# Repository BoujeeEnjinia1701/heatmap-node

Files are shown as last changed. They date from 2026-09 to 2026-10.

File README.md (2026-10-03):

# HeatMap Node

     

**Area:** Smart Cities · **TRL:** 3 of 9 (proof of concept on paper) · **Value-engineering target:** USD 130 for the sensor head; estimated cost of the constructable design USD 136 (FieldNode core and its pole adapter counted separately) · **Difficulty:** 2 of 5

A street-level heat and humidity node that measures heat stress (including a globe temperature) to map urban heat islands block by block.

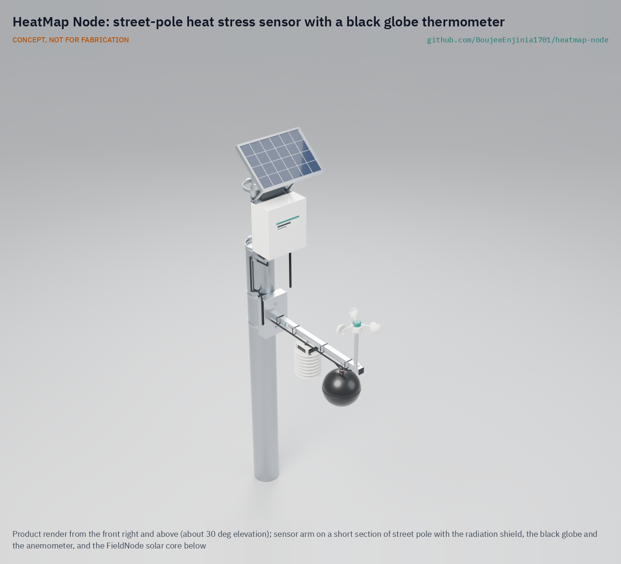
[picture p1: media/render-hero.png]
HeatMap Node: street-pole heat stress sensor with a black globe thermometer, product render


[Exploded render](media/render-exploded.png) · [Detail render](media/render-detail.png) · [Interactive 3D model](media/viewer.html) · [Concept blueprint (PDF)](media/concept-blueprint.pdf) · [General arrangement (PDF)](cad/drawings/HMN-DWG-001.pdf) · [Calculations](docs/04-calcs/01-sizing.md) · [Prototype build plan](docs/05-build-plan.md) · [Design decisions](docs/06-design-decisions.md) · [Review note](docs/REVIEW.md)

## Concept rationale

Block-level heat data lets a city put shade, trees, cool surfaces and cooling centers where they protect the most people, and then check whether they worked. Air temperature alone misses what makes a sunny street dangerous: radiant heat from the sun and from hot walls and pavement. HeatMap Node therefore measures what is needed to estimate the standard heat stress index, wet bulb globe temperature (WBGT, [ISO 7243:2017](https://www.iso.org/standard/67188.html)): air temperature, humidity, a black globe temperature and wind. WBGT is then estimated with a published open method ([Liljegren et al., 2008](https://doi.org/10.1080/15459620802310770)) instead of a wetted wick that would need refilling at every pole.

It is open and garage-buildable because mapping heat block by block takes many nodes, and the hottest neighborhoods are often the ones with the least money to buy them. The sensor head is a copper float ball, printed shield plates, an aluminium tube and off-the-shelf sensors, and it plugs into the lab's shared FieldNode core for solar power and LoRaWAN radio. Community groups, schools and cities can build, calibrate (with CalRig) and audit the same design, and the data stays open.

## Burning platform

WHO estimates about 489,000 heat-related deaths each year between 2000 and 2019, 45 % of them in Asia and 36 % in Europe ([WHO](https://www.who.int/news-room/fact-sheets/detail/climate-change-heat-and-health)). In one summer, 2022, an estimated 61,672 people died of heat across 35 European countries ([Ballester et al., *Nature Medicine*, 2023](https://www.nature.com/articles/s41591-023-02419-z)).

Cities concentrate the risk and spread it unevenly. The US EPA reports urban daytime temperatures about 1 to 7 °F (about 0.5 to 4 °C) above outlying areas ([US EPA](https://www.epa.gov/heatislands/learn-about-heat-islands)). Formerly redlined US neighborhoods have land surface temperatures about 2.6 °C higher than other neighborhoods, and up to 7 °C higher in some cities ([Hoffman et al., 2020](https://www.mdpi.com/2225-1154/8/1/12)). Official stations are too few to see these block-to-block differences, and satellites measure surfaces, not the heat a person on the pavement feels.

## Where it could be used

### By industry

| Industry | Use |
| --- | --- |
| Municipal climate and urban forestry | Target tree planting, shade (with CoolShade) and cool surfaces block by block, and measure the effect before and after |
| Public health | Neighborhood heat stress during heat waves to direct outreach and cooling center hours |
| Construction and outdoor work | Local WBGT estimates for work and rest planning on and near sites |
| Transit and school operators | Heat stress at bus stops, platforms and schoolyards |
| Urban design and real estate | Evidence for street and building design choices that reduce radiant heat |
| Research and education | A calibrated, repeatable street-level method for heat studies and classroom science |

### By country or region

| Country or region | Why it matters there |
| --- | --- |
| United States | In all but 6 of the 175 largest urbanized areas, the average person of color lives in a census tract with higher surface urban heat island intensity than non-Hispanic white residents ([Hsu et al., 2021](https://www.nature.com/articles/s41467-021-22799-5)) |
| Europe | About 61,672 heat-related deaths in summer 2022 across 35 countries ([Ballester et al., 2023](https://www.nature.com/articles/s41591-023-02419-z)); dense cities with older, unshaded streets need local evidence for cooling plans |
| South and Southeast Asia | Asia accounts for about 45 % of global heat-related deaths ([WHO](https://www.who.int/news-room/fact-sheets/detail/climate-change-heat-and-health)); rapidly growing cities include informal settlements that WHO notes are often hotter than other urban areas |
| Sub-Saharan Africa | Africa warmed by about 0.3 °C per decade over 1991 to 2022, and WMO describes big gaps in weather observations there ([WMO](https://wmo.int/news/media-centre/africa-suffers-disproportionately-from-climate-change)); low-cost nodes can add street-level data where stations are few |
| North Africa and the Middle East | WMO reports particularly rapid warming and extreme heat in North Africa ([WMO](https://wmo.int/news/media-centre/africa-suffers-disproportionately-from-climate-change)); outdoor workers and dense old cities face high radiant loads |

## What sparked the idea

The idea traces back to US Marine Corps training sites in the late 1940s and early 1950s. Heat flags were introduced there to address high rates of heat illness, but the temperature readings behind them did not account for sunlight or wind ([Human Performance Resource Center, US Department of Defense](https://www.hprc-online.org/physical-fitness/environmental-extremes/military-heat-flag-conditions-explained)). Yaglou and Minard's answer in 1957 was wet bulb globe temperature, which adds a black globe to catch the sun, and a review of the index's history records that it cut both heat casualties and lost training time ([Budd, *Journal of Science and Medicine in Sport*, 2008](https://doi.org/10.1016/j.jsams.2007.07.003)). HeatMap Node takes the same black globe, wind reading and shaded air temperature off the training ground and onto city street poles, where the neighborhoods hit hardest by heat are often the least measured.

## Problem

Heat waves kill more people than most other weather hazards, and cities lack fine-grained data on where heat is worst. Full problem statement: [docs/01-problem.md](docs/01-problem.md).

## Concept

A sensor arm clamps to an existing street pole with its axis at 2.8 m, points toward the equator and plugs into a FieldNode core (solar panel, LiFePO4 cell, LoRaWAN radio, and a sun shield for hot sites) mounted above it. It carries a fan-aspirated radiation shield with a temperature and humidity sensor, a standard 150 mm black globe with a thermistor at its center, and a small cup anemometer. Every 3 min the fan runs for 6 s before the air is read. Nodes send 15 min means; a server computes mean radiant temperature and WBGT, flags calm intervals below the anemometer's start-up, and maps the results block by block. Only environmental values leave the node: no camera, microphone or personal data.

TRL 3 calculations ([HMN-CAL-001](docs/04-calcs/01-sizing.md)): in a worked example, 35 °C air at 40 %RH with a 50 °C globe at 1 m/s gives a mean radiant temperature of 74.8 °C and WBGT of 31.7 °C. With the fan the shield reads 0.43 °C high in full sun at any wind speed (1.04 °C at 1 m/s without it), and the sensor input errors add up to ±0.30 °C of WBGT. The sensors and fan draw 35 mW against FieldNode's 100 mW allowance, the sensor head weighs 2.12 kg, and the arm has a factor of 13.0 on yield in a 35 m/s gust. Not met on paper: pedestrian measurement height (sensors at about 2.7 m). Value-engineering target: USD 130. Estimated cost of the constructable sensor head: USD 136 (USD 6 over the target); the full node with the FieldNode core, sun shield and pole adapter is about USD 292. WBGT accuracy against a reference meter, installation time and calibration of the assembled globe are at risk. With the arm toward the equator, the sensor head shades part of the FieldNode panel near noon; a fix is awaiting review.

Full design precis: [docs/02-concept.md](docs/02-concept.md). Requirements: [docs/03-requirements.md](docs/03-requirements.md).

## Key components

1. FieldNode core with its hot-climate sun shield (enclosure, 6 W panel, LiFePO4 cell, LoRaWAN radio)
2. Multi-plate radiation shield
3. Air temperature and humidity sensor (SHT45)
4. Black globe, 150 mm copper sphere, matte black
5. Globe temperature probe (NTC at the center)
6. Cup anemometer
7. Sensor arm, 25 mm aluminium tube
8. Arm clamp: formed sheet 120° V-saddle with stainless strap bands for 60 to 200 mm poles
9. Sensor harness with M12 plugs
10. Hardware and consumables
11. Secondary retention lanyards for the globe and shield
12. Pole adapter that seats the FieldNode core on street poles
13. Aspiration fan and cowl on the shield

The working bill of materials is in [bom/bom.csv](bom/bom.csv).

## Building the prototype

The design is now constructable: every part can be cut, bent, drilled, printed or bought, and every part fits and fastens to the next ([HMN-DDR-003](docs/decisions/0003-design-for-construction.md)). The [prototype build plan](docs/05-build-plan.md) shows how to make the bent sheet saddle, the arm cheeks, the drilled arm and the printed shield plates, cowl and pole adapter blocks, and how to put the sensor head together on the bench in twelve steps before it goes on the pole above a FieldNode core built to its own plan. Every component and step has a picture drawn from the model. Decisions still open are in the [design decisions register](docs/06-design-decisions.md). It is a plan; nothing has been built yet.

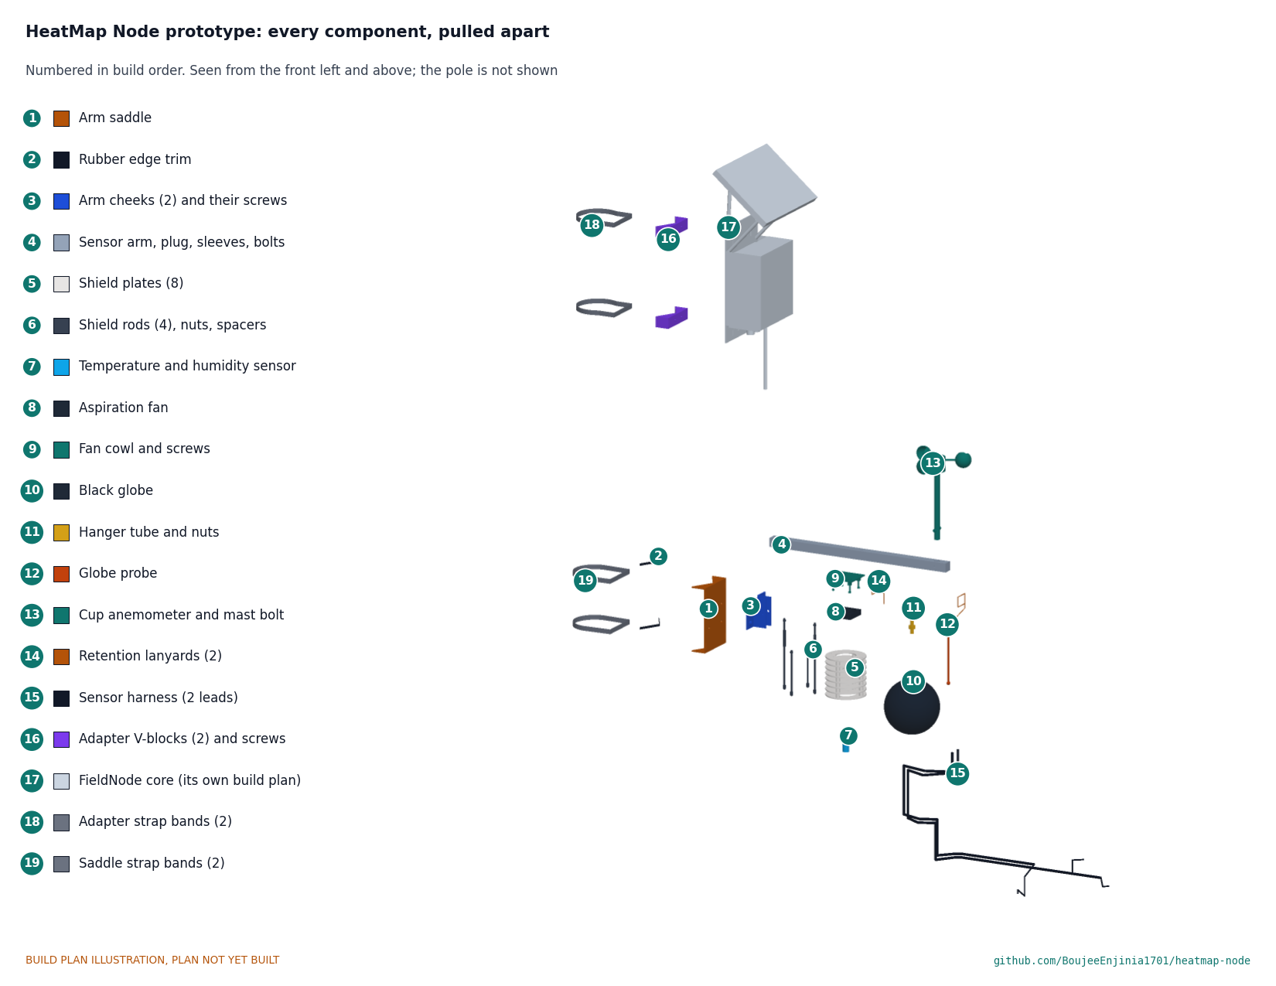
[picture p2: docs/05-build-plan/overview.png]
Every component of the HeatMap Node prototype, pulled apart and numbered in build order


## Safety

> Street furniture and pole mounts must be installed only with the asset owner's permission, by trained crews, with fall protection and traffic management as local rules require. Keep clear of overhead power lines and live parts of lighting poles.
>
> The FieldNode core contains a LiFePO4 cell: fuse it, charge only within the maker's temperature limits and never install a damaged or wet cell. The black globe and arm get hot in the sun (about 67 °C at 50 °C air, HMN-CAL-001), the anemometer cups spin, and the shield fan starts on its own every 3 min; unplug the sensor lead before working on it. The globe and shield are backed by stainless lanyards so that a failed fixing does not drop them onto the street.
>
> HeatMap Node data is for planning and research, not an official heat warning.

## Repository layout

| Folder | Contents |
| --- | --- |
| `docs/` | Problem, concept, requirements, calculations and design decisions |
| `cad/src/` | build123d Python source, the source of truth for all geometry |
| `cad/step/`, `cad/stl/` | Exported models for FreeCAD, other CAD tools and printing |
| `cad/drawings/` | 2D sketches and dimensioned drawings |
| `bom/` | Bill of materials |
| `electronics/` | KiCad schematics and PCB layouts |
| `firmware/` | Microcontroller code |
| `media/` | Renders, perspectives and photos |
| `build-log/` | Dated prototyping notes |

## Documentation

Controlled documents follow the portfolio [documentation standard](.kit/STANDARDS.md). Each carries a document ID (HMN-PRC-001 for the precis), a version and a revision history. Branded PDFs are built with `python .kit/render.py` and attached to GitHub Releases when a document is tagged, for example `HMN-PRC-001/v1.0`.

## Credits

Designed by Amish Chadha. See [CONTRIBUTORS.md](CONTRIBUTORS.md) for roles. To cite this design, use [CITATION.cff](CITATION.cff) (GitHub shows it as "Cite this repository").

AI assistance (Claude) was used to accelerate concept renders, prototype documentation and first-pass sizing calculations. Design direction and all decisions are Amish Chadha's, recorded in this repository's decision records (`docs/decisions/`).

## Licenses

- **Hardware** (CAD, drawings, BOM, electronics): [CERN-OHL-S v2](LICENSE)
- **Software** (firmware, scripts, notebooks): [MIT](LICENSE-SOFTWARE)

A project of the [Design Molecule](https://designmolecule.com) lab.

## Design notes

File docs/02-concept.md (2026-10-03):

---
doc_id: HMN-PRC-001
title: HeatMap Node design precis
project: HeatMap Node
doc_type: Design precis
version: "0.8"
status: Draft
date: '2026-10-02'
author: Amish Chadha
license: CERN-OHL-S-2.0
revisions:
- version: "0.1"
  date: '2026-09-25'
  author: Amish Chadha
  change: Initial scaffold
- version: "0.2"
  date: '2026-09-25'
  author: Amish Chadha
  change: Populate to TRL 2 (architecture, components, first-order numbers, safety, media, open questions)
- version: "0.3"
  date: '2026-09-25'
  author: Amish Chadha
  change: "TRL 3 update: design choices adopted per HMN-DDR-001; numbers checked against HMN-CAL-001; lanyards and FieldNode pole adapter added; parametric model and HMN-DWG-001"
- version: "0.4"
  date: '2026-09-25'
  author: Amish Chadha
  change: Recommendations accepted by Amish (DDR-002)
- version: "0.5"
  date: '2026-09-26'
  author: Amish Chadha
  change: "Budget top-up approved by Amish: sensor head within the $130 budget"
- version: "0.6"
  date: '2026-10-01'
  author: Amish Chadha
  change: "Design for construction (HMN-DDR-003): components, mass, wind and cost updated; budget reported as a value-engineering target; build plan HMN-BLD-001 added"
- version: "0.7"
  date: '2026-10-02'
  author: Amish Chadha
  change: "Core position and data publishing decided by Amish on 2026-10-02 (HMN-DEC-001)"
- version: "0.8"
  date: '2026-10-02'
  author: Amish Chadha
  change: "FieldNode core above the arm in the model and pictures (HMN-DEC-001, item 3); mass 2.08 kg"
---

# HeatMap Node design precis

## Summary

HeatMap Node is a sensor head that clamps to an existing street pole and plugs into the lab's FieldNode core. A horizontal arm, pointing toward the equator, holds a fan-aspirated radiation shield with an air temperature and humidity sensor, a standard 150 mm black globe with a thermistor at its center, and a small cup anemometer. From these four readings a server computes mean radiant temperature and an estimated wet bulb globe temperature (WBGT), the heat stress index defined in [ISO 7243:2017](https://www.iso.org/standard/67188.html), using the method of [Liljegren et al. (2008)](https://doi.org/10.1080/15459620802310770). Tens of nodes across a neighborhood give block-by-block heat stress maps, day and night, all season.

The TRL 3 calculations (HMN-CAL-001 v0.4) confirm the heat stress method and the power, data and wind cases. With the decisions Amish accepted on 2026-09-25 (HMN-DDR-001 and HMN-DDR-002) applied, one requirement is not met on paper: the sensors sit at about 2.7 m rather than pedestrian height (R9). The design for construction (HMN-DDR-003) made every part buildable; with the fan and the added fixings the sensor head is estimated at $136, $6 over its $130 value-engineering target (R13). The fan cuts the shield's radiation error from about 1.0 °C at 1 m/s to 0.43 °C at any wind speed, and the sensors and fan draw 35 mW. All design choices below are decided by Amish. The parametric model is `cad/src/model.py`, the general arrangement is drawing HMN-DWG-001 Rev P4, and the prototype build plan is [HMN-BLD-001](05-build-plan.md).

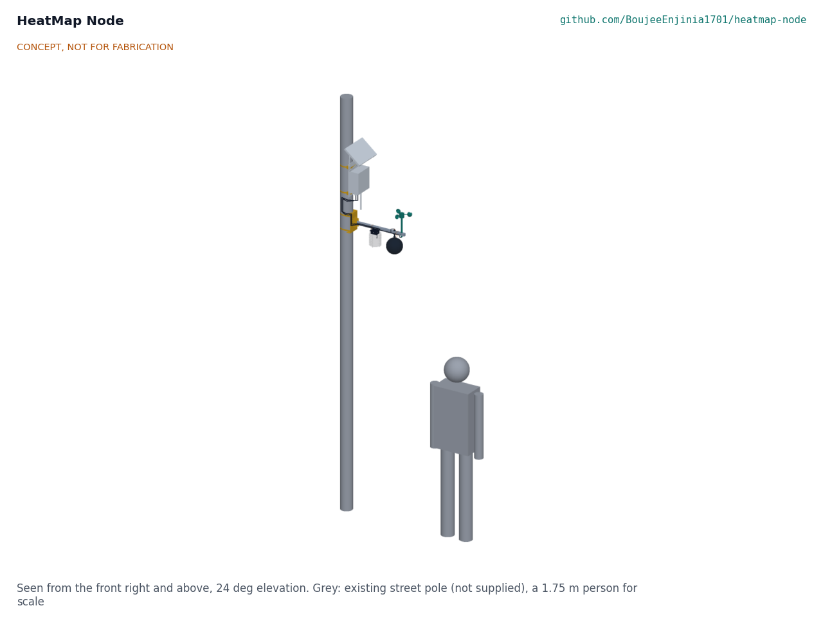
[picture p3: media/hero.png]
Hero render


*Figure 1. HeatMap Node on a 114 mm street pole, arm axis at 2.8 m pointing toward the equator, FieldNode core with its sun shield above the arm and facing the same way, with a 1.75 m person for scale. The pole is not supplied. CONCEPT, NOT FOR FABRICATION.*

## How it works

1. **Air temperature and humidity.** A digital sensor sits inside a stack of eight white plates that block direct and reflected sun while letting wind through. Every 3 min a small fan on the top plate runs for 6 s and draws air up past the sensor, which is read at the end of the run, so the reading does not depend on the wind (HMN-DDR-002).
2. **Radiant heat.** A thin copper sphere painted matte black reaches a balance between absorbed sun and long-wave radiation from hot walls and pavement and convective loss to the air. A thermistor at its center reads this globe temperature.
3. **Wind.** A cup anemometer gives the wind speed needed to separate radiant from convective heat at the globe. Below its start-up speed of about 0.8 m/s it reads zero; the node reports the share of each interval spent below start-up, and the server flags MRT and WBGT for any interval where that share is 20 % or more.
4. **Logging and radio.** The FieldNode core samples every 60 s, averages over 15 min, stores the means in flash and sends about 20 bytes by LoRaWAN to a gateway such as TwinKit. Missing packets are resent from flash.
5. **Heat stress and mapping.** A server script computes mean radiant temperature and WBGT and places each node on a block-level map, published as open data. Only environmental values leave the node.

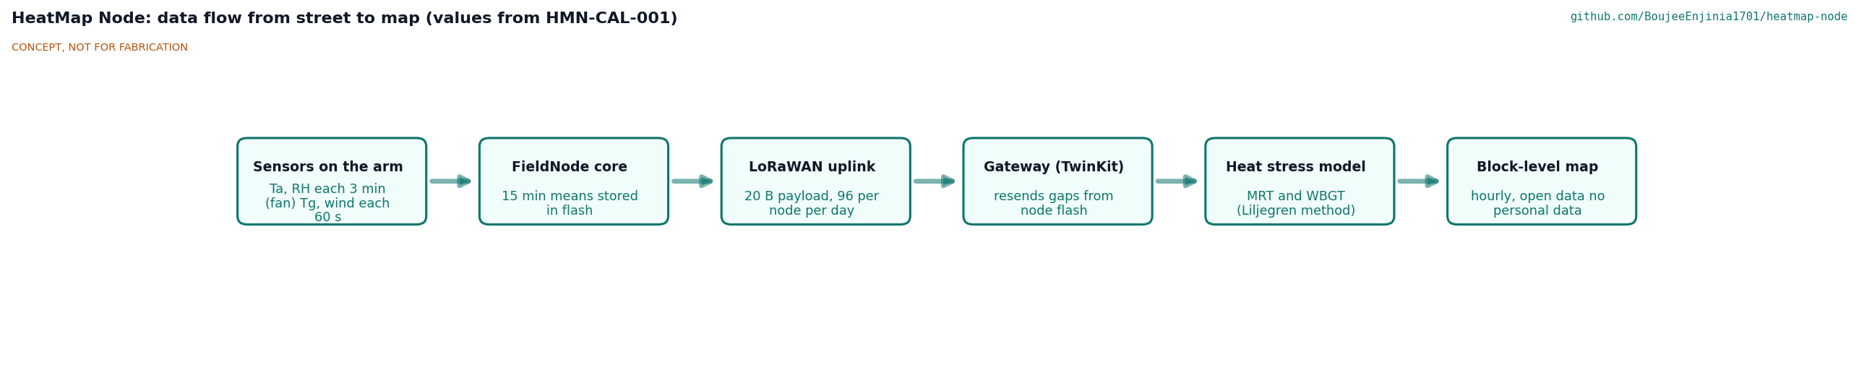
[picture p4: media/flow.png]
Data flow


*Figure 2. Data flow from the street to the map. All values are estimates.*

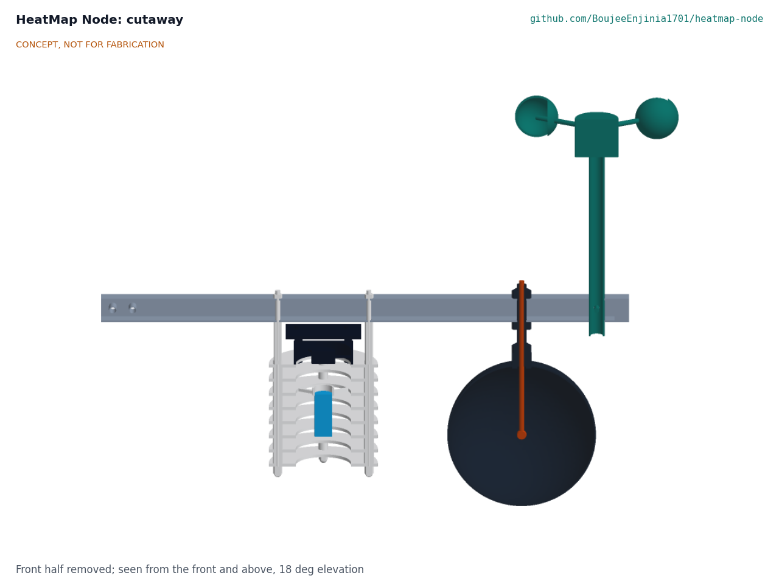
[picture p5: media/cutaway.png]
Cutaway


*Figure 3. Section through the sensor arm: temperature and humidity sensor inside the radiation shield, and the thermistor at the center of the globe.*

## Main components

Numbers match the exploded view (Figure 4) and `bom/bom.csv`. Line 10 (hardware) has no callout.

| # | Component | Choice (TRL 3) | Notes |
| --- | --- | --- | --- |
| 1 | FieldNode core | 150 x 90 x 200 mm IP65 enclosure with FieldNode's hot-climate sun shield, 6 W 9 V class panel as sun hood at 40°, 3.2 V 6 Ah LiFePO4 cell, MPPT board, STM32WL-class LoRaWAN module, two M12 ports (FND-DWG-001 Rev P3), built to FND-BLD-001 | Shared lab component, 2.61 kg, $148.00 with the shield (FND-CAL-001 v0.4); below the arm, facing the equator |
| 2 | Radiation shield | Eight 110 mm white plates at 15 mm pitch, printed UV-stable ASA with bosses between them, on four M5 rods; 56 mm hole in the top plate under the fan; hung from the arm on two of the rods | Aspirated by line 13 |
| 3 | Temperature and humidity sensor | SHT45 digital sensor (typical ±0.1 °C, ±1.0 %RH) with PTFE membrane cap | I2C over the M12 port |
| 4 | Black globe | 150 mm copper sphere, about 0.4 mm wall, matte black, hung on a hollow M10 brass tube through the arm | Standard globe size, so published globe equations apply |
| 5 | Globe probe | 10 k NTC bead at the globe center | Calibrated in CalRig |
| 6 | Cup anemometer | Three-cup, pulse output, its mast through the arm tip and pinned | Counted by the FieldNode low-power timer |
| 7 | Sensor arm | 25 mm square aluminium tube, 530 mm | Keeps globe and shield about 250 to 450 mm clear of the pole |
| 8 | Arm clamp | Channel 120 x 180 x 40 mm bent from 3 mm aluminium sheet, with 120° V notches in its flanges lined with rubber trim; two angle cheeks that hold the arm; two 13 mm stainless strap bands for 60 to 200 mm poles | No drilling of the pole |
| 9 | Sensor harness | Two M12 5-pin leads along the pole and arm | Plug-in at both ends |
| 11 | Secondary retention | Two 1.5 mm stainless lanyards, globe boss and shield top to the arm | Added at TRL 3 |
| 12 | FieldNode pole adapter | Two printed 120° V-blocks, fixed by FieldNode's own V-block screws, and strap bands, in place of FieldNode's own V-blocks | Added at TRL 3; FieldNode's kit seats only small poles; counted against FieldNode |
| 13 | Aspiration fan and cowl | 60 x 60 x 15 mm 5 V fan (about 0.9 W) on the top plate under a printed ASA cowl 76 x 76 x 30 mm, exhausting sideways under a solid lid | Added under HMN-DDR-002; 6 s every 3 min from FieldNode's switched 5 V rail |

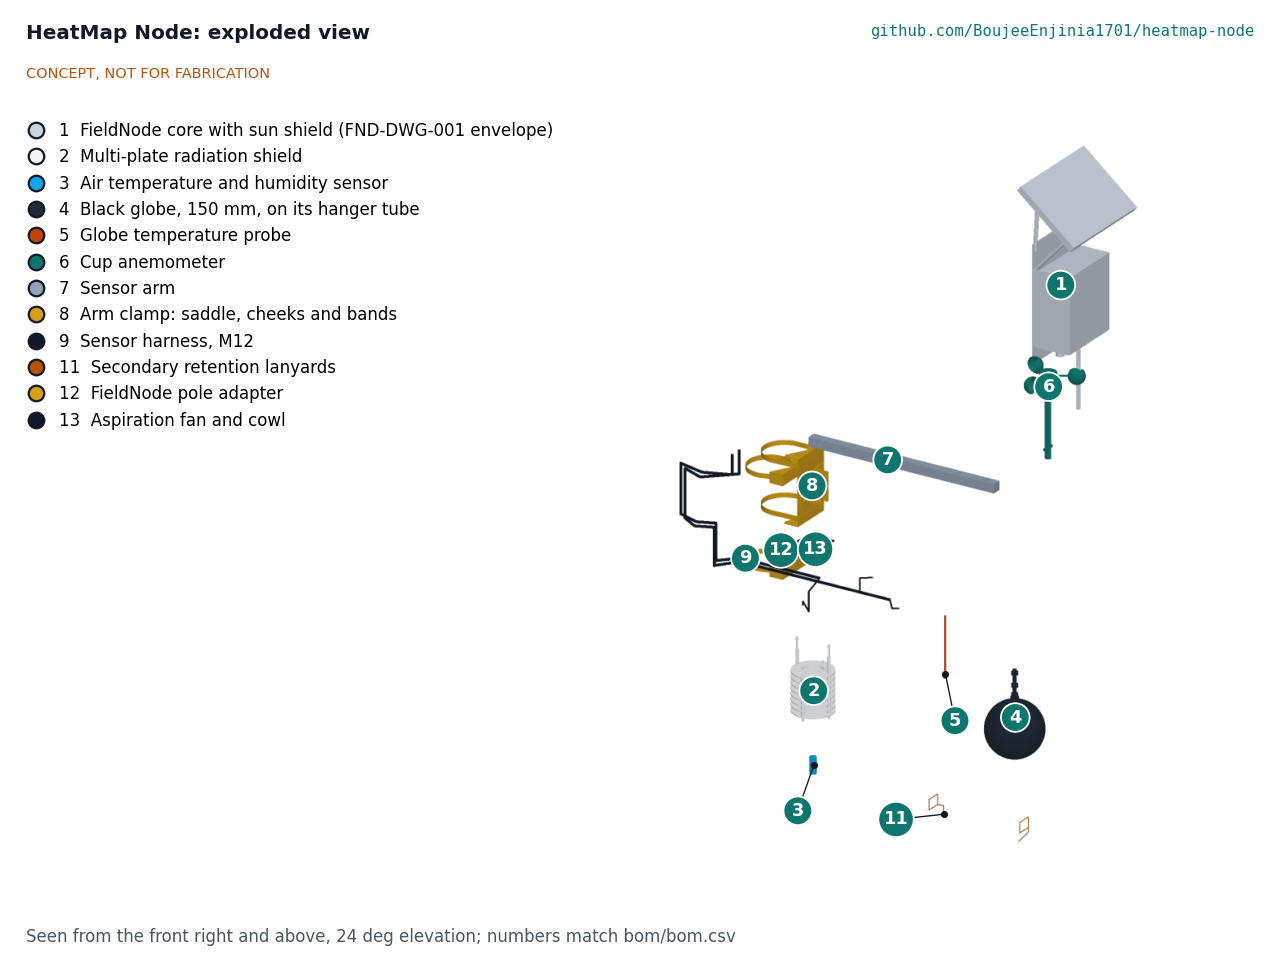
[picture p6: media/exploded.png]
Exploded view


*Figure 4. Exploded view with callouts matching the BOM.*

The blueprint sheet is in [media/concept-blueprint.pdf](../media/concept-blueprint.pdf) and an interactive model in [media/viewer.html](../media/viewer.html).

## First-order numbers

The TRL 2 estimates below have been checked in HMN-CAL-001, and the figures quoted here are from that note. They remain calculations, not measurements.

### From measurements to heat stress

For a standard globe under forced convection, mean radiant temperature (MRT) follows from globe temperature *T*g, air temperature *T*a, wind speed *v* (m/s), globe diameter *D* (m) and emissivity *ε*:

MRT = [(*T*g + 273)⁴ + 1.1 × 10⁸ *v*^0.6 / (*ε D*^0.4) × (*T*g - *T*a)]^0.25 - 273

This is the forced-convection form of the ISO 7726:1998 method, as implemented in the open [pythermalcomfort](https://pythermalcomfort.readthedocs.io/en/latest/reference/pythermalcomfort.html) library; below about 0.16 m/s in the example natural convection governs and the larger coefficient is used (HMN-CAL-001, section A). Outdoor WBGT is 0.7 *T*nwb + 0.2 *T*g + 0.1 *T*a ([ISO 7243:2017](https://www.iso.org/standard/67188.html)), where the natural wet-bulb temperature *T*nwb is estimated from the same four readings with the Liljegren method ([open implementation](https://github.com/mdljts/wbgt)).

**Worked example (assumptions: 35 °C air, 40 %RH, 50 °C globe, 1 m/s wind, *D* = 0.15 m, *ε* = 0.95).** MRT is 74.8 °C. The psychrometric wet bulb is 24.2 °C; a wick energy balance puts the natural wet bulb in sun at 26.0 °C, so WBGT is 0.7 × 26.0 + 0.2 × 50 + 0.1 × 35 = 31.7 °C (HMN-CAL-001, section B). Air temperature alone (35 °C) says nothing about the sun load that the globe captures.

**Sensitivity.** In the same example, a wind reading of 0.5 m/s instead of 1 m/s lowers MRT to 66.9 °C, and 1.5 m/s raises it to 80.7 °C. A 1 °C air temperature error moves MRT by 1.5 °C. Below the anemometer's start-up speed (about 0.8 m/s) the node reads zero wind, which at a true 0.5 m/s puts MRT 8.2 °C low and WBGT 0.9 °C high. With the fan-aspirated shield the input errors add up to ±0.30 °C of WBGT (±0.59 °C with the passive shield at 1 m/s); air temperature is still the largest term, at 0.43 °C of shield error (HMN-CAL-001, sections B and C).

### Power

The temperature and humidity sensor, read every 3 min at the end of a fan run, takes about 11 µJ per reading and the switched thermistor divider, read every minute, about 8 µJ. The anemometer pulses are counted by a low-power timer; with a 100 kΩ pull-up the worst case (reed contact resting closed) is 0.109 mW. The sensors draw 0.116 mW. The fan (0.9 W for 6 s every 180 s, through an 85 % efficient 5 V rail) adds 35.3 mW, for a total of 35.4 mW, 35 % of the 100 mW design allowance in FND-CAL-001. With the core below the arm and both facing the equator, the shield, globe and arm shade 16 to 44 % of the FieldNode panel near noon (HMN-CAL-001, section E), which this budget does not include; see the review note.

### Radio

At the 15 min default, each node sends 96 uplinks of 20 bytes a day (eleven fields, including the share of each interval below the anemometer's start-up), 23.7 s/day of airtime at SF9 (FND-CAL-001). Seven days of records at FieldNode's 32 B each take 21.5 kB of its 16 MB flash.

### Wind load and mass

At a 35 m/s gust (750 Pa) the sensor head carries 46.5 N (globe 6.6 N, shield 10.7 N, fan cowl 2.1 N, anemometer 7.2 N, arm 19.9 N) and the FieldNode core with its sun shield 88 N (FND-CAL-001 v0.2). The arm root sees 14.6 N·m and 11.1 MPa, a factor of 13.0 on yield; the tip deflects 0.31 mm at 20 m/s. The clamp's band friction resists the twist with a factor of 2.5 at the assumed 1,000 N preload. The node adds about 338 N·m at the pole base, which the pole owner should check.

The sensor head weighs 2.08 kg (clamp 0.44 kg, globe with its hanger 0.35 kg, shield 0.32 kg, anemometer 0.31 kg, harness 0.24 kg, arm 0.27 kg, fan and cowl 0.08 kg and small parts), within the 4 kg of R15, which now applies to the sensor head. With the FieldNode core and shield (2.61 kg) and the pole adapter (0.22 kg) the complete node weighs 4.92 kg.

### Cost

`budget_usd` is a hypothetical value-engineering target, not a spending limit (Amish, 2026-10-01). Value-engineering target: USD 130 for the sensor head. Estimated cost of the constructable design: USD 136 (USD 6 over the target), from BOM lines 2 to 11 and 13. The FieldNode core with its sun shield ($148.00) and the pole adapter ($8.00) are counted against FieldNode, and the full node costs about $292.00. The fan and cowl added $7 in HMN-DDR-002 and the fixings that make the node buildable a further $9 (HMN-DDR-003); the cost drivers and savings worth trying are in the design decisions register (HMN-DEC-001).

## Key design choices

Decided by Amish, 2026-09-25 (HMN-DDR-001 and HMN-DDR-002).

1. **Build on FieldNode** rather than a separate power and radio design, with a TwinKit gateway or a public LoRaWAN network (D7). Reuses a shared core, costed in its own repo (D1), fitted with FieldNode's hot-climate sun shield so that it stays within its rating at +50 °C.
2. **Standard 150 mm globe** rather than a 38 to 40 mm table tennis ball globe. The standard size matches published globe equations and the Liljegren model; the small globe is cheaper and faster to respond but more sensitive to wind and less comparable.
3. **Derived WBGT** rather than a wetted natural wet-bulb sensor, which needs a water reservoir and wick care at every node.
4. **Fit a cup anemometer** rather than use wind from the nearest official station, because street wind differs strongly from airport wind and MRT is sensitive to it. Its range starts at about 0.8 m/s, and calm intervals are flagged rather than corrected.
5. **Fan-aspirated shield**, run 6 s before each reading every 3 min, rather than a naturally ventilated shield, which reads about 1 °C high in full sun at 1 m/s. The fan adds 35 mW, a wear part and $7.
6. **Arm at about 2.8 m** to deter tampering (D2), with a correction to pedestrian height (HMN-CAL-001 estimates 0.2 to 0.8 °C in strong sun) and a later pilot comparing 2.0 and 2.8 m (TRL 4, on hold), rather than at 1.5 to 2 m where the data is most representative (R9 not met).
7. **Arm toward the equator**, so the pole does not shade the globe near midday. With the FieldNode core below the arm, HMN-CAL-001 found that the sensor head shaded part of the FieldNode panel. Amish decided on 2026-10-02 to mount the core above the arm, provided its lid stays reachable from the ladder or lift used to fit the arm, and otherwise on the pole's east or west face (HMN-DEC-001). The model and build plan now have the core above the arm, its bottom at 3.11 m, and the head shades none of the panel; the panel and core can shade the sensors only with the sun on the pole side, in the tropics near noon (HMN-CAL-001 E3b).
8. **Open data, environmental channels only** (R12, D8). The data go through a TwinKit gateway and are published from CityTwin's open data export under an open licence, with Amish's lab as publisher until the partner city takes it over (decided 2026-10-02, HMN-DEC-001).

## Safety

> **Safety:** Mounting on street poles is work at height next to traffic. Install only with the pole owner's written permission, by trained crews, with a stable ladder or lift, fall protection and traffic management as local rules require, and keep clear of overhead power lines and any live parts of lighting poles. Check that the pole can carry the added wind load.
>
> **Safety:** The FieldNode core contains a LiFePO4 cell of about 19 Wh. Fuse it at the holder, charge only within the maker's temperature limits, and do not install a swollen, damaged or wet cell.
>
> **Safety:** The globe and the shield hang from the arm on fixings backed by stainless lanyards, so a failed fixing does not drop a part onto the street. Check the fixings and lanyards at every visit.
>
> **Safety:** The black globe can reach about 67 °C at 50 °C air in full sun (HMN-CAL-001), and the arm runs hot too. Let them cool or wear gloves before handling. Cut edges on the aluminium arm, formed saddle and copper sphere must be deburred. The anemometer cups spin and the shield fan starts on its own every 3 min; stop the cups and unplug the sensor lead before working near them.
>
> **Safety:** HeatMap Node data is for planning and research. It is not an official heat warning, and it must not be used to decide whether a particular person is safe to work or exercise without the responsible agency's guidance.

## Open questions

- [x] Budget: `budget_usd` ($130) is a value-engineering target; the constructable sensor head is estimated at $136.
- [x] Panel shading: the sensor head shades 16 to 44 % of the FieldNode panel near noon with the arm toward the equator; where should the core go? Decided 2026-10-02: above the arm if its lid stays reachable, otherwise on the pole's east or west face (HMN-DEC-001).
- [ ] Mounting height: what do pole owners allow? The calculated difference (0.2 to 0.8 °C) needs a field comparison.
- [ ] Fan: does a chosen 60 mm fan deliver the 3.4 L/s through the stack that ±0.5 °C needs, and how long does it last outdoors?
- [ ] Globe response: HMN-CAL-001 estimates about 12 min to 90 %, faster than the TRL 2 estimate; a step test is needed.
- [ ] How often must nodes be recalibrated in CalRig, and how are dust and fading of the black paint handled?
- [x] Data model and hosting: TwinKit, CityTwin or a public platform, and who publishes it? Decided 2026-10-02: through a TwinKit gateway, published from CityTwin's open data export under an open licence, with Amish's lab as publisher until the partner city takes it over, and mirrored on the city's own open data portal if it has one (HMN-DEC-001).
- [ ] Night-time value: are 15 min means enough to capture nights that do not cool, when the body cannot recover from daytime heat?

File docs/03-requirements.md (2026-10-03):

---
doc_id: HMN-REQ-001
title: HeatMap Node requirements
project: HeatMap Node
doc_type: Requirements
version: "0.7"
status: Draft
date: '2026-10-02'
author: Amish Chadha
license: CERN-OHL-S-2.0
revisions:
- version: "0.1"
  date: '2026-09-25'
  author: Amish Chadha
  change: Initial scaffold
- version: "0.2"
  date: '2026-09-25'
  author: Amish Chadha
  change: First measurable requirements for TRL 2, with status against the concept estimates
- version: "0.3"
  date: '2026-09-25'
  author: Amish Chadha
  change: "TRL 3: R13 redefined to the sensor head per HMN-DDR-001 D1; status table replaced by the results of HMN-CAL-001"
- version: "0.4"
  date: '2026-09-25'
  author: Amish Chadha
  change: Recommendations accepted by Amish (DDR-002)
- version: "0.5"
  date: '2026-09-26'
  author: Amish Chadha
  change: Budget top-up approved by Amish
- version: "0.6"
  date: '2026-10-01'
  author: Amish Chadha
  change: Status from HMN-CAL-001 v0.4 after the design for construction (HMN-DDR-003); R13 reported against the value-engineering target
- version: "0.7"
  date: '2026-10-02'
  author: Amish Chadha
  change: "Core above the arm carried into the model (2026-10-02): R7 note, R15 mass 2.08 kg head and 4.92 kg node; no status changes"
---

# HeatMap Node requirements

These are first-pass requirements for the concept. Targets are not yet validated with users and will be revised after co-design sessions (see HMN-PRB-001). Version 0.4 applies the decisions Amish accepted on 2026-09-25 (HMN-DDR-001 and HMN-DDR-002): R4 now covers 0.8 to 20 m/s with calm intervals flagged, R8 now asks for +50 °C at the node, R13 now excludes the FieldNode core and its pole adapter, and R15 now applies to the sensor head only. R1 keeps its ±0.5 °C target, which the fan-aspirated shield is meant to meet. Version 0.5 raises the R13 target from $120 to $130 after Amish approved the budget top-up on 2026-09-26 (HMN-DDR-002 v0.2). Version 0.6 takes its status from HMN-CAL-001 v0.4, after the design for construction (HMN-DDR-003), and reports R13 against `budget_usd`, which Amish confirmed on 2026-10-01 is a hypothetical value-engineering target, not a spending limit. Nothing has been tested.

One requirement is **not met** on paper (R9), three are **at risk** (R5, R10 and R14), eight are met on paper and two are met by design. The sensor head's estimated cost is $6 over its value-engineering target (R13). See Table 2.

*Table 1. Requirements.*

| ID | Requirement | Target | Verification (TRL 3 or later) |
| --- | --- | --- | --- |
| R1 | Air temperature accuracy in the street | ±0.5 °C against a reference aspirated thermometer, in full sun at wind speeds of 1 m/s or more; ±1.0 °C below 1 m/s (met at all wind speeds with the fan-aspirated shield, HMN-DDR-002) | Shield error estimate; later side-by-side field comparison |
| R2 | Relative humidity accuracy | ±3 %RH from 20 to 80 %RH at 15 to 40 °C | Datasheet; CalRig salt fixed points |
| R3 | Globe temperature | Standard 150 mm black globe (emissivity about 0.95); probe ±0.3 °C after calibration; 90 % response within 30 min | Calibration in CalRig; response estimate |
| R4 | Wind speed | 0.8 to 20 m/s; ±0.5 m/s or ±10 %, whichever is larger; the share of each interval below the start-up speed is reported so that the server can flag biased intervals (restated under HMN-DDR-002; was 0.5 to 20 m/s) | Datasheet of the chosen anemometer; later wind comparison |
| R5 | Derived heat stress | Mean radiant temperature and outdoor WBGT computed per ISO 7243 definitions with the Liljegren method; WBGT within ±1.0 °C of a reference WBGT meter | Calculation note; later collocation with a reference meter |
| R6 | Reporting | 15 min means of all channels by default (adjustable 5 to 60 min); data at the gateway within 30 min; 7 days stored on the node for resend | FieldNode firmware design; airtime calculation |
| R7 | Power autonomy | No mains; 5 days without sun at the default reporting interval | FieldNode energy budget plus the sensor load in HMN-PRC-001 |
| R8 | Outdoor survival | Electronics IP65; operate at -20 to +50 °C at the node (restated under HMN-DDR-002, was +60 °C), with FieldNode's hot-climate sun shield on the core; UV-stable plastics; sensors survive driving rain and dust | Design review; datasheets |
| R9 | Measurement height | Sensors at pedestrian height (1.1 to 2.0 m) | Mounting review with pole owners |
| R10 | Fit to existing poles | Stainless band clamps for 60 to 200 mm round poles; no drilling; fitted from a ladder or lift by two people in 30 min or less | Design review; later timed trial |
| R11 | Wind survival | No failure at a 35 m/s gust; arm deflection under 10 mm at 20 m/s | Wind load calculation |
| R12 | Privacy | Environmental data only: no camera, microphone, Wi-Fi or Bluetooth scanning, or any personal data | Design review of hardware and firmware |
| R13 | Cost | Sensor head (all parts except the FieldNode core and its pole adapter) against a value-engineering target of $130 (raised from $120 under HMN-DDR-002 v0.2, budget top-up approved by Amish on 2026-09-26), the `budget_usd` in `project.yaml`; the target is a hypothetical control target, and cost is reported as over or under it. The FieldNode core, its sun shield and the pole adapter are counted against FieldNode (HMN-DDR-001 D1, HMN-DDR-002); the full-node cost is reported for information | Priced BOM |
| R14 | Traceable data | Each node carries a calibration record from CalRig; readings published in an open, documented format with node location and height | Documentation review |
| R15 | Mass and loading on the pole | 4 kg or less for the sensor head (restated under HMN-DDR-002, was the complete node); the complete-node mass is reported for the pole owner; no part larger than 300 mm across other than the arm | Mass estimate |

*Table 2. Status from HMN-CAL-001 v0.4 (TRL 3 calculations), not met first.*

| ID | Value (HMN-CAL-001) | Status |
| --- | --- | --- |
| R9 | Sensors at 2.67 to 2.69 m; pedestrian-height air 0.2 to 0.8 °C warmer in strong sun | **Not met** |
| R5 | Input error ±0.30 °C RSS, ±0.55 °C worst case with the fan; calm intervals flagged; Liljegren model error unknown | **At risk** |
| R10 | 120° V-saddle fits 60 to 200 mm; 37 min estimated | **At risk** (time) |
| R14 | Probe calibrated before fitting fits a CalRig bay; the assembled 150 mm globe does not; payload format defined | **At risk** |
| R1 | 0.43 °C with the fan at any wind speed; 1.04 °C at 1 m/s with the fan off | Met on paper (fan flow assumed) |
| R3 | Probe ±0.18 °C (±0.26 °C with a maximum-tolerance reference); 90 % response about 12 min | Met on paper |
| R4 | Start-up about 0.8 m/s (typical, unverified); calm share reported and flagged at 20 % of an interval | Met on paper (start-up unverified) |
| R6 | 20 B payload; 23.7 s/day at SF9; 7 days in 21.5 kB; 16 min latency for 99 % of intervals | Met on paper |
| R7 | Sensors and fan 35.4 mW, 35 % of FieldNode's 100 mW design allowance | Met on paper (the head no longer shades the panel) |
| R8 | FieldNode interior 57.2 °C at 50 °C air with its sun shield, against 70 °C; sensor head parts within ratings | Met on paper (shield factor assumed) |
| R11 | Arm factor 13.0 on yield; 0.31 mm at 20 m/s; clamp twist factor 2.5 | Met on paper (preload assumed) |
| R13 | Value-engineering target: USD 130. Estimated cost of the constructable design: USD 136 (USD 6 over the target). FieldNode core with shield and adapter $156.00; full node $292.00 | Over the target by $6.00 |
| R15 | Sensor head 2.08 kg; complete node 4.92 kg for information; largest part 290 mm | Met on paper |
| R2 | SHT45 ±1.0 %RH typical | Met by design |
| R12 | No imaging, audio or radio scanning parts; environmental payload only | Met by design |

## Assumptions

- The FieldNode core performs as stated in FND-CAL-001 (100 mW design sensor allowance, 5.75 days without sun at that load; hot-climate node with the sun shield 2.61 kg, $148.00 after its design for construction, FND-DDR-003).
- WBGT is derived, not measured with a wetted wick, because a natural wet-bulb sensor needs a water reservoir that would need refilling at every node.
- Pole owners permit clamped attachments at the proposed height.

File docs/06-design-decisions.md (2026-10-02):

---
doc_id: HMN-DEC-001
title: HeatMap Node design decisions register
project: HeatMap Node
doc_type: Design decisions register
version: "0.2"
status: Draft
date: '2026-10-02'
author: Amish Chadha
license: CERN-OHL-S-2.0
revisions:
  - version: "0.1"
    date: '2026-10-01'
    author: Amish Chadha
    change: Register opened with the build plan; open decisions, items to confirm, value engineering and decisions made
  - version: "0.2"
    date: '2026-10-02'
    author: Amish Chadha
    change: "Amish approved the recommendations for all nine open decisions (HMN-DDR-003 accepted); moved to decisions made"
---

# HeatMap Node design decisions register

Every design decision still to be made, and every decision made, in one place. Each decision is argued in full in its decision record under `docs/decisions/`; this register is the index Amish works from. The build plan (`docs/05-build-plan.md`) describes the design as it stands and does not list open decisions.

## Open decisions

None. All open decisions were decided on 2026-10-02.

## To confirm when parts are bought

| # | What to confirm | Why it matters | Source |
| --- | --- | --- | --- |
| 1 | The globe's top boss is threaded M10 x 1, or an M10 x 1 adapter fits it, and the boss is soldered strongly enough to hang the globe | The hanger tube screws into the boss; the lanyard backs it up | HMN-DDR-003, P7 |
| 2 | The anemometer's mast is a 16 mm tube that can be drilled for a 5 mm pin, and its cable leaves at the foot of the mast | The mast passes through 16.5 mm holes in the arm and is pinned | HMN-DDR-003, P8 |
| 3 | The fan's corner holes are on a 50 mm square and take M4 screws | The cowl legs, the fan and the top plate share four screws | HMN-DDR-003, P5 |
| 4 | The temperature and humidity capsule is 18 mm across and at least 45 mm long | It is a push fit in the 18.5 mm hub | HMN-DDR-003, P6 |
| 5 | Rubber edge trim for 3 mm sheet with about 1.5 mm of rubber on the bearing edge | Sets where the pole bears in the V | HMN-DDR-003, P1 |
| 6 | Strap band width (13 mm) and buckle size suit the 16 mm slots, and the band tool gives the 1,000 N preload the clamp check assumes | The twist factor of 2.5 rests on that preload | HMN-CAL-001 [H5] |
| 7 | The FieldNode back plate's band slots (51 mm each side of centre) and V-block screw holes (18 mm each side) are as in FND-DWG-101 | The adapter V-blocks are drilled and slotted to match | FND-DDR-003; HMN-DDR-003, P12 |
| 8 | The heat-set inserts' hole size for the printer and filament used | The adapter blocks carry the FieldNode core through them | HMN-DDR-003, P12 |

## Value engineering

Value-engineering target: USD 130 for the sensor head (a hypothetical control target, not a limit). Estimated cost of the constructable design: USD 136 (USD 6 over the target). The FieldNode core with its sun shield and the pole adapter (USD 156) are counted against FieldNode; the full node is USD 292, for information. Main cost drivers and savings worth trying:

- The largest lines are the cup anemometer (USD 32), the globe with its hanger tube (USD 24), the shield (USD 15), the temperature and humidity sensor (USD 14) and the harness (USD 12); these five are 71 % of the head.
- Making the design constructable added USD 9: cheeks, wider sheet and trim on the saddle (USD 3), the M10 hanger tube and nuts (USD 2), a fourth rod and two spacers (USD 1), and bolts, sleeves, a plug and long cable ties (USD 3).
- Savings worth trying: one 8-pin lead in place of two 5-pin leads, if FieldNode's port design allows it (about USD 4); a float ball bought with a threaded boss already fitted, avoiding an adapter; printing the cheeks in ASA is not recommended, since they carry the arm.

## Decisions made

| Date | Decision | Decided by | Record |
| --- | --- | --- | --- |
| 2026-09-25 | TRL 2 items D1 to D8: budget covers the sensor head only; arm at about 2.8 m with a height correction; 150 mm globe; cup anemometer; WBGT derived by the Liljegren method; FieldNode core with TwinKit or a public LoRaWAN network; open data, environmental channels only (D5, passive shield, later superseded by N2) | Amish: "i accept all your recommendations, go with them across all repos." | HMN-DDR-001, HMN-DDR-002 |
| 2026-09-25 | N1: pole adapter counted against FieldNode and a formed 3 mm sheet saddle | Amish, same instruction | HMN-DDR-002 |
| 2026-09-25 | N2: fan-aspirated shield, run 6 s before each reading every 3 min | Amish, same instruction | HMN-DDR-002 |
| 2026-09-25 | N3: R15 mass limit applies to the sensor head only | Amish, same instruction | HMN-DDR-002 |
| 2026-09-25 | N4: R8 at +50 °C and FieldNode's hot-climate sun shield on HeatMap nodes | Amish, same instruction | HMN-DDR-002 |
| 2026-09-25 | N5: arm toward the equator with the FieldNode core below it | Amish, same instruction | HMN-DDR-002 |
| 2026-09-25 | N6: R4 restated to 0.8 to 20 m/s with calm intervals flagged | Amish, same instruction | HMN-DDR-002 |
| 2026-09-26 | N7: `budget_usd` raised from $120 to $130 | Amish: "I am ok with the budget top ups" | HMN-DDR-002 v0.2 |
| 2026-10-01 | `budget_usd` is a hypothetical value-engineering target, not a limit; cost is reported against it | Amish: "the budgets are a hypothethical control target to ensure we are thinking along a value engineering lens. its ok to ensure wording reflects that the hypothesis budget was x - the real cost being accrued is y" | This register; HMN-CAL-001 v0.4 |
| 2026-10-02 | Design for construction accepted: the thirteen changes of HMN-DDR-003 as made, including the arm end cap of the 2026-09-26 appearance review (P9) (open item 1) | Amish: "i approve your recommendations for all 555 open decisions." | HMN-DDR-003, Table 1 |
| 2026-10-02 | Sensor hub kept on three spokes (option a) and included in the TRL 4 side-by-side shield test (open item 2) | Amish: "i approve your recommendations for all 555 open decisions." | HMN-DDR-003, A1 |
| 2026-10-02 | FieldNode core mounted above the arm (option a), provided its lid stays reachable from the ladder or lift used to fit the arm; if not, the core goes on the pole's east or west face (option c) (open item 3) | Amish: "i approve your recommendations for all 555 open decisions." | HMN-DDR-002, N8; HMN-CAL-001 [E3] |
| 2026-10-02 | First partner and city: a hot US city with a dedicated heat office; first candidate to approach the City of Phoenix Office of Heat Response and Mitigation, using the US915 band (open item 4) | Amish: "i approve your recommendations for all 555 open decisions." | HMN-DDR-001, O1 |
| 2026-10-02 | Data routed through a TwinKit gateway and published from CityTwin's open data export under an open licence, with Amish's lab as publisher until the partner city takes it over; mirrored on the city's own open data portal if it has one (open item 5) | Amish: "i approve your recommendations for all 555 open decisions." | HMN-DDR-001, O2 |
| 2026-10-02 | Sensor ports follow FieldNode's candidate pinout: port A, the I2C sensor on data pins 2 and 4 with sensor and fan on the switched rail; port B, the thermistor on analog pin 5 and the anemometer pulse on pin 2 (open item 6) | Amish: "i approve your recommendations for all 555 open decisions." | FieldNode FND-DDR-001, O2; HMN-DDR-002 cross-repo actions |
| 2026-10-02 | FieldNode internals kept as stand-ins in the appearance model; the FieldNode repo is asked to confirm the cell format and board position at its next update (open item 7) | Amish: "i approve your recommendations for all 555 open decisions." | REVIEW.md, 2026-09-26 |
| 2026-10-02 | Name plate kept on the FieldNode sun shield; side vent slots dropped unless FieldNode adopts them (open item 8) | Amish: "i approve your recommendations for all 555 open decisions." | REVIEW.md, 2026-09-26 |
| 2026-10-02 | Raised seam ring at the globe equator accepted for appearance (open item 9) | Amish: "i approve your recommendations for all 555 open decisions." | REVIEW.md, 2026-09-26 |

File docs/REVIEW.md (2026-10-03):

# Review note: HeatMap Node

## Session 2026-09-25: /populate to a strong TRL 2

### What was done

- `docs/01-problem.md` (HMN-PRB-001 v0.2): problem with cited figures, users, operating environment, constraints, out of scope, prior work, open questions; co-design checklist kept.
- `docs/03-requirements.md` (HMN-REQ-001 v0.2): 15 measurable requirements (R1 to R15) and a status table against the concept estimates.
- `docs/02-concept.md` (HMN-PRC-001 v0.2): how it works, numbered components, globe-to-MRT and WBGT method with a worked example and sensitivity, power, radio, wind load, mass, cost, design choices, safety, open questions.
- `cad/src/concept_media.py`: massing model of the sensor arm, shield, globe, probe, anemometer, clamp, harness and FieldNode core on a 114 mm street pole. The pole and a 1.75 m person are context parts (hero and isometric only), so the exploded and cutaway views stay readable. The model is shifted so the arm sits at Z = 0 because the kit's cutaway cutter is centered on Z = 0; ground is at Z = -2.8 m.
- `media/`: hero, concept blueprint (PNG, PDF, SVG), cutaway (sensor in shield, probe in globe), exploded view with BOM callouts 1 to 9, data flow diagram (values labeled as estimates), `model.glb` and `viewer.html`. Temporary `_views` folders removed.
- `bom/bom.csv` (10 lines, indicative prices) and `bom/bom-notes.md`.
- `README.md`: hero and links line; Concept rationale, Burning platform, Where it could be used (industry and region tables), What sparked the idea expanded with cited sources; Problem, Concept, Key components and Safety updated.
- `docs/pdf/`: branded PDFs of the three controlled documents.
- `project.yaml`: unchanged (pitch and problem remain consistent with the sources found).

### Key results (estimates, to be checked at TRL 3)

| Quantity | Estimate | Requirement |
| --- | --- | --- |
| Worked example (35 °C, 40 %RH, 50 °C globe, 1 m/s) | MRT about 75 °C; WBGT about 31 °C | R5 |
| MRT sensitivity to wind (0.5 / 1.5 m/s instead of 1 m/s) | about 67 / 80 °C | R4, R5 at risk |
| Sensor power | under 1 mW, against about 115 mW FieldNode allowance | R7 met |
| Radio | 96 uplinks of about 20 B a day; 7 days of data about 13 kB | R6 met |
| Wind load at 35 m/s | about 110 N total; about 17 N·m at the arm root | R11 met by estimate |
| Mass | about 3.3 kg | R15 met |
| Arm height | about 2.8 m | **R9 not met** |
| Sensor head cost (BOM lines 2 to 10) | about $120 | R13 met with no margin |
| Full node cost with FieldNode core | about $246 | **R13 not met, about twice the $120 budget** |

Requirements not met: **R4** (anemometer start-up about 0.8 m/s, above the 0.5 m/s target), **R9** (sensors not at pedestrian height), **R13** (full node cost). At risk: **R1** (passive shield error in calm sun), **R5** (WBGT accuracy in calm air), **R15** (if a larger panel is needed).

### Proposed, awaiting Amish

1. **Budget (R13).** Options: (a) count the FieldNode core as a shared component budgeted in its own repo, and hold HeatMap Node's $120 to the sensor head (about $120 now); (b) raise `budget_usd` to about $250 for a full node; (c) cut the head to about $70 by dropping the anemometer and using a table tennis ball globe, at a large accuracy cost. Recommendation: (a), with R13 reworded to "sensor head $120 or less". `project.yaml` is unchanged. **Decided by Amish, 2026-09-25: go with recommendation.**
2. **Measurement height (R9).** Options: (a) arm at about 2.8 m with a height correction studied at TRL 3; (b) arm at 2.0 m with tamper-resistant fixings; (c) 1.5 to 2.0 m only on private or school poles. Recommendation: (a) for city poles, with a short pilot comparing 2.0 and 2.8 m. **Decided by Amish, 2026-09-25: go with recommendation.**
3. **Globe size.** 150 mm standard globe (recommended) or a 38 to 40 mm painted table tennis ball globe (cheaper, faster, less comparable). **Decided by Amish, 2026-09-25: go with recommendation.**
4. **Wind.** Fit a cup anemometer (recommended), use a sonic anemometer (better calm-air response, several times the cost) or borrow wind from the nearest official station (cheapest, least accurate). **Decided by Amish, 2026-09-25: go with recommendation.**
5. **Shield.** Naturally ventilated (recommended at TRL 2) or a small fan-aspirated shield powered by FieldNode. **Decided by Amish, 2026-09-25: go with recommendation.** Superseded by the fan decision (item 4 of the TRL 3 session); see HMN-DDR-002.
6. **Derived WBGT** by the Liljegren method rather than a wetted natural wet-bulb sensor. **Decided by Amish, 2026-09-25: go with recommendation.**
7. **Platform.** Build on FieldNode and send data through TwinKit or a public LoRaWAN network. **Decided by Amish, 2026-09-25: go with recommendation.**
8. **Data policy.** Open data under an open license, environmental channels only; publisher and host to be agreed with the first partner. **Decided by Amish, 2026-09-25: go with recommendation.**
9. **First partner and city** for co-design and a pilot network. No recommendation: still Proposed, awaiting Amish.

### Safety concerns

- Work at height next to traffic, near overhead lines and on lighting poles that may carry mains voltage: asset owner permission, trained crews, traffic management.
- About 19 Wh LiFePO4 cell in the FieldNode core: fusing, charge temperature limits.
- Hot surfaces (globe and arm above 60 °C in sun, estimate), deburring of cut edges, spinning cups.
- Misuse of data as a warning or as a fitness-to-work decision for individuals; the docs state it is for planning and research only.
- Falling parts from a pole: arm and globe fixings need a secondary retention (for example a lanyard) at TRL 3.

### Problems and notes

- WebSearch was unavailable this session. Sources were verified by fetching pages directly. Could not be read and so left out: NOAA heat mapping campaign figures (heat.gov pages had no figures), Maricopa County heat death counts, Singapore NEA WBGT network, Ahmedabad heat action plan outcomes (NRDC page 404, publisher 403, Europe PMC rate limited). The Liljegren et al. (2008) citation was verified through the README of the open `wbgt` package, as the publisher page returned 403.
- The forced-convection globe equation and the sensor accuracy classes (SHT45, low-cost anemometer start-up) are stated without a source and marked for confirmation at TRL 3.
- FieldNode's pole kit fits 40 to 60 mm poles; HeatMap Node needs longer bands. This is a local BOM note, not a change to FieldNode.
- The legacy `cad/src/model.py` placeholder is untouched (TRL 3 work).

### Recommended next step

Review this note and the media, then decide items 1 and 2. If approved, run `/advance-trl3` to write the calculation note (globe equation and source, shield error, wind sensitivity, wind load), produce the parametric model and drawing sheet, and define the CalRig procedure for the globe and humidity sensors.

## Session 2026-09-25: TRL 3

On 2026-09-25 Amish asked for this batch of repos to go through the usual process with the instruction "you know the drill, nothing gets past TRL 3". He has not reviewed this repo's TRL 2 items one by one, so every item that carried a recommendation is adopted as recommended for TRL 3 under Amish's 2026-09-25 instruction, open for his review. This session ran `/advance-trl3` on that basis and stopped at TRL 3.

### What was done

- `docs/decisions/0001-trl2-review-decisions.md` (HMN-DDR-001 v0.1, status proposed): eight items adopted as recommended for TRL 3, open for Amish's review (D1 to D8), and two left open (O1, O2).
- `docs/04-calcs/01-sizing.md` (HMN-CAL-001 v0.1) and `docs/04-calcs/sizing.py`: mean radiant temperature, natural wet bulb and WBGT with an error budget, shield radiation error, globe and probe response and calibration, height correction and pole shading, sensor power, payload and storage, wind on the arm and clamp, outdoor temperatures, fit and installation time, mass and cost, with a status for every requirement. The script imports the model, reads the BOM and `project.yaml`, and prints every number the note quotes.
- `cad/src/model.py`: parametric build123d model (V-saddle and bands, arm with hangers, eight-plate shield, sensor, globe with probe, anemometer, lanyards, harness, FieldNode core envelope from FND-DWG-001 and a wider pole adapter). Exports `cad/step/` and `cad/stl/` for `heatmap-node-assembly`, `sensor-head` and `fieldnode-core-envelope`.
- `cad/src/sheets.py` and `cad/drawings/HMN-DWG-001.svg`, `.pdf`, `.png`: general arrangement at Rev P1, 1:10, marked "CONCEPT, NOT FOR FABRICATION" and "PRELIMINARY, NOT FOR FABRICATION". HMN-DWG-001 was free because the concept blueprint is HMN-DWG-010.
- `bom/bom.csv` (12 lines, all priced with a supplier or supplier type) and `bom/bom-notes.md`. Added line 11 (secondary retention lanyards, $3, the TRL 2 safety note asked for them) and line 12 (FieldNode pole adapter, $7).
- `cad/src/concept_media.py` now builds from the model; all of `media/` re-rendered and every image checked; temporary `_views` folders deleted. The FieldNode core now faces -Y (the FieldNode convention), so the cutaway leaves out the core, adapter, harness, lanyards and clamp; the cut then passes through the shield and globe. The scene is still shifted down by the arm height for the kit's cutter.
- HMN-PRB-001, HMN-PRC-001 and HMN-REQ-001 revised to v0.3; `README.md` (TRL line, links, key figures, components, safety) and `project.yaml` (`trl: 3`, `trl_target: 3`, evidence list) updated. PDFs rebuilt in `docs/pdf/`.

### Requirement status (HMN-CAL-001, Table 2)

6 not met, 3 at risk, 4 met on paper, 2 met by design.

| ID | Status | Key number |
| --- | --- | --- |
| R1 Air temperature | **Not met** | Passive shield about 1.04 °C high in full sun at 1 m/s, 2.09 °C at 0.5 m/s (targets ±0.5 and ±1.0 °C); assumption-sensitive |
| R4 Wind | **Not met** | Start-up about 0.8 m/s against 0.5 m/s; reading zero at a true 0.5 m/s puts MRT 8.2 °C low |
| R8 Outdoor survival | **Not met** | FieldNode interior 78.3 °C at 50 °C air, 88.3 °C at 60 °C, against a 70 °C rating (from FND-CAL-001) |
| R9 Height | **Not met** | Sensors at 2.67 to 2.71 m; pedestrian-height air 0.2 to 0.8 °C warmer in strong sun |
| R13 Cost | **Not met** | Sensor head $130.00 against $120 |
| R15 Mass | **Not met** | 4.68 kg against 4.0 kg (FieldNode 2.41 kg, not the 1.7 kg assumed at TRL 2) |
| R5 WBGT | At risk | Input errors ±0.59 °C RSS, ±0.88 °C worst; +0.9 °C in calm air; Liljegren model error not known |
| R10 Fit and time | At risk | Fits 60 to 200 mm; 37 min against 30 min |
| R14 Traceability | At risk | Assembled 150 mm globe does not fit a CalRig bay; the probe fits if calibrated before assembly |
| R3, R6, R7, R11 | Met on paper | Probe ±0.18 °C, 90 % response about 12 min; 20 B payload, 21.5 kB for 7 days; 0.116 mW; arm factor 13.8, clamp twist factor 2.6 |
| R2, R12 | Met by design | |

Key numbers: worked example MRT 74.8 °C and WBGT 31.7 °C; sensor head 44.1 N at 35 m/s; about 314 N·m added at the pole base; full node $256.00.

### Decisions recorded (HMN-DDR-001)

Adopted as recommended for TRL 3 under Amish's 2026-09-25 instruction, open for his review (now decided by Amish, 2026-09-25: go with recommendation; see HMN-DDR-002): D1 budget covers the sensor head only (R13 redefined; `budget_usd` unchanged at $120); D2 arm at about 2.8 m with a height correction and a later 2.0 versus 2.8 m pilot (R9 target unchanged); D3 150 mm globe; D4 cup anemometer; D5 naturally ventilated shield; D6 WBGT derived by the Liljegren method; D7 FieldNode core with TwinKit or a public LoRaWAN network; D8 open data, environmental channels only. No reworded pitch or problem line was recommended, so `project.yaml` and `README.md` keep the existing wording.

### Still awaiting Amish

1. **O1, first partner and city** for co-design and a pilot. No preference stated.
2. **O2, data publisher and host.** No recommendation was made.
3. **New, sensor head budget (R13).** Options: (a) raise `budget_usd` to $130; (b) keep $120 and find $10 of savings (for example a formed sheet saddle or a cheaper harness); (c) count the pole adapter against FieldNode, since it fixes a FieldNode fit limit. Recommendation: (c), with a note to the FieldNode project that its kit needs a large-pole variant; this brings the head to $123, so (b) is still needed for a small saving. Not applied. **Decided by Amish, 2026-09-25: go with recommendation.** Applied in the 2026-09-25 recommendations-accepted session below.
4. **New, shield (R1, R5).** Options: (a) keep the passive shield and relax R1 to ±1.0 °C at 1 m/s or more; (b) add a small fan run before each reading (about 30 mW, error about 0.1 °C, WBGT budget ±0.20 °C); (c) keep passive and flag readings when the wind is under 2 m/s in sun. Recommendation: (b), since it fixes R1 and most of R5 within the FieldNode allowance. Not applied; D5 stands until Amish decides. **Decided by Amish, 2026-09-25: go with recommendation.** Applied in the 2026-09-25 recommendations-accepted session below.
5. **New, mass (R15).** Options: (a) relax R15 to 5 kg; (b) keep 4 kg for the sensor head only (2.03 kg). Recommendation: (b), matching the budget split of D1. Not applied. **Decided by Amish, 2026-09-25: go with recommendation.** Applied in the 2026-09-25 recommendations-accepted session below.
6. **New, R8 range.** R8 asks for +60 °C at the node while HMN-PRB-001 states +50 °C. Recommendation: set R8 to +50 °C and adopt FieldNode's proposed sun shield on HeatMap nodes; even at +50 °C the core exceeds its rating without the shield. Not applied. **Decided by Amish, 2026-09-25: go with recommendation.** Applied in the 2026-09-25 recommendations-accepted session below.
7. **New, arm orientation.** The pole shades the globe for about 0.9 h a day when the arm points east or west. Recommendation: point the arm toward the equator where the street allows, with the FieldNode core below it; check panel shading at the first site. Not applied (the model keeps the arm along +X). **Decided by Amish, 2026-09-25: go with recommendation.** Applied in the 2026-09-25 recommendations-accepted session below.
8. **New, anemometer (R4).** Options: (a) relax R4 to "0.8 to 20 m/s" and use the calm-share byte to flag biased intervals; (b) a lower-threshold anemometer at higher cost. Recommendation: (a) for a first pilot. Not applied. **Decided by Amish, 2026-09-25: go with recommendation.** Applied in the 2026-09-25 recommendations-accepted session below.

### Cross-repo consistency

- FieldNode (FND REVIEW, FND-CAL-001): mass 2.41 kg, cost $126.00, 100 mW design allowance, 32 B records, 23.7 s/day at SF9 and 81 N at 35 m/s are used as published. Conflict noted, FieldNode not edited: FieldNode's 50 mm V-blocks seat only on poles up to about 71 mm, while HeatMap Node mounts on 60 to 200 mm street poles; this repo adds its own adapter (line 12). FieldNode's interior temperature (its R3, not met) makes HeatMap R8 not met.
- CalRig (CLR REVIEW): the reference uncertainty (0.14 °C typical, 0.24 °C at maximum tolerance) is used for R3. CalRig already notes that the 150 mm globe exceeds its 90 x 70 x 50 mm bay; HeatMap Node proposes calibrating the probe before it is fitted, so only the probe needs a bay. No CalRig edit.
- TwinKit: the 1.02 % worst-case uplink loss is used for R6 latency; no conflict.

### Safety concerns

- Work at height next to traffic and overhead lines; the node adds about 314 N·m at the pole base at 35 m/s, which the pole owner must check.
- Clamp preload carries the smallest margin (twist factor 2.6 at an assumed 1,000 N per band); installers need a torque figure.
- Falling parts: stainless lanyards now back the globe and shield fixings.
- FieldNode LiFePO4 cell (about 19 Wh) overheats at the top of the ambient range without FieldNode's proposed shield; the 45 °C charge lockout must never be defeated.
- Hot surfaces: the globe reaches about 67 °C at 50 °C air.
- Misuse of the data as a warning or as a fitness-to-work decision for an individual.

### Gaps and notes

- Citations: the SHT45 accuracy was checked on the Sensirion product page. The globe equation's ISO 7726:1998 attribution and the 0.15 m and 0.95 defaults were checked in the pythermalcomfort documentation; the coefficients 6.3 and 1.4 were not read from the standard itself (the standard and a Wiley paper returned 403 or did not show them). Still not found by WebFetch: NOAA heat mapping campaign figures (heat.gov pages have no counts) and Maricopa County heat death counts (the page links PDFs only). Singapore NEA and Ahmedabad were not retried. The anemometer start-up speed has no source. Nothing was added to the README from these.
- The shield error, height correction and globe response rest on assumptions that only tests can settle. The wet-bulb model is a simplified stand-in for the Liljegren code.
- Existing material beyond TRL 3: `build-log/README.md` (scaffold) is present, untouched and not extended. No test, build or firmware material exists.

### Recommended next step

TRL 4 is on hold by Amish's instruction; this repo stops at TRL 3. Amish's review is needed on D1 to D8 and on items 1 to 8 above. For the record only, TRL 4 would need: a bench build of the sensor head on a FieldNode core; a lab test report (TST, `environment: lab`) covering the shield error against an aspirated reference in simulated sun with and without a fan, globe step response, probe calibration in CalRig, anemometer start-up, and clamp preload and slip on 60 and 200 mm poles; and build log entries. None of this has been started.

## Session 2026-09-25: recommendations accepted

On 2026-09-25 Amish wrote: "i accept all your recommendations, go with them across all repos." Every item in this note and in HMN-DDR-001 that carried a recommendation is now decided by Amish, 2026-09-25: go with recommendation. The decisions and their effects are recorded in `docs/decisions/0002-recommendations-accepted.md` (HMN-DDR-002 v0.1). Fourteen items were decided: D1 to D8 of HMN-DDR-001 and six TRL 3 items (N1 to N6).

### Decisions applied and what changed

| Decision | Before | After |
| --- | --- | --- |
| D1 to D8 (HMN-DDR-001) | Adopted for TRL 3, open for review | Decided; D5 (passive shield) superseded by N2; D2 pilot on hold (TRL 4) |
| N1 Budget: adapter counted against FieldNode, plus savings | Head $130.00 (adapter $7 inside); saddle 5 mm wall, $8.00, 0.57 kg | Adapter on the FieldNode side; formed 3 mm sheet saddle $5.00, 0.40 kg; head $120.00 before the fan. `budget_usd` stays $120 |
| N2 Fan-aspirated shield | Passive: 1.04 °C at 1 m/s, 2.09 °C at 0.5 m/s; WBGT input budget ±0.59 °C; sensors 0.116 mW | 60 mm 5 V fan and cowl (line 13, $7.00), 6 s every 3 min: 0.43 °C at any wind; ±0.30 °C; 35.4 mW (35 % of allowance). Sensors 25 mm lower (2.67 to 2.69 m) |
| N3 R15 sensor head only | Complete node 4.68 kg against 4 kg, not met | Head 1.91 kg against 4 kg, met on paper (complete node 4.70 kg for information) |
| N4 R8 +50 °C and FieldNode sun shield | R8 at +60 °C; core 78.3 °C at 50 °C air; FieldNode $126.00, 2.41 kg | R8 at +50 °C; core 57.2 °C at 50 °C air; FieldNode $134.00, 2.55 kg; shield in the model |
| N5 Arm toward the equator, core below | Arm along +X, core on the -Y face; pole shades the globe about 0.9 h a day | Arm and core both face +X (the equator); pole shading of the globe near midday removed; new panel shading found (N8) |
| N6 R4 0.8 to 20 m/s, calm flag | R4 0.5 to 20 m/s, not met | R4 restated; server flags an interval when 20 % or more is below start-up; met on paper |

Files changed: `bom/bom.csv` (lines 1, 8, 12 respecified, line 13 added) and `bom/bom-notes.md`; `cad/src/model.py` (formed saddle, fan and cowl, top plate hole, lower shield, FieldNode turned under the arm with its sun shield, harness reroute) and re-exported STEP and STL; `cad/src/sheets.py` and HMN-DWG-001 at Rev P2; `cad/src/concept_media.py` key figures, flow label and exploded offsets, all of `media/` re-rendered (hero, blueprint, exploded, cutaway and flow checked; `_views` folders deleted); `docs/04-calcs/sizing.py` and HMN-CAL-001 v0.2; HMN-REQ-001 v0.4, HMN-PRC-001 v0.4, HMN-PRB-001 v0.4, HMN-DDR-001 v0.2, new HMN-DDR-002 v0.1; `README.md` (budget line, Concept, components, safety, and a rewritten "What sparked the idea"); `project.yaml` evidence list. All PDFs rebuilt, and every generated file now shows designmolecule.com.

### Requirement status (HMN-CAL-001 v0.2, Table 2)

2 not met, 3 at risk, 8 met on paper, 2 met by design (before: 6, 3, 4, 2).

| ID | Status | Key number |
| --- | --- | --- |
| R9 Height | **Not met** | Sensors at 2.67 to 2.69 m; pedestrian-height air 0.2 to 0.8 °C warmer in strong sun |
| R13 Cost | **Not met** | Sensor head $127.00 against $120 (fan and cowl $7) |
| R5 WBGT | At risk | ±0.30 °C RSS input budget; Liljegren model error unknown |
| R10 Fit and time | At risk | 37 min against 30 min |
| R14 Traceability | At risk | Assembled globe does not fit a CalRig bay |
| R1, R3, R4, R6, R7, R8, R11, R15 | Met on paper | R1 0.43 °C (fan flow assumed); R7 35.4 mW (panel shading not included); R8 57.2 °C; R11 factors 13.4 and 2.5; R15 1.91 kg |
| R2, R12 | Met by design | |

### Still awaiting Amish

1. **O1, first partner and city.** No preference stated, no recommendation.
2. **O2, data publisher and host.** No recommendation.
3. **N7, sensor head budget after the fan.** $127.00 against $120. Options: (a) raise `budget_usd` to $130; (b) keep $120 and cut $7 more (for example a cheaper anemometer class, at the cost of R4); (c) count the fan against a separate accuracy option. Recommendation: (a). **Decided by Amish, 2026-09-26: budget top-up to $130 (option a), applied in the session below.**
4. **N8, FieldNode panel shading.** With the core below the arm and both facing the equator, the shield, cowl, globe and arm shade 44, 34, 27 and 16 % of the panel with the sun along the arm at 30, 45, 60 and 75° elevation (HMN-CAL-001 [E3]). Options: (a) mount the core above the arm; (b) keep it below and accept the loss pending FieldNode's bypass diode layout; (c) move the core to the pole's east or west face. Recommendation: (a). Not applied.

### Cross-repo actions (other repos not edited)

- **FieldNode:** add a large-pole kit variant (V-blocks for 60 to 200 mm poles) so that HeatMap's line 12 adapter, now counted against FieldNode, becomes a FieldNode part (N1).
- **FieldNode:** HeatMap nodes use the hot-climate build with the sun shield ($134.00, 2.55 kg), as FieldNode's own cross-repo note expected (N4).
- **FieldNode:** the port assignment assumed here (5 V switched rail on the temperature and humidity port powering the fan and sensor) should be considered when FieldNode's pinout (its O2) is set; and FieldNode's energy budget should allow for partial panel shading if N8 option (b) is chosen.
- **CalRig:** unchanged; the probe is still calibrated before it is fitted to the globe.

### Safety

- The shield fan starts on its own every 3 min; unplug the sensor lead before working on the shield.
- The FieldNode sun shield keeps the cell within its charge limits at hot sites and must not be left off.
- The node now adds about 337 N·m at the pole base at 35 m/s; the pole owner must check it. The clamp twist factor is 2.5, the smallest margin; installers need a torque figure, and the formed sheet saddle's stiffness is to be checked at detail design.
- Work at height, hot surfaces and data misuse notes are unchanged.

### TRL 4

TRL 4 remains on hold by Amish's instruction. `trl` and `trl_target` stay at 3. The 2.0 versus 2.8 m pilot, the site check of panel shading, choice and testing of the fan, a side-by-side shield test, firmware for the fan timing and calm flag, and any purchasing are decided where applicable but not started.

### Notes

- The fan figures (0.9 W, 6.6 L/s free air, 60 % delivered, 2 s sensor time constant) are class values and assumptions, not a chosen part. The earlier estimate of about 30 mW for 0.1 °C assumed 3 m/s across the whole 60 cm² stack section, which a 0.3 W fan cannot deliver; the revised figures give 35 mW for 0.43 °C.
- "What sparked the idea" now cites the 1950s US Marine Corps heat flags and the 1957 origin of WBGT (HPRC; Budd, 2008). The Budd abstract was read through the publisher's page; the Parris Island location given in secondary sources was left out because no primary source for it could be opened.

## Session 2026-09-26: sources strengthened

### Sources

Every link in "Concept rationale", "Burning platform", "Where it could be used" and "What sparked the idea" was fetched again and checked against the sentence it supports: WHO heat and health fact sheet (489,000 deaths a year, 45 % in Asia, 36 % in Europe, informal settlements), Ballester et al. 2023 (61,672 deaths in 35 countries), US EPA heat islands (1 to 7 °F by day), Hoffman et al. 2020 (2.6 °C, up to 7 °C), Hsu et al. 2021 (all but 6 of 175 urbanized areas), WMO Africa report release (+0.3 °C per decade 1991 to 2022, observation gaps, most rapid warming in North Africa), ISO 7243:2017, the DoD Human Performance Resource Center heat flag page, Liljegren et al. 2008 and Budd 2008 (bibliographic records confirmed through Crossref). All are primary sources, peer-reviewed papers or official agency pages, and every country or region row carries a citation that supports it.

- Replaced: none. No Wikipedia, blog or trade-press link was found in scope, and no row needed replacing.
- "What sparked the idea" is unchanged (HPRC, US Department of Defense; Budd, 2008). Its INSPIRATIONS.md line is unchanged.
- Not re-read this session: the Budd (2008) abstract text (publisher page and Europe PMC unavailable; PubMed returned a CAPTCHA). The claim that WBGT cut heat casualties and lost training time rests on the reading of the publisher page recorded in the session above. The heat-death figures left out in the first session (Maricopa County, Ahmedabad, Singapore NEA, NOAA campaigns) remain out.

### Budget

- N7 decided by Amish, 2026-09-26 ("I am ok with the budget top ups"): `budget_usd` $120 to $130 in `project.yaml`.
- `docs/04-calcs/sizing.py` reads `budget_usd` and was re-run: [L2] now reads "sensor head within by $3.00". R13 not met to met on paper.
- Requirement status: 1 not met (R9), 3 at risk (R5, R10, R14), 9 met on paper, 2 met by design.
- Documents revised: HMN-REQ-001 v0.5, HMN-CAL-001 v0.3, HMN-DDR-002 v0.2, HMN-PRC-001 v0.5, HMN-PRB-001 v0.5 (budget constraint only); `README.md` budget line and Concept paragraph; `bom/bom-notes.md`.
- Concept media: the blueprint key figure in `cad/src/concept_media.py` now reads "budget $130"; all of `media/` was regenerated and the temporary `_views` folders deleted.
- Still awaiting Amish: O1, O2 and N8.

## Session 2026-09-26: product appearance model and photoreal renders

Amish chose this repo for the first batch of product renders on 2026-09-26.

### What was done

- New `cad/src/product_model.py`: `product_parts()` returns 65 named parts (49 shell, 11 internal, 4 accessory, 1 context), each with a colour, a render material, its BOM line and an exploded-view offset. It imports PARAMS, `derived()` and the `path` and `rod` helpers from `cad/src/model.py`, so every main dimension, height and interface is unchanged. It also defines `TITLE` and three `RENDER_VIEWS`: hero (on a short section of the existing street pole), exploded and detail (without the pole).
- What the appearance model adds: filleted arm tube with a black end cap and an identity label with the teal accent; the V-saddle with rounded edges, a rubber liner, bolt heads, and strap bands with buckles and screws; eight shield plates with rounded edges on stainless rods with top nuts and acorn nuts; the aspiration fan as a frame, a seven-blade rotor and a hub label under the white cowl; the temperature and humidity capsule with a PTFE membrane cap and an M12 connector; the matte black globe with its seam flange, a brass boss and a probe gland, and the probe stem and bead inside; the anemometer as mast, body, teal rotor cap and cups; the harness with an M12 plug, cable ties along the arm and the stainless lanyards; the FieldNode core as back plate, enclosure base and lid with a parting line and lid screws, sun shield with a name plate, solar panel frame with cells, busbars and a junction box, support bars, whip antenna with base nut, M12 sockets and a vent plug; and the pole adapter V-blocks and strap bands.
- `README.md`: the hero image now points to `media/render-hero.png`, and the links line starts with the exploded render. The render files are produced separately and were not created in this session.
- Matplotlib previews were checked for the hero, exploded and detail views (kept outside the repo). All shapes are valid and tessellate; `.kit/product_export.py` exports all 65 parts.

### Differences from model.py

Each item below is appearance only, and none changes a PARAMS value.

- **FieldNode internals and split enclosure.** The model treats the FieldNode core as an envelope. The appearance model splits the enclosure into a base and a front lid and shows a board, a LoRaWAN module can and a horizontal 32 mm LiFePO4 cell inside, so the exploded view can show the board and battery. These are stand-ins; FND-DWG-001 and the FieldNode BOM define the real parts. Proposed, awaiting Amish. Recommendation: keep them as stand-ins and ask the FieldNode repo to confirm the cell format and board position at its next update.
- **Vent slots and name plate on the FieldNode sun shield.** Four vent slots in each side sheet and a HeatMap Node name plate on the front are not in FND-DWG-001. Proposed, awaiting Amish. Recommendation: keep the name plate (it identifies the node to the public and the pole owner) and drop the side slots unless FieldNode adopts them, since its sun shield is already ventilated through the top slot and open bottom.
- **Arm end cap.** A 2.5 mm black plug is drawn beyond the arm tip, so the arm reads 2.5 mm longer than `arm_len`; the overall reach is set by the anemometer cups and is unchanged. Proposed, awaiting Amish. Recommendation: accept, and add a plug to BOM line 10 at the next BOM revision.
- **Globe seam flange.** A 1.2 mm raised seam ring is drawn at the globe equator, as on pressed float balls. Proposed, awaiting Amish. Recommendation: accept for appearance; its effect on the globe reading is negligible at this TRL.
- **Harness start.** The harness is drawn from the M12 plug under the FieldNode port instead of from inside the port; routing is otherwise the same.

### TRL

This is an appearance model only: no tolerances, no fabrication detail, no PCB layout. `trl` and `trl_target` stay at 3, and TRL 4 remains on hold.

## Session 2026-09-27: kit 1.5.0 and image quality

- Kit 1.5.0 synced: STANDARDS v1.5 (sections 12 to 15: product renders, storefront images and image quality, public release, authorship and signing), `.kit/cards.py`, `.kit/image_qc.py`, `.kit/release_gate.py`, issue templates, and the `/render-product` and `/release` commands. `CLAUDE.md` now matches `.kit/CLAUDE.md`.
- Every `media/render-*.png` recaptioned from its original render with the new layout: the title, concept label and repository sit in a band above the render and the view note in a band below it, each line wrapped to the image width, so no text overlaps other text or the render or runs off the image. `media/card.png` and `media/social-preview.png` regenerated with the same rules.
- `python .kit/image_qc.py` and `python .kit/release_gate.py` pass. trl stays 3.

## Session 2026-10-01: design for construction and prototype build plan (kit 1.7.0)

Under Amish's 2026-09-30 instruction to make the design physically buildable and to write an illustrated build plan ("fix the design assumptions to match and be physically feasible"), and his 2026-10-01 note that `budget_usd` is a value-engineering target. Kit 1.7.0 installed (`.kit/`, `.claude/commands/`, `CLAUDE.md`).

### Design changes made for construction (HMN-DDR-003, Draft, open for Amish's review)

1. Arm saddle: a channel bent from 3 mm 5052 sheet, 120 x 180 x 40 mm (was a 110 mm tray with a round seat for one pole size), with 120° V notches in its flanges lined with rubber edge trim; seats 60 to 200 mm poles.
2. Arm fixing: two 40 x 40 x 3 mm angle cheeks on the saddle web (four M6 button-head screws); the arm bolted between them by two M6 bolts through crush sleeves.
3. Saddle bands: through four 3 x 16 mm web slots and across the web front (were rings through the saddle).
4. Shield: four M5 rods on a 92 mm circle, clear of the cowl (were three, two inside the cowl); printed 12 mm bosses set the plate gaps; two rods continue through the arm on 41 mm spacers (the unfixed central hanger rod is gone).
5. Fan and cowl: fan flat on the top plate; cowl on four legs over the fan's corner holes; four M4 x 40 screws through cowl, fan and plate.
6. Sensor: held in a hub on three spokes printed on the third plate, with a nylon set screw.
7. Globe: hung on a hollow M10 x 1 brass tube nutted above and below the arm; the probe runs down inside it (the solid hanger rod met the probe).
8. Anemometer: mast through the arm, pinned by one M5 bolt; arm 530 mm (was 520 mm); reach 668 mm (was 679 mm).
9. Arm end plug added.
10. Harness rerouted round every part: up the pole outside the bands, round the saddle side, along the arm's left side, tails between the plates, to the hanger tube top and into the mast foot.
11. Lanyards looped round the arm with snap hooks.
12. FieldNode pole adapter: printed 120° V-blocks 110 x 30 x 38 mm with band slots in line with FieldNode's plate slots and M4 heat-set inserts at its V-block screw holes (were flat blocks for one pole size covering the slots).
13. FieldNode envelope updated to FND-DWG-001 Rev P3; FieldNode figures to $148.00 and 2.61 kg after FND-DDR-003.

`python cad/src/model.py --check`: 399 constructability checks (no overlaps, contacts, clearances, pole range), all pass.

### What was done, with file paths

- `cad/src/model.py`: rebuilt as separate components (`build_components`) with the changes above and the checks; STEP and STL re-exported (`cad/step/`, `cad/stl/`).
- `bom/bom.csv` lines 1, 2, 4, 6, 7, 8, 10, 12 and 13 respecified; `bom/bom-notes.md` updated.
- `docs/04-calcs/sizing.py` (mass now from the component volumes) re-run; HMN-CAL-001 v0.4, HMN-REQ-001 v0.6, HMN-PRC-001 v0.6.
- `cad/drawings/HMN-DWG-001` Rev P4; making sketches `HMN-DWG-101` to `107` (saddle, cheek, arm, top plate, ring plates, cowl, adapter V-block).
- `cad/src/build_plan_media.py`: overview, arm hole layout, 8 joint close-ups and 16 assembly step pictures in `docs/05-build-plan/`.
- New `docs/05-build-plan.md` (HMN-BLD-001), `docs/06-design-decisions.md` (HMN-DEC-001), `docs/decisions/0003-design-for-construction.md` (HMN-DDR-003).
- Concept media regenerated (`media/hero.png`, `concept-blueprint.*`, `exploded.png`, `cutaway.png`, `flow.png`, `model.glb`, `viewer.html`).
- `project.yaml`: `design_state: constructable`; the build plan, register and HMN-DDR-003 added to `trl_evidence`; `budget_usd` unchanged. `README.md`: links line, value-engineering line, Concept figures and a "Building the prototype" section.

### Key results

- Sensor head 2.12 kg (was 1.91 kg) against 4 kg (R15 met on paper); complete node 4.95 kg.
- Value-engineering target: USD 130. Estimated cost of the constructable design: USD 136 (USD 6 over the target). Full node about USD 292.
- Arm factor 13.0 on yield, tip 0.31 mm at 20 m/s, clamp twist factor 2.5 (R11 met on paper, preload assumed).
- Requirement status: 1 not met (R9, measurement height), 3 at risk (R5, R10, R14), 8 met on paper, 2 met by design, R13 $6 over its value-engineering target.

### Decisions proposed and awaiting Amish

All open items are in `docs/06-design-decisions.md`: accept HMN-DDR-003; the sensor hub spokes in the air path (A1); FieldNode panel shading (N8); first partner and city (O1); data publisher (O2); port pinout shared with FieldNode; three appearance-model items from 2026-09-26.

### Stale media (made on Amish's Mac, not regenerated here)

The design changed visibly, so `media/render-hero.png`, `media/render-exploded.png`, `media/render-detail.png`, `media/card.png` and `media/social-preview.png` and the appearance model `cad/src/product_model.py` are stale (they show the tray saddle, three-rod shield and solid globe rod). The `media/render-*.png` files are not in this cloud copy, so the README hero image and render links do not resolve here.

### Safety

No change to the safety case. The build plan adds safety stops for work at height, the FieldNode cell (its own plan), and the self-starting fan, hot globe and spinning cups. Clamp preload still carries the smallest margin (twist factor 2.5); the band tool setting is an item to confirm.

### Recommended next step

Amish's review of HMN-DDR-003 and the register. TRL 4 (building to HMN-BLD-001 and testing) stays on hold by his instruction.

## Session 2026-10-02: open decisions decided

Amish approved every recommendation for the open decisions on 2026-10-02: "i approve your recommendations for all 555 open decisions."

### Decisions recorded

Nine, all moved to "Decisions made" in HMN-DEC-001 (open items 1 to 9): design for construction accepted (HMN-DDR-003); sensor hub kept on three spokes and included in the TRL 4 shield test; FieldNode core above the arm if its lid stays reachable, otherwise on the pole's east or west face; a hot US city with a dedicated heat office first, with the City of Phoenix Office of Heat Response and Mitigation as the first candidate to approach, on US915; data through a TwinKit gateway and published from CityTwin's open data export under an open licence, with Amish's lab as publisher until the city takes it over; FieldNode's candidate pinout adopted for the two sensor ports; FieldNode internals kept as stand-ins in the appearance model; name plate kept and side vent slots dropped; raised seam ring accepted.

### Documents changed

- `docs/06-design-decisions.md` HMN-DEC-001 v0.2: decisions made; open decisions section now reads "None".
- `docs/decisions/0003-design-for-construction.md` HMN-DDR-003 v0.2: accepted (status Draft kept); A1 as recommended.
- `docs/01-problem.md` HMN-PRB-001 v0.6: first partner city and data publisher.
- `docs/02-concept.md` HMN-PRC-001 v0.7: core position and data publishing; open questions answered.
- `docs/04-calcs/01-sizing.md` HMN-CAL-001 v0.5: panel shading text notes the decided core position; no figures changed.
- `docs/05-build-plan.md` HMN-BLD-001 v0.2: step 12 gives the decided port pinout.

### Follow-up actions to carry approved decisions into the design

1. Decision 3 (model): move the FieldNode core and its adapter above the arm in `cad/src/model.py`, or to the pole's east or west face if its lid cannot be reached from the ladder or lift there; re-run the constructability check.
2. Decision 3 (pictures, drawings): redraw steps 14 to 16, the overview and the adapter making sketch for the new core position, and update the build plan text of those steps.
3. Decision 3 (BOM): re-specify the harness lead length (line 9) for the new core position.
4. Decision 3 (calculations): rerun the panel shading [E3], the wind load and the clamp check for the core above the arm, and check the core height against FieldNode's decided 1.75 m mounting height.
5. Decision 2 (docs): put the hub and spokes in the TRL 4 side-by-side shield test plan.
6. Decision 6 (docs): ask the FieldNode repo to adopt the same pinout as its O2 decision, so that both repos agree.
7. Decision 7 (docs): ask the FieldNode repo to confirm the cell format and board position at its next update, then update the stand-ins.
8. Decision 8 (pictures): drop the side vent slots from `cad/src/product_model.py`, keep the name plate, and re-render on Amish's Mac.

### Points found in the review

- R9 (sensors at 1.1 to 2.0 m) is not met, with sensors at about 2.68 m, yet no open decision addresses it; either restate R9 around the height correction already decided or add an item.
- Item 3 says the plan builds option (b) until decided; if option (a) is chosen, steps 14 to 16 and the harness length change, and the core rises above FieldNode's decided 1.75 m mounting height.
- Sensor head cost is $136 against the $130 target, $6 over; the full node is $292.

## Session 2026-10-02: approved follow-ups carried out

Amish approved all follow-up actions from the open-decision sign-off (2026-10-02). trl stays 3; nothing was built, bought or tested.

### Follow-ups

| No. | Follow-up | Status |
| --- | --- | --- |
| 1 | Move the FieldNode core and adapter above the arm in the model; re-run the checks | Done. Core bottom at 3.11 m, its whip 100 mm or more above the arm, panel toward the equator; 403 checks pass (new clearances of the core from the arm, saddle, cheeks, bands and anemometer). Option (c), the east or west face, is kept in build plan step 15 as the fallback if the lid cannot be reached |
| 2 | Redraw steps 14 to 16, the overview and the adapter making sketch; update the step text | Done. Steps 14 to 16 reordered: head on the pole first, then the core above it, then the leads; all pictures and HMN-DWG-001 (Rev P5) regenerated |
| 3 | Re-specify the harness lead length (BOM line 9) | Done. Lead A about 1.2 m, lead B about 1.4 m (was 1.5 m each); the model runs are 0.83 m and 1.05 m to the arm sensors; price unchanged at $12.00 |
| 4 | Rerun panel shading [E3], wind load and clamp check; check core height against FieldNode's 1.75 m | Done in HMN-CAL-001 v0.6: the head shades 0 % of the panel (was 16 to 44 %); new [E3b] shows the panel and core can shade the globe, shield or cups only with the sun on the pole side (tropics, near noon); wind moment at the pole base 423 N·m (was 338); clamp factor unchanged. The core is at 3.11 m against FieldNode's decided 1.75 m mounting height, 1.36 m higher; the FieldNode repo must confirm that its design (antenna, wind and sun figures) holds there (see cross-repo actions) |
| 5 | Put the hub and spokes in the TRL 4 side-by-side shield test plan | Not done: TRL 4 test plan work, capped at TRL 3 |
| 6 | Ask the FieldNode repo to adopt the same pinout | Not done here: lives in the FieldNode repo (see cross-repo actions) |
| 7 | Ask the FieldNode repo to confirm cell format and board position | Not done here: lives in the FieldNode repo (see cross-repo actions) |
| 8 | Drop the side vent slots from the appearance model, keep the name plate | Done in `cad/src/product_model.py`; photoreal renders are made on Amish's Mac |

### Requirement and figure changes

- No requirement status changes. R7 note: the head no longer shades the panel. R15: sensor head 2.08 kg (was 2.12 kg, shorter leads), complete node 4.92 kg. R13: sensor head still $136.00, USD 6 over the USD 130 value-engineering target; `budget_usd` unchanged.
- Added wind moment at the pole base rises from 338 to 423 N·m (core 0.96 m higher); the build plan safety stop S3 now says about 420 N·m for the pole owner.

### Documents changed

- `cad/src/model.py`, `cad/step/`, `cad/stl/`; `bom/bom.csv` (line 9), `bom/bom-notes.md`.
- `docs/04-calcs/sizing.py`, `01-sizing.md` (HMN-CAL-001 v0.6), `docs/03-requirements.md` (HMN-REQ-001 v0.7), `docs/02-concept.md` (HMN-PRC-001 v0.8), `docs/05-build-plan.md` (HMN-BLD-001 v0.3), `README.md`.
- Pictures: HMN-DWG-001 Rev P5, the adapter making sketch, every build plan joint and step picture, the overview, and the concept media.
- `cad/src/product_model.py`: core above the arm, leads down the pole, side vent slots dropped. Render scenes exported to `/home/claude/renders/heatmap-node`.

### Cross-repo actions

- FieldNode: adopt the same sensor port pinout as its O2 decision (port A, I2C on data pins 2 and 4 with sensor and fan on the switched rail; port B, thermistor on analog pin 5 and anemometer pulse on pin 2).
- FieldNode: confirm cell format and board position at its next update, so the appearance stand-ins can be replaced.
- FieldNode: confirm that the core works at 3.11 m on a pole above an arm (its decided mounting height is 1.75 m), and publish a large-pole adapter variant (still open from earlier sessions).

## 2026-10-02: photoreal renders redone on the constructable design

Rendered with Blender Cycles on Amish's Mac from the updated appearance model; captioned with `.kit/photo_caption.py`; `media/card.png` and `media/social-preview.png` regenerated with `.kit/cards.py`. Views: hero, exploded, detail. image_qc passes. Appearance deviations are those logged above as proposed, awaiting Amish.

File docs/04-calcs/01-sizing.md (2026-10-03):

---
doc_id: HMN-CAL-001
title: HeatMap Node sizing calculations
project: HeatMap Node
doc_type: Calculation
version: "0.6"
status: Draft
date: '2026-10-02'
author: Amish Chadha
license: CERN-OHL-S-2.0
revisions:
- version: "0.1"
  date: '2026-09-25'
  author: Amish Chadha
  change: First issue for TRL 3 (mean radiant temperature, natural wet bulb and WBGT error budget, shield error, globe response and probe, height and shading, power, data, wind and clamp, outdoor temperatures, fit and installation, mass, cost)
- version: "0.2"
  date: '2026-09-25'
  author: Amish Chadha
  change: Recommendations accepted by Amish (DDR-002)
- version: "0.3"
  date: '2026-09-26'
  author: Amish Chadha
  change: "Budget top-up approved by Amish: R13 target $130, script re-run"
- version: "0.4"
  date: '2026-10-01'
  author: Amish Chadha
  change: Design for construction (HMN-DDR-003); mass from the constructable model; FieldNode figures after FND-DDR-003; cost reported against the value-engineering target
- version: "0.5"
  date: '2026-10-02'
  author: Amish Chadha
  change: "Panel shading text notes the core position decided on 2026-10-02; no figures changed"
- version: "0.6"
  date: '2026-10-02'
  author: Amish Chadha
  change: "Core moved above the arm in the model (2026-10-02): panel shading rerun (E3, new E3b), added pole moment 423 N m, shorter harness, head 2.08 kg; no requirement status changes"
---

# HeatMap Node sizing calculations

On paper, HeatMap Node meets or is on track for thirteen of its fifteen requirements; one is not met, and the sensor head's estimated cost is $6 over its value-engineering target. Version 0.2 applies the decisions Amish accepted on 2026-09-25 (HMN-DDR-002): a small fan aspirates the radiation shield before each air reading, R4, R8, R13 and R15 are restated, the saddle is formed from sheet, the arm points toward the equator with the FieldNode core (since 2026-10-02, above it), and the FieldNode core carries FieldNode's hot-climate sun shield. The heat stress method is unchanged: in the worked example (35 °C air, 40 %RH, 50 °C globe, 1 m/s wind) mean radiant temperature is 74.8 °C and WBGT is 31.7 °C, and with the fan the input errors add up to ±0.30 °C of WBGT (root sum square), against ±0.59 °C with the passive shield. The one miss is R9, because the sensors sit at about 2.7 m, where the air is 0.2 to 0.8 °C cooler than at pedestrian height on a sunny afternoon. Version 0.3 applies the budget top-up Amish approved on 2026-09-26 (HMN-DDR-002 v0.2): `budget_usd` became $130, and the $127 sensor head was then $3 under it. Version 0.4 follows the design for construction (HMN-DDR-003): the parts added to make the node buildable bring the sensor head to 2.12 kg and $136.00, $6.00 over the $130 value-engineering target (`budget_usd` is a hypothetical control target, not a limit: Amish, 2026-10-01), and the 530 mm arm changes the wind figures slightly. The new orientation raised one problem: with the core below the arm, the shield, globe and arm shaded 16 to 44 % of the FieldNode panel near noon (section E). Version 0.6 carries the decision of 2026-10-02 into the model: the core is above the arm (bottom at 3.11 m), the panel is no longer shaded by the head (0 % in every case run), the harness leads are shorter (1.2 m and 1.4 m), and the added moment at the pole base rises from 338 to 423 N·m. Every number in this note is printed by `docs/04-calcs/sizing.py`; the tag in brackets, for example [A1], is the line of that script's output that carries it.

> **Safety:** These are first-principles estimates for a paper proof of concept. They do not show that a place is safe or unsafe for people, and HeatMap Node data must not be used to decide whether a particular person may work or exercise. Pole mounting, the pole's added wind load and the FieldNode cell are safety matters; see HMN-PRC-001, Safety.

## Scope and method

The note checks every requirement in HMN-REQ-001 v0.6 against the design in HMN-PRC-001 v0.6 and the parametric model `cad/src/model.py`. The script imports the model's `PARAMS`, derived dimensions and part solids, so the heights, lengths, areas and volumes used here are those in the STEP files and in drawing HMN-DWG-001. It also reads `bom/bom.csv` and `budget_usd` in `project.yaml`. FieldNode figures (mass, cost, wind load, interior temperature, airtime, sensor allowance) are quoted from FND-CAL-001 (v0.4 for mass and cost after FieldNode's design for construction, v0.2 for wind and heat, which that change left unchanged) for the hot-climate node with its sun shield, and the calibration reference uncertainty from CLR-CAL-001 v0.1; no sibling repo was edited. Run the script from the repo root with `python docs/04-calcs/sizing.py`.

The design case is a node on a 114.3 mm (4.5 in) street pole with the arm axis 2.8 m above the pavement, air temperature up to 50 °C, full sun and 15 min reporting.

## Assumptions

*Table 1. Main assumptions.*

| Area | Assumption | Basis |
| --- | --- | --- |
| Globe | 150 mm copper sphere, 0.4 mm wall, emissivity 0.95; convection coefficient the larger of 6.3 *v*^0.6 / *D*^0.4 (forced) and 1.4 (Δ*T* / *D*)^0.25 (natural) W/m²K | ISO 7726:1998 method as implemented in the open [pythermalcomfort `t_mrt` function](https://pythermalcomfort.readthedocs.io/en/latest/reference/pythermalcomfort.html) (defaults 0.15 m and 0.95). The coefficients 6.3 and 1.4 are the commonly quoted values and were not read from the standard itself; 6.3/σ equals the 1.1 × 10⁸ of the TRL 2 precis [A1] |
| Wet bulb | Notional wick 7 mm diameter; cylinder in cross flow Nu = 0.683 Re^0.466 Pr^(1/3); Chilton-Colburn heat and mass analogy, Lewis number 0.85; the wick sees the radiant environment measured by the globe | Textbook correlations. A simplified stand-in for the Liljegren et al. (2008) model, which the data server will use through its open implementation |
| Sensors | SHT45 typical ±0.1 °C and ±1.0 %RH ([Sensirion](https://sensirion.com/products/catalog/SHT45)); globe probe ±0.3 °C (R3); anemometer ±0.5 m/s (R4) and start-up 0.8 m/s | Sensirion product page (checked 2026-09-25); anemometer start-up is a typical low-cost value, unverified |
| Shield | White ASA plates, solar absorptance 0.25; half of the absorbed heat reaches the air passing the sensor; with the fan off, air inside the stack moves at a quarter of the wind speed; 1,000 W/m² global irradiance, sun 60° high, pavement albedo 0.15 | Assumed; only a side-by-side test can set these |
| Fan | 60 x 60 x 15 mm 5 V class fan, 0.90 W, 6.6 L/s (about 14 CFM) free air, 60 % of it delivered through the stack; FieldNode 5 V rail 85 % efficient; T and RH sensor time constant 2 s with its membrane cap | Typical values for the fan class and assumed shares; not checked against a chosen part |
| Height | Surface-layer similarity (Businger-Dyer functions) with a 250 W/m² sensible heat flux from sunlit pavement and a 0.1 m roughness length | Assumed; similarity theory is only approximate inside a street canyon |
| Wind | 35 m/s gust (750 Pa); drag coefficients 0.5 on the globe, 1.2 on the shield, mast and hub, 1.4 on open cups, 2.0 on the square arm | Screening values, not a code check |
| Clamp | 1,000 N preload per strap band, friction coefficient 0.4 | As FND-CAL-001, to keep the two notes consistent |
| Materials | Aluminium 6063, E 69 GPa, yield 145 MPa; aluminium 2.7, ASA 1.07, stainless 7.9, copper 8.96 g/cm³ | Handbook values |
| FieldNode | Hot-climate node with the sun shield, Rev P3: 2.61 kg, $148.00 ($139.00 base plus the $9.00 shield), 88 N at 35 m/s (panel 52.2 N, shielded enclosure 36.3 N), interior 7.2 K above ambient when dusty with the sun in its worst position (28.3 K without the shield); 100 mW design sensor allowance, 32 B per stored reading, 23.7 s/day airtime at SF9 | FND-CAL-001 v0.4 and v0.2 |

## A. Mean radiant temperature from the globe (R3, R4, R5)

- **Worked example.** At 35 °C air, 50 °C globe and 1 m/s, the forced convection coefficient is 13.5 W/m²K against 4.4 W/m²K for natural convection, and MRT is 74.8 °C [A1]. The TRL 2 figure of about 75 °C stands.
- **Wind is the weakest input.** With 0.5, 1.5 and 3.0 m/s instead of 1 m/s, MRT is 66.9, 80.7 and 93.9 °C [A2]. A 0.5 m/s wind error moves MRT by about 6 to 8 °C; a 1 °C air temperature error moves it by 1.5 °C and a 0.3 °C globe error by 0.7 °C [A3].
- **Calm air.** Natural convection governs only below 0.16 m/s [A4]. Below the anemometer's start-up speed the node reads zero wind: at a true 0.5 m/s, MRT is then computed as 58.8 °C instead of 66.9 °C, 8.2 °C low [A5]. R4 now covers 0.8 to 20 m/s (HMN-DDR-002), and intervals with a large share of calm air are flagged by the server (section G) rather than corrected.

## B. Natural wet bulb and WBGT (R5)

- **Check of the wick model.** With no radiant excess the model gives a wet bulb of 24.2 °C at 35 °C and 40 %RH [B1], the psychrometric value the TRL 2 precis assumed (about 24.5 °C).
- **Worked example.** In sun the natural wet bulb is 26.0 °C, and WBGT = 0.7 × 26.0 + 0.2 × 50 + 0.1 × 35 = 31.7 °C [B2]. The TRL 2 estimate (about 31 °C, with an assumed 1 °C sun excess on the wet bulb) is slightly low; the model gives a 1.8 °C excess.
- **Sensitivity.** Per unit input, WBGT moves 0.53 °C per °C of air temperature, 0.15 °C per %RH, 0.28 °C per °C of globe temperature and -0.18 °C per m/s of wind [B3]. Air temperature matters most, because it enters WBGT directly, through the wet bulb and through MRT.
- **Error budget.** With the fan-aspirated shield (section C) the input terms are 0.23 °C (air temperature), 0.15 °C (humidity), 0.09 °C (globe) and 0.09 °C (wind): ±0.30 °C root sum square and ±0.55 °C worst case [B4]. With the passive shield at 1 m/s (v0.1) they were ±0.59 °C and ±0.88 °C [B5].
- **Calm air.** A true 0.5 m/s read as zero raises the computed WBGT by 0.9 °C [B6].
- **R5 is at risk.** The input budget fits the ±1.0 °C target with a wide margin, and flagged calm intervals (section G) are marked rather than trusted, but the error of the Liljegren model itself against a reference WBGT meter is not included and can only be found by collocation.

## C. Radiation error of the shield, passive and fan-aspirated (R1)

- **Heat input.** In full sun the top, sides and underside of the stack present 82, 59 and 70 cm² and absorb 3.74 W; with the fan off, air crosses the stack through about 60 cm² [C1].
- **Passive error (fan off).** The air at the sensor would read 2.09 °C high at 0.5 m/s, 1.04 °C at 1 m/s, 0.52 °C at 2 m/s and 0.35 °C at 3 m/s [C2]; with half the assumed ventilation, 2.09 °C at 1 m/s [C3]. This was the v0.1 design and is why R1 was not met.
- **Fan (HMN-DDR-002).** A 60 mm, 0.90 W fan in a cowl on the top plate draws about 4.0 L/s up the 56 mm center column of the stack, about 1.6 m/s. The steady error is 0.40 °C whatever the wind; after 6 s of running from the passive 1 m/s state the sensor reads 0.43 °C high [C4]. The fan needs at least 3.4 L/s through the stack, about half its assumed free-air flow, to hold ±0.5 °C [C6], so the margin rests on the chosen fan and on how much flow the plate stack lets through.
- **Firmware rule.** The FieldNode switches the 5 V port on for 6 s every 3 min and reads the temperature and humidity sensor at the end of the run: 480 aspirated readings a day, 5 per 15 min mean. That costs 35.3 mW on average from the cell [C5].
- **R1 is met on paper** (±0.5 °C at any wind speed), subject to the assumed fan flow and heat-transfer factors, which only a side-by-side test against an aspirated reference can confirm.

## D. Globe response and probe accuracy (R3)

- **Globe.** The 0.4 mm copper shell weighs 253 g; with a 20 g boss its heat capacity is 105 J/K [D1]. The shell alone has a time constant of 1.8 min at 0.3 m/s, 1.2 min at 1 m/s and 0.7 min at 3 m/s [D2].
- **Bead inside.** The epoxy bead couples to the shell by radiation and still air inside the sphere, with a time constant of 4.2 min. Globe and bead together respond with a time constant of about 5.4 min at 1 m/s, a 90 % response in about 12 min [D5], inside the 30 min of R3. This is faster than the 20 to 30 min estimated at TRL 2. Conduction along the probe stem is not included and only a step test can confirm the figure.
- **Probe.** At 50 °C the NTC reads 3.59 kΩ; in a 10 kΩ divider the slope is 24.3 mV/K, a 12-bit step is 33 mK, and self-heating is 0.21 mW for the 10 ms the divider is on [D3], which is negligible.
- **Calibration.** Calibrated in CalRig before it is fitted to the globe, the probe's expanded uncertainty is ±0.18 °C with CalRig's typical reference, or ±0.26 °C if the reference sensor is only as good as a maximum tolerance would allow [D4]. **R3 is met on paper.**

## E. Measurement height and pole shading (R9)

- **Height correction.** On a sunny afternoon the air near the pavement is warmer than at the sensor. At 1 m/s the estimate gives +0.72 °C at 1.1 m, +0.44 °C at 1.5 m and +0.21 °C at 2.0 m relative to the 2.69 m of the shield; at 3 m/s, +0.80, +0.50 and +0.24 °C [E1]. A node at 2.7 m therefore reads pedestrian-height air temperature low by up to about 0.8 °C in strong sun, which would enter WBGT at about 0.4 °C (section B). At night and in shade the difference is smaller or reversed. The radiant field changes less with height, because the pavement fills about half of the globe's view at any height above an open street; walls change this in narrow streets.
- **R9 is not met.** The target is unchanged under HMN-DDR-001 D2, decided by Amish on 2026-09-25; the correction above, with a pilot comparing 2.0 and 2.8 m (TRL 4, on hold), is the decided path. The fan cowl lowers the shield by 25 mm, so the sensors now sit at 2.67 to 2.69 m.
- **Pole shading of the globe.** From the globe, the 114 mm pole spans 13.0°. With the arm pointing east or west the sun would pass behind it for about 0.9 h a day. The arm now points toward the equator (HMN-DDR-002), so the pole is on the poleward side of the globe, which the sun reaches only in the tropics, near noon and high in the sky [E2].
- **Shading of the FieldNode panel.** With the core below the arm (v0.5 and earlier), the shield, cowl, globe and arm shaded 44 % of the panel at 30° elevation, 34 % at 45°, 27 % at 60° and 16 % at 75° with the sun straight along the arm, and less off axis. Amish decided on 2026-10-02 to mount the core above the arm, provided its lid stays reachable from the ladder or lift that fits the arm; the model now has the core's bottom at 3.11 m, its whip 100 mm or more above the arm. The sensor head is then wholly below the panel, and the shield, cowl, globe and arm shade 0 % of it at every sun position run (30 to 75° high, 0 to 60° off the arm's azimuth) [E3]. The reverse now needs checking: the panel and enclosure can shade the sensors, but only when the sun is on the pole side of the node. That happens only in the tropics near noon; there, a sun 45 to 75° high on the pole side shades the globe or the shield stack, and one 30° high shades the cups [E3b]. On the equator side, where the sun is outside the tropics, nothing is shaded. Shade on a series-connected panel could still cut its output by more than the shaded share, but the head no longer shades it.

## F. Sensor power (R7)

The temperature and humidity sensor takes about 11 µJ per reading, now 480 times a day, and the NTC divider 8 µJ, 1,440 times a day; with the anemometer's reed resting closed in the worst case (0.109 mW), the sensors alone draw 0.116 mW [F1], [F2]. The fan adds 35.3 mW (section C), for a total of 35.4 mW, 35 % of FieldNode's 100 mW design allowance (FND-CAL-001) [F2]. **R7 is met on paper**, with the margin now set by the fan. The panel shading in section E reduces harvest and is not included in FieldNode's energy budget.

## G. Payload, airtime and storage (R6)

- **Payload.** Eleven fields fit in 20 B: means of air temperature, humidity, globe temperature and wind, maxima of air and globe temperature, the gust, the share of the interval below the anemometer's start-up, battery voltage, status and a sequence number [G1]. The calm-share byte lets the server flag intervals where the MRT and WBGT are biased (sections A and B).
- **Airtime and storage.** At 96 uplinks a day the node uses 23.7 s/day of airtime at SF9 (FND-CAL-001). Seven days of records at FieldNode's 32 B each take 21.5 kB [G2]; the TRL 2 figure of 13 kB assumed 20 B records.
- **Calm flag.** The server marks MRT and WBGT as biased high in calm air for any interval whose calm share (time below the 0.8 m/s start-up) is 20 % or more, that is 3 min of 15 [G4]. This is the rule under the restated R4 (HMN-DDR-002); the threshold is a starting value for the pilot.
- **Latency.** Each 15 min mean is sent as its interval closes and reaches the gateway within about 16 min. The 1.02 % of uplinks lost at TwinKit's worst case arrive with the next uplink at about 31 min [G3]. **R6 is met on paper** for 99 % of intervals.

## H. Wind load, arm and clamp (R11)

- **Loads.** A 35 m/s gust across the arm puts 6.6 N on the globe, 10.7 N on the shield, 2.1 N on the fan cowl, 7.2 N on the anemometer and 19.9 N on the 530 mm arm: 46.5 N on the sensor head [H1]. The TRL 2 estimate of 110 N included the FieldNode panel and enclosure (88 N with the sun shield in FND-CAL-001 v0.2).
- **Arm.** The 25 x 25 x 2 mm tube (second moment of area 16,345 mm⁴) sees 14.6 N·m at its root and 11.1 MPa, a factor of 13.0 on yield [H2]. Its tip deflects 0.31 mm at 20 m/s and 0.95 mm at 35 m/s [H3], far inside the 10 mm of R11. Torsion from the offset loads is 0.84 N·m [H4].
- **Clamp.** Wind twists the arm about the pole with 18.1 N·m against 45.7 N·m of band friction, a factor of 2.5. The 1.37 kg on the arm, with its center of mass 425 mm out, pulls the upper band with 41 N against 2,000 N, and pushes down with 13 N against 800 N of friction [H5]. The formed 3 mm sheet saddle (now a channel whose V-notched flanges bear on the pole, HMN-DDR-003) carries these loads through the band preload; its bending stiffness has not been checked and should be at detail design. **R11 is met on paper**, subject to the preload, which a torque figure at installation must secure; the twist factor of 2.5 is the smallest margin in this section.
- **Pole.** The node adds 46 N (head) plus 88 N (FieldNode with its shield) and about 423 N·m at the pole base [H6] (338 N·m before the core moved above the arm, 2.15 m to 3.11 m up). The pole owner should check this against the pole's rating.

## I. Outdoor temperatures (R8)

- **Sensor head.** At 50 °C air and an 80 °C radiant field in near calm, the globe reaches 67.4 °C [I1]. The SHT45 and a 125 °C class epoxy NTC (assumed rating) are well within their limits; the ASA plates and aluminium arm are too.
- **FieldNode core.** HeatMap nodes now carry FieldNode's hot-climate sun shield (HMN-DDR-002). With it the core's interior runs up to 7.2 K above ambient when dusty with the sun in its worst position, 57.2 °C at 50 °C air, against a 70 °C electronics rating; without it the figure would be 78.3 °C [I2]. R8 is restated to +50 °C at the node, matching HMN-PRB-001. **R8 is met on paper**, resting on FieldNode's assumed shield factor.

## J. Fit to poles and installation (R10)

- **Fit.** A 120° V touches a round pole at ±r cos 60° from its center line: ±15 mm on a 60 mm pole, ±29 mm on a 114 mm pole and ±50 mm on a 200 mm pole, all inside the saddle's V notches (±55 mm at the flange edge) and the adapter V-blocks (±55 mm); strap bands 338 to 778 mm long cover the range [J1]. The FieldNode adapter uses the same 120° V, because FieldNode's own V-blocks only seat small poles (FND-DDR-003). The fit part of R10 is met by design, with no drilling.
- **Time.** The tasks add up to 37 min for two people working in turn from one lift, with the arm and its sensors assembled on the ground [J2], against 30 min. **R10 is at risk**; only a timed trial can settle it.

## K. Mass (R15)

- **Sensor head.** From the component volumes of the constructable model: arm with plug and sleeves 268 g, clamp (saddle, trim, cheeks, bands and bolts) 442 g, shield with rods and spacers 324 g, fan and cowl 78 g, sensor 20 g, globe with its brass hanger tube 348 g, probe 10 g, anemometer 307 g, harness 238 g (two leads cut for the core above the arm, 1.2 m and 1.4 m), lanyards 20 g and consumables 30 g: 2.08 kg [K1]. The design for construction added 0.21 kg (HMN-DDR-003).
- **Against R15.** R15 now covers the sensor head only (HMN-DDR-002), so 2.08 kg against 4.0 kg: **R15 is met on paper**. For information, with the FieldNode core and its sun shield (2.61 kg) and the pole adapter (0.22 kg) the complete node weighs 4.92 kg [K2]. The largest part other than the arm is the 290 mm FieldNode panel, within the 300 mm limit [K3].

## L. Cost (R13)

The BOM has 13 lines. Under HMN-DDR-002 the pole adapter (line 12) counts against the FieldNode core, as it fixes a FieldNode fit limit. The design for construction (HMN-DDR-003) repriced lines 2, 4, 8, 10 and 12, and line 1 follows FieldNode's own design for construction to $148.00. The sensor head (lines 2 to 11 and 13) is estimated at $136.00; the FieldNode core with its sun shield and the adapter (lines 1 and 12) at $156.00, and the full node at $292.00 [L1]. `budget_usd` is a hypothetical value-engineering target, not a spending limit (Amish, 2026-10-01). Value-engineering target: USD 130. Estimated cost of the constructable design: USD 136 (USD 6 over the target) [L2]. **R13 is over its value-engineering target by $6.00**; the cost drivers and savings worth trying are in the design decisions register (HMN-DEC-001).
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

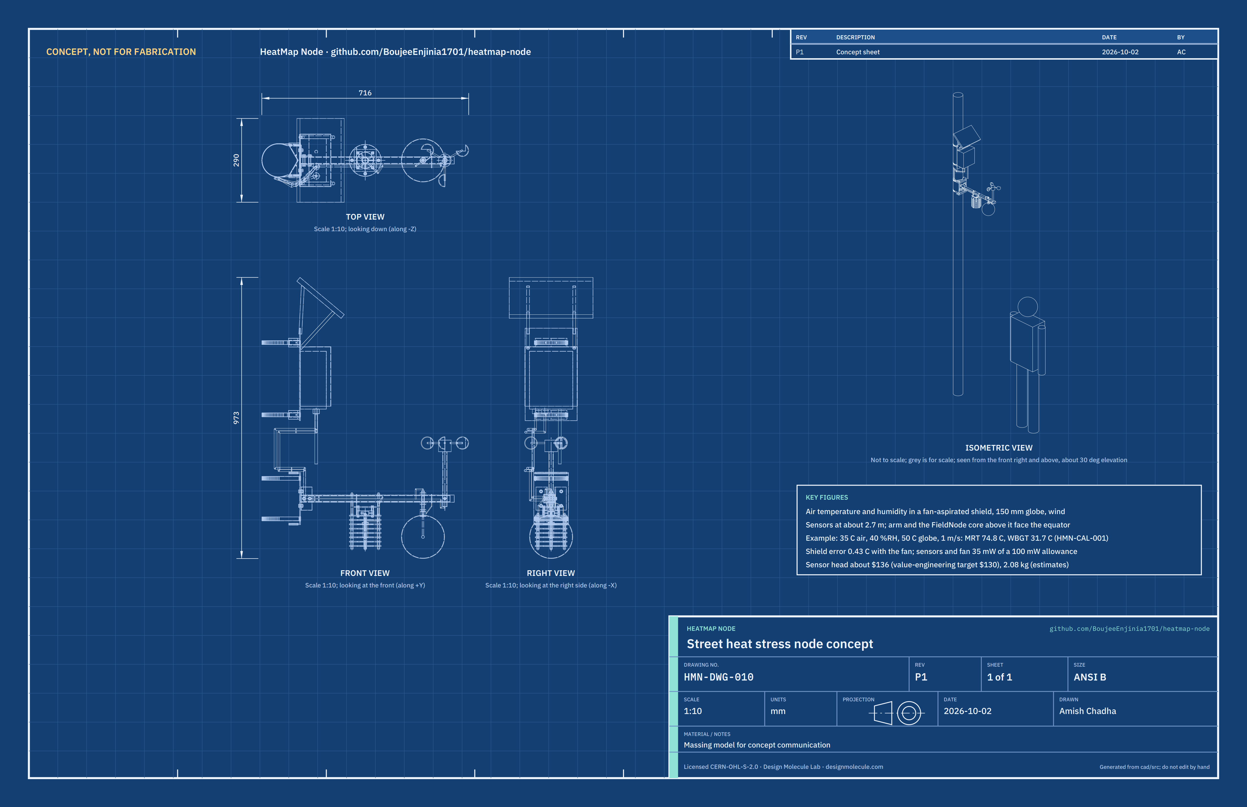
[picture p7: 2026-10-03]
media/concept-blueprint.png

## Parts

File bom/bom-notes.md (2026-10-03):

# BOM notes

Costs are indicative USD prices at quantity 1 for a TRL 3 paper design, with a supplier or supplier type for every line. They are not quotes. `docs/04-calcs/sizing.py` (HMN-CAL-001 v0.6, section L) reads `bom.csv` and checks the totals against `budget_usd` in `project.yaml`.

- Line numbers 1 to 9 and 11 to 13 match the callouts in `media/exploded.png`. Line 10 (hardware and consumables) has no callout.
- Sensor head (lines 2 to 11 and 13): $136.00. `budget_usd` ($130) is a hypothetical value-engineering target, not a limit (Amish, 2026-10-01): value-engineering target USD 130, estimated cost of the constructable design USD 136, USD 6 over the target. The design for construction (HMN-DDR-003) repriced lines 2, 4, 8, 10 and 12 for the parts that make the node buildable (cheeks, wider saddle and trim, a fourth rod and spacers, the globe hanger tube, bolts, sleeves, an end plug and cable ties): $9 on the head. Cost drivers and savings worth trying are in the design decisions register (HMN-DEC-001).
- FieldNode side (lines 1 and 12): $156.00. Line 1 is the hot-climate FieldNode node with its sun shield, $148.00 after FieldNode's own design for construction (FND-DDR-003), costed in the FieldNode repo. Full node: $292.00, for information.
- Line 12 replaces the FieldNode kit's V-blocks and band clamps, which only seat small poles. The unused parts are still in FieldNode's $148.00. A large-pole FieldNode kit variant is listed as a cross-repo action.
- Line 3 accuracy is the typical figure from the Sensirion product page. Line 6's start-up speed and line 13's power and flow are typical values for the class, not checked against a chosen part.
- The street pole, gateway (TwinKit or a public LoRaWAN network), calibration in CalRig, installation labor and traffic management are not included.
- Line 9 (harness) is re-specified for the FieldNode core above the arm (HMN-DEC-001, item 3, 2026-10-02): lead A about 1.2 m and lead B about 1.4 m instead of 1.5 m each; the price stays $12.00 because the connectors set it. Totals are unchanged: sensor head $136.00, full node $292.00.

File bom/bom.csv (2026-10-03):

item | qty | spec | supplier | unit_cost_usd | make_buy | notes
1 FieldNode core | 1 | FieldNode shared outdoor core per FND-DWG-001 Rev P3, hot-climate build, built to FND-BLD-001 except its two V-blocks and band clamps (replaced by line 12): IP65 enclosure 150 x 90 x 200 mm with vent and lugs, ventilated white sun shield (FieldNode BOM line 14), 6 W 9 V class panel as sun hood, 3.2 V 6 Ah LiFePO4 cell, MPPT power board, STM32WL-class LoRaWAN module, whip antenna, two M12 5-pin sensor ports, back plate with band slots | FieldNode project (its bom/bom.csv) | 148.00 | make | FieldNode hot-climate node $148.00 after its design for construction (FND-DDR-003, FND-CAL-001 v0.4); costed in the FieldNode repo (HMN-DDR-001 D1) and excluded from the sensor head; FieldNode's own V-blocks and band clamps stay in that figure but are not fitted on a HeatMap node
2 Multi-plate radiation shield | 1 | Eight 110 mm white plates at 15 mm pitch, 3 mm thick, UV-stable white ASA print: top plate with a 56 mm hole under the fan; seven ring plates with a 56 mm hole and four 10 mm bosses 12 mm tall; the third plate carries a 22 mm sensor hub on three spokes. Four M5 316 stainless threaded rods on a 92 mm circle with acorn nuts below and nuts above; two rods continue through the arm on 8 mm aluminium tube spacers 41 mm long | Local make (3D print) plus hardware shop | 15.00 | make | Indicative material cost; fan-aspirated (line 13); four rods and two spacers in place of three rods (HMN-DDR-003); radiation error in HMN-CAL-001 section C
3 Air temperature and humidity sensor | 1 | Sensirion SHT45 digital sensor (typical ±0.1 °C and ±1.0 %RH) on a small board with PTFE membrane cap, I2C, on an M12 lead | Electronics distributor | 14.00 | buy | Indicative price; accuracy from the Sensirion product page; calibrate in CalRig
4 Black globe | 1 | 150 mm thin-wall copper sphere (float ball, about 0.4 mm wall), outside painted matte black (emissivity about 0.95), top boss tapped M10 x 1 (or with an adapter to M10 x 1); hung from the arm on a hollow M10 x 1 brass threaded tube (lamp rod, 7 mm bore) about 90 mm long with three M10 x 1 nuts; the probe passes down the tube | Plumbing or hardware supplier | 24.00 | buy | Indicative price; standard 150 mm globe (HMN-DDR-001 D3); hanger tube and nuts $2.00 added under HMN-DDR-003
5 Globe temperature probe | 1 | 10 k NTC epoxy bead thermistor (B about 3950) on a 5 mm stiff tube, bead held at the globe center, sealed at the boss | Electronics distributor | 4.00 | buy | Indicative price; calibrated in CalRig before it is fitted to the globe
6 Cup anemometer | 1 | Three-cup anemometer with reed or Hall pulse output, about 0.8 m/s start-up (typical low-cost class, unverified), 44 mm cups on a 16 mm tube mast that passes through the arm, 170 mm above it, held by one M5 cross bolt | Weather station spare-parts supplier | 32.00 | buy | Indicative price; start-up speed misses R4 (HMN-CAL-001)
7 Sensor arm | 1 | 25 x 25 x 2 mm 6063 aluminium square tube, 530 mm, drilled for the cheek bolts, the two long shield rods, the globe hanger tube and the anemometer mast and its cross bolt | Local make from metal stockist | 9.00 | make | Indicative material cost; 10 mm longer than the concept so the anemometer keeps its place after the saddle change (HMN-DDR-003)
8 Arm clamp and bands | 1 | Formed 3 mm 5052-H32 aluminium sheet channel 120 wide x 180 tall x 40 deep: a web with four cheek bolt holes and four band slots, and top and bottom flanges with 120 degree V notches lined with 1.5 mm EPDM rubber edge trim; two arm cheeks of 40 x 40 x 3 mm aluminium angle, 80 mm long; two 13 mm 316 stainless strap bands with buckles, cut to length for 60 to 200 mm poles | Hardware shop plus local make | 8.00 | make | Indicative price; formed sheet saddle (HMN-DDR-002) made buildable under HMN-DDR-003: V notches in the flanges, 120 mm wide so a 200 mm pole still seats, cheeks to hold the arm; no drilling of the pole
9 Sensor harness | 1 | Two outdoor cables, lead A about 1.2 m and lead B about 1.4 m, with M12 5-pin A-coded plugs, UV-stable jacket, cable ties to the arm | Industrial connector distributor | 12.00 | buy | Indicative price; lengths re-specified for the core above the arm (HMN-DEC-001, 2026-10-02): the model's runs are 0.83 m and 1.05 m from the ports to the arm sensors, plus the sensor tails and slack; the shorter cable does not change the connector-led price
10 Hardware and consumables | 1 | Stainless fixings: 2 x M6 x 40 hex bolts and 4 x M6 x 16 button-head screws with nyloc nuts (cheeks), 2 crush sleeves of 8 x 0.8 mm aluminium tube 21 mm long, 1 x M5 x 35 bolt with nyloc nut (mast), 4 x M4 x 40 pan-head screws with nuts (fan and cowl); 25 mm square tube end plug; about 12 UV-stable cable ties 400 mm long; matte black high-temperature paint; sealant | Hardware shop | 8.00 | buy | Indicative price; no exploded-view callout; fixings added under HMN-DDR-003
11 Secondary retention lanyards | 1 | Two 1.5 mm 316 stainless wire lanyards with ferrules and snap hooks, globe boss and shield top to the arm | Hardware or rigging shop | 3.00 | buy | Added at TRL 3 to keep the globe and shield from falling if a fixing fails
12 FieldNode pole adapter | 1 | Two 120 degree V-blocks 110 x 30 x 38 mm printed in ASA at 100 % infill, each with two 3.5 x 16 mm band slots in line with the FieldNode back plate slots and two M4 brass heat-set inserts for FieldNode's M4 countersunk screws; two 13 mm 316 stainless strap bands with buckles | Local make (3D print) plus hardware shop | 8.00 | make | Added at TRL 3; seats the FieldNode core on 60 to 200 mm poles; counted against FieldNode, not the sensor head (HMN-DDR-002); V and band slots made buildable under HMN-DDR-003; a large-pole FieldNode kit variant is a cross-repo action
13 Aspiration fan and cowl | 1 | 60 x 60 x 15 mm 5 V DC ball-bearing fan (about 0.9 W, about 14 CFM free air, class values) screwed flat on the top shield plate over its 56 mm hole; printed UV-stable ASA cowl, a 76 x 76 mm lid on four legs over the fan's corner holes, 30 mm overall, exhausting sideways; four M4 screws through cowl, fan and plate; powered from the FieldNode switched 5 V rail through the T and RH sensor lead | Electronics distributor plus local make (3D print) | 7.00 | buy | Indicative price ($6 fan, $1 cowl material); added under HMN-DDR-002; runs 6 s before each air reading every 3 min

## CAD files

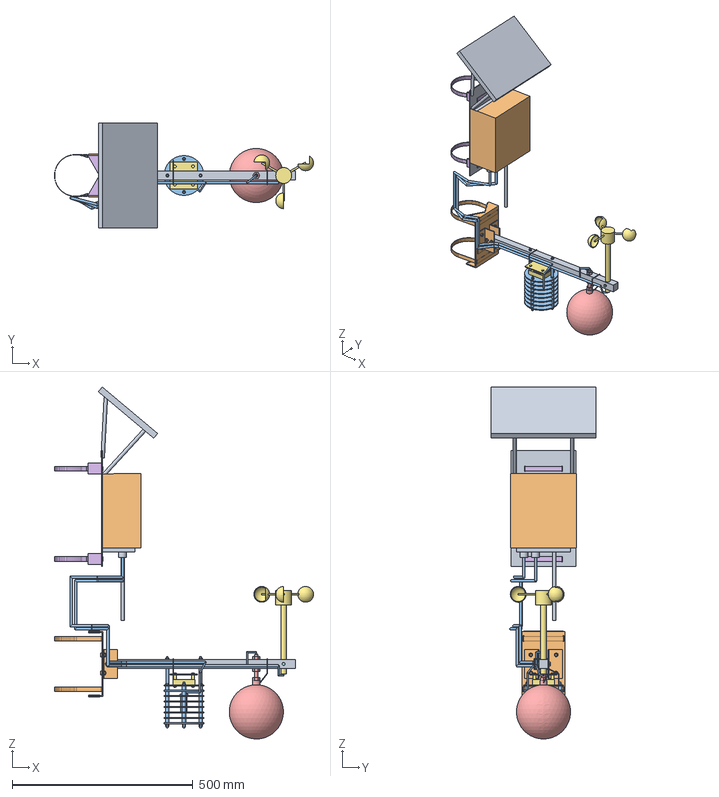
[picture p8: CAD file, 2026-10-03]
cad/step/heatmap-node-assembly.step
716.3 x 290.0 x 973.3 mm

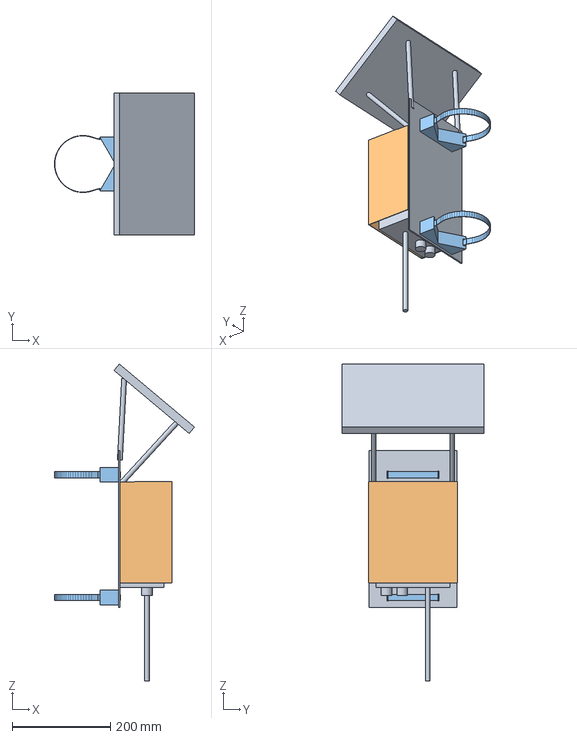
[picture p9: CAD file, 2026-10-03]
cad/step/fieldnode-core-envelope.step
285.4 x 290.0 x 645.8 mm

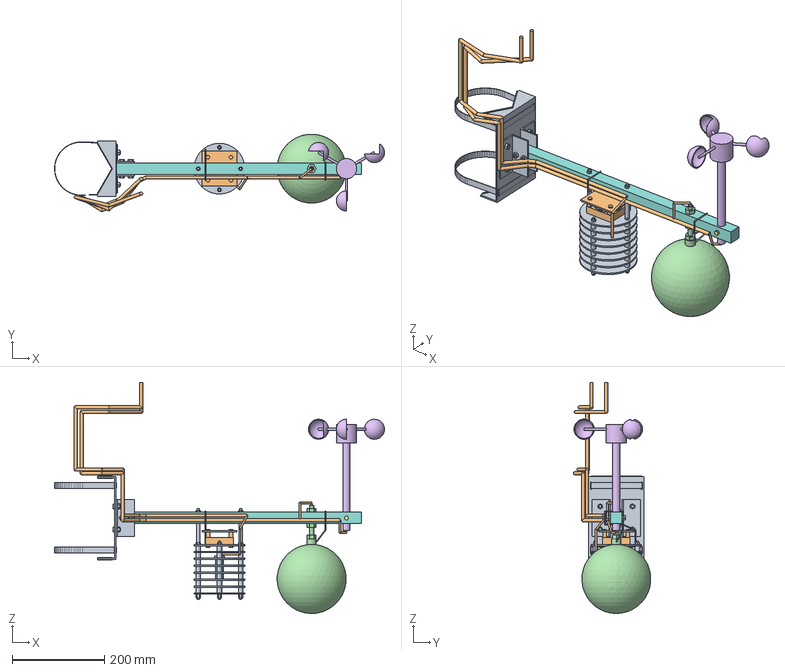
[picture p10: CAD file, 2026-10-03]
cad/step/sensor-head.step
716.3 x 168.1 x 501.5 mm

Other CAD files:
cad/stl/fieldnode-core-envelope.stl
cad/stl/heatmap-node-assembly.stl
cad/stl/sensor-head.stl

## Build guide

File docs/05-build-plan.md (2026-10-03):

---
doc_id: HMN-BLD-001
title: HeatMap Node prototype build plan
project: HeatMap Node
doc_type: Build plan
version: "0.3"
status: Draft
date: '2026-10-02'
author: Amish Chadha
license: CERN-OHL-S-2.0
revisions:
  - version: "0.1"
    date: '2026-10-01'
    author: Amish Chadha
    change: First build plan at TRL 3, with pictures by component and step; design made constructable (HMN-DDR-003)
  - version: "0.2"
    date: '2026-10-02'
    author: Amish Chadha
    change: "Step 12 gives the sensor port pinout decided by Amish on 2026-10-02 (HMN-DEC-001)"
  - version: "0.3"
    date: '2026-10-02'
    author: Amish Chadha
    change: "FieldNode core moved above the arm (HMN-DEC-001, item 3): steps 14 to 16 reordered and redrawn, harness leads re-specified, pictures redrawn"
---

# HeatMap Node prototype build plan

**Plan, not yet built.** How to build the first proof-of-concept prototype, component by component. Building and testing to it is TRL 4 work. Decisions still to be made are kept in the design decisions register ([docs/06-design-decisions.md](06-design-decisions.md)), not here.

## 1. What you are building

Figure 1. Every component, pulled apart and numbered in build order

*Figure 1. Every component pulled apart and numbered in build order. The pole is not shown.*

The prototype is one HeatMap Node on a street pole: a sensor head on a short aluminium arm, about 2.8 m up, and a FieldNode core above it, its bottom at about 3.1 m, that powers the sensors and sends their readings by radio. The arm carries a stack of white plates with a small fan on top and an air temperature and humidity sensor inside, a 150 mm black globe with a temperature probe at its centre, and a cup anemometer at its tip. Figure 1 shows the 19 components in the order you make or fit them. Six kinds are made in a small workshop: the arm saddle (a bent aluminium sheet), two arm cheeks, the arm, the printed shield plates, the printed fan cowl and two printed V-blocks that seat the FieldNode core on a large pole. Everything else is bought and fitted, and the FieldNode core is built to its own plan (FND-BLD-001) with these V-blocks in place of its own. The work is sawing, drilling and filing aluminium, one sheet-metal bending job that a local shop can do, 3D printing in ASA, cutting threaded rod and tube to length, and plugging in bought sensors. The sensor head's parts cost about $136, from the bill of materials.

> **Safety:** The node is fitted at about 2.7 to 3.6 m on a street pole next to traffic: that work needs the pole owner's written permission, a lift or a stable ladder with a second person, fall protection and traffic management, and must stay clear of overhead lines and any live parts of a lighting pole. The FieldNode core holds a lithium iron phosphate cell of about 19 Wh; follow the cell stops in its own build plan. The black globe gets hot in sun (about 67 °C at 50 °C air), the cups spin, and the fan starts by itself every 3 minutes once powered. Cut aluminium edges are sharp: deburr everything. Printing ASA gives off fumes; print in a ventilated space.

## 2. What changed to make it buildable

The concept showed what the node does; some of its parts could not be made or fixed as drawn. Each change below keeps what the node does, and all of them are recorded in decision record HMN-DDR-003, open for Amish's review.

*Table 1. Changes from the concept.*

| Component | The concept had | The buildable design has | Why |
| --- | --- | --- | --- |
| Arm saddle | A closed tray 110 wide with a round seat for one pole size | A channel bent from 3 mm sheet, 120 wide, with a V notch in each flange lined with rubber trim (Figures 2 and 3) | A sheet can be bent this way, and the V seats any pole from 60 to 200 mm |
| Arm to saddle | No fixing | Two angle cheeks bolted to the saddle, the arm bolted between them through crush sleeves (Figure 5) | Every joint is face to face and bolted |
| Strap bands | Rings through the saddle | Through slots in the saddle and across its front (Figure 3) | The buckle sits where it can be reached |
| Shield | Three rods through solid plates, two of them inside the fan cowl; hung on one unfixed rod | Four rods clear of the cowl, printed bosses between plates, two rods up through the arm on spacers (Figure 10) | The stack is clamped and hangs rigidly from the arm |
| Fan and cowl | Floating, no fixing | Fan flat on the top plate, cowl on legs over the fan's corner holes, four screws through all three (Figure 13) | One set of screws holds both |
| Sensor | Floating in the stack | Held in a hub printed on the third plate (Figure 11) | Stays at the centre of the air path |
| Globe hanger | A solid rod meeting the probe at the same point | A hollow threaded brass tube, nutted to the arm; the probe runs down inside it (Figure 16) | The hanger and the probe share one path |
| Anemometer | Standing on the arm with no fixing | Mast through the arm, pinned with one bolt; arm 10 mm longer (Figure 17) | Cannot tip or turn |
| Harness and lanyards | Passing through parts; ending at the arm | Rerouted round every part; lanyards looped round the arm | Every cable and wire has a real path |
| FieldNode core position | Below the arm, its bottom at 2.15 m, with the sensor leads running up the pole to the arm | Above the arm, its bottom at 3.11 m so that its antenna whip clears the arm by 100 or more; the leads run from the ports up the pole and down to the arm | The sensor head no longer shades the core's solar panel, and the core's lid is reached from the same ladder or lift that fits the arm |
| FieldNode adapter | Flat blocks for one pole size, covering FieldNode's band slots | V-blocks with band slots and inserts at FieldNode's screw holes (Figure 15) | Fits the FieldNode back plate with no new holes |

## 3. Making the components

Make and check each component before the assembly step that needs it. Sizes are in millimetres. "Root" is the end of the arm at the pole, "tip" the far end; "left" and "right" are as seen standing at the arm tip, looking back at the pole. Workshop tolerance is 0.5 mm unless a step says otherwise; drawings do not carry tolerances before TRL 4.

### 3.1 Arm saddle

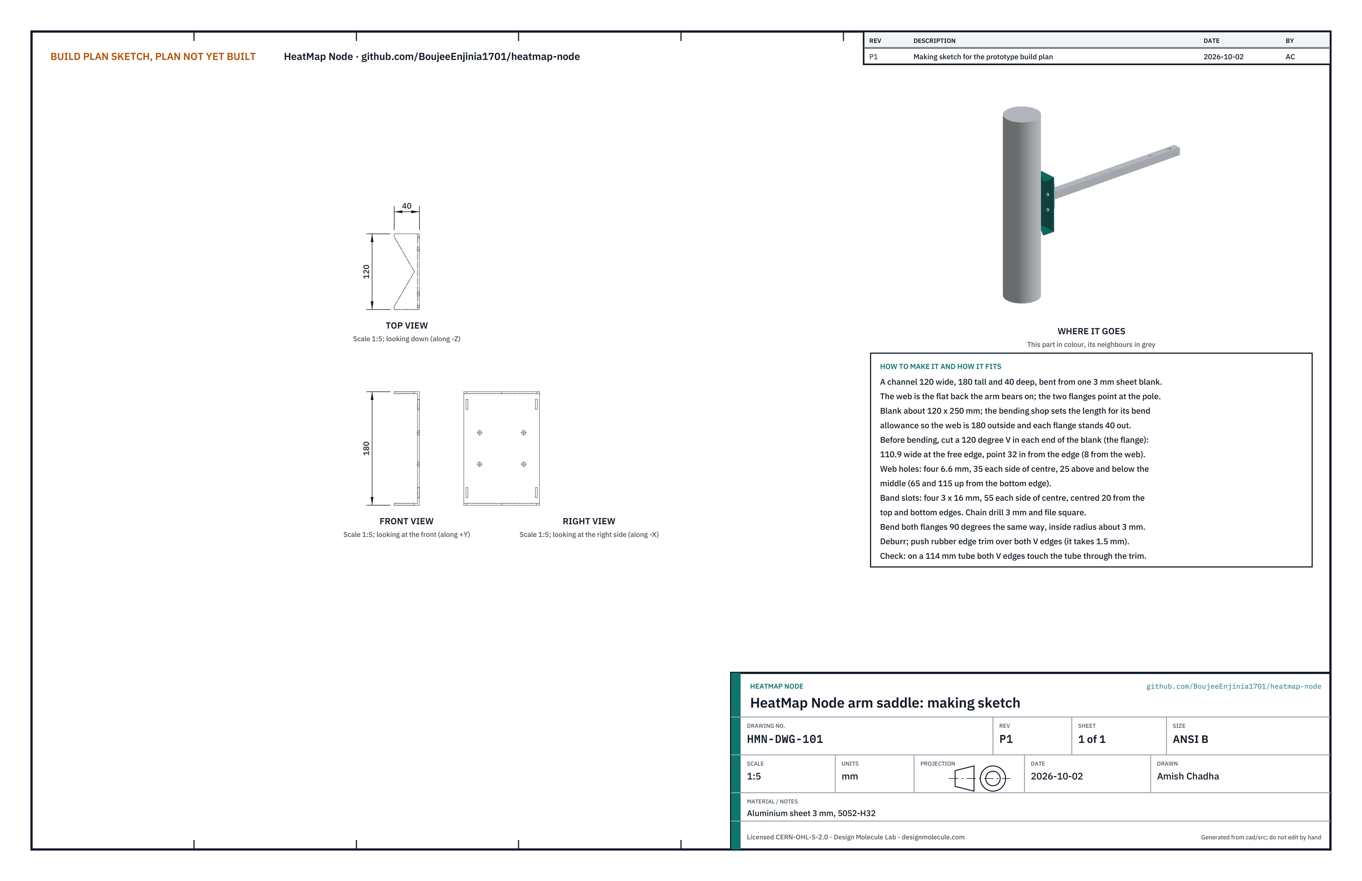
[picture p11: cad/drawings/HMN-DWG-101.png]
Figure 2. Making sketch of the arm saddle


*Figure 2. Arm saddle making sketch (HMN-DWG-101).*

**What it is and what it is made from.** The bracket that the arm bolts to and that the strap bands pull against the pole. Aluminium sheet 3 mm thick, 5052-H32 (it bends without cracking), bent into a channel 120 wide, 180 tall and 40 deep.

**How to make it.**

1. Cut a blank 120 wide and about 250 long. Ask the bending shop for the exact length for its bend allowance: the web must be 180 outside and each flange must stand 40 out from the web's outer face.
2. At each end of the blank (these become the flanges), mark a 120° V centred on the width: 110.9 wide at the end, its point 32 in from the end. Saw and file to the lines. About 4.5 of material stays at each corner.
3. On the web, drill four 6.6 holes for the cheek screws: 35 each side of the centre line, 65 and 115 up from the bottom bend line.
4. Cut four band slots 3 wide and 16 tall: 55 each side of the centre line, centred 20 in from each bend line. Chain drill 3 mm and file square.
5. Bend both flanges 90° the same way, inside radius about 3 mm.
6. Deburr every edge and hole. Push rubber edge trim over both V edges, starting at the point of the V.

**How it fits the parts next to it.**

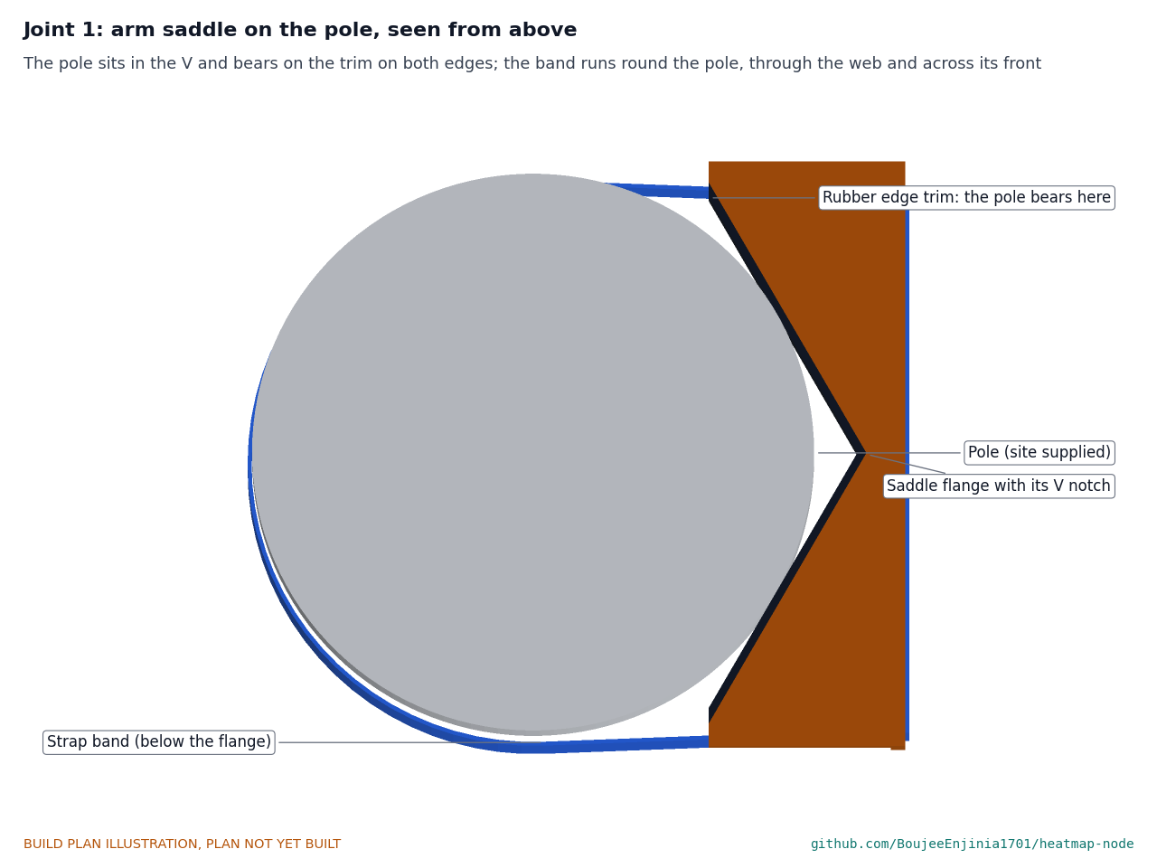
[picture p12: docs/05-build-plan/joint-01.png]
Figure 3. Joint 1: arm saddle on the pole


*Figure 3. The pole bears on the trimmed V edges of both flanges; each band runs round the back of the pole, through two slots in the web and across its front.*

The pole touches both edges of each V through the trim: a 114 mm pole 29 each side of centre, a 60 mm pole 15 each side and a 200 mm pole 50 each side, always inside the notch. The flat web faces away from the pole and carries the cheeks (Figure 5). The two bands sit 70 above and below the arm's centre line, clear of the cheeks.

**Check before moving on.** Hold the saddle against a 114 mm tube: it must not rock, and both flanges must touch the tube through the trim with the web square to the tube.

### 3.2 Arm cheeks (make 2)

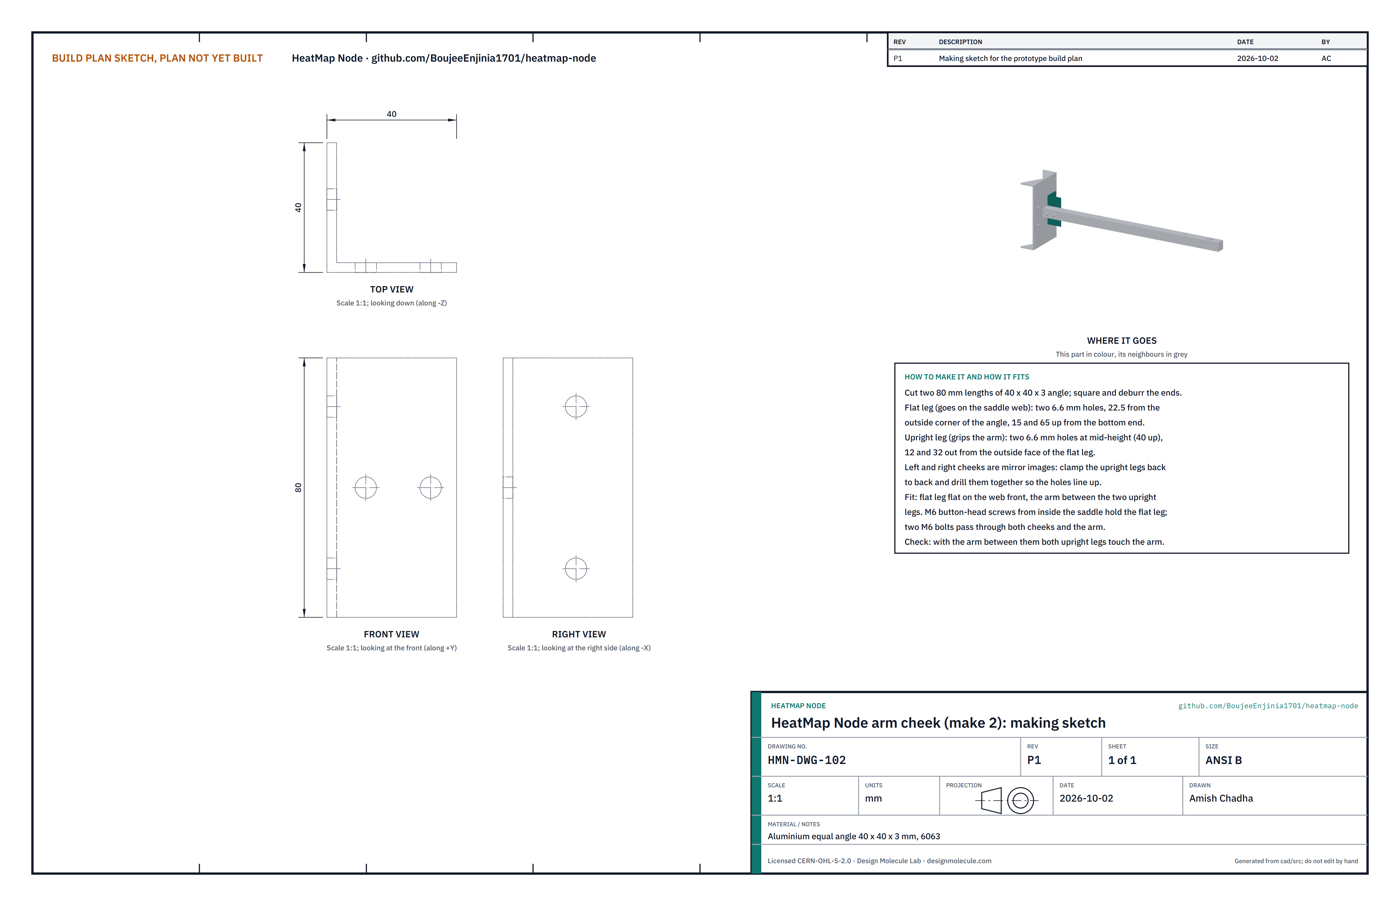
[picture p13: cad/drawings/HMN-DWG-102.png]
Figure 4. Making sketch of the arm cheek


*Figure 4. Arm cheek making sketch (HMN-DWG-102).*

**What it is and what it is made from.** Two short angles that grip the root of the arm and bolt it to the saddle. Aluminium equal angle 40 x 40 x 3, 6063.

**How to make it.**

1. Cut two 80 lengths; square and deburr the ends.
2. Flat leg (the one that goes on the saddle): two 6.6 holes, 22.5 from the outside corner of the angle, 15 and 65 up from the bottom end.
3. Upright leg (the one that grips the arm): two 6.6 holes at mid-height (40 up), 12 and 32 out from the outside face of the flat leg.
4. Clamp the two upright legs back to back and drill them together so the holes match. The two cheeks are mirror images.

**How it fits the parts next to it.**

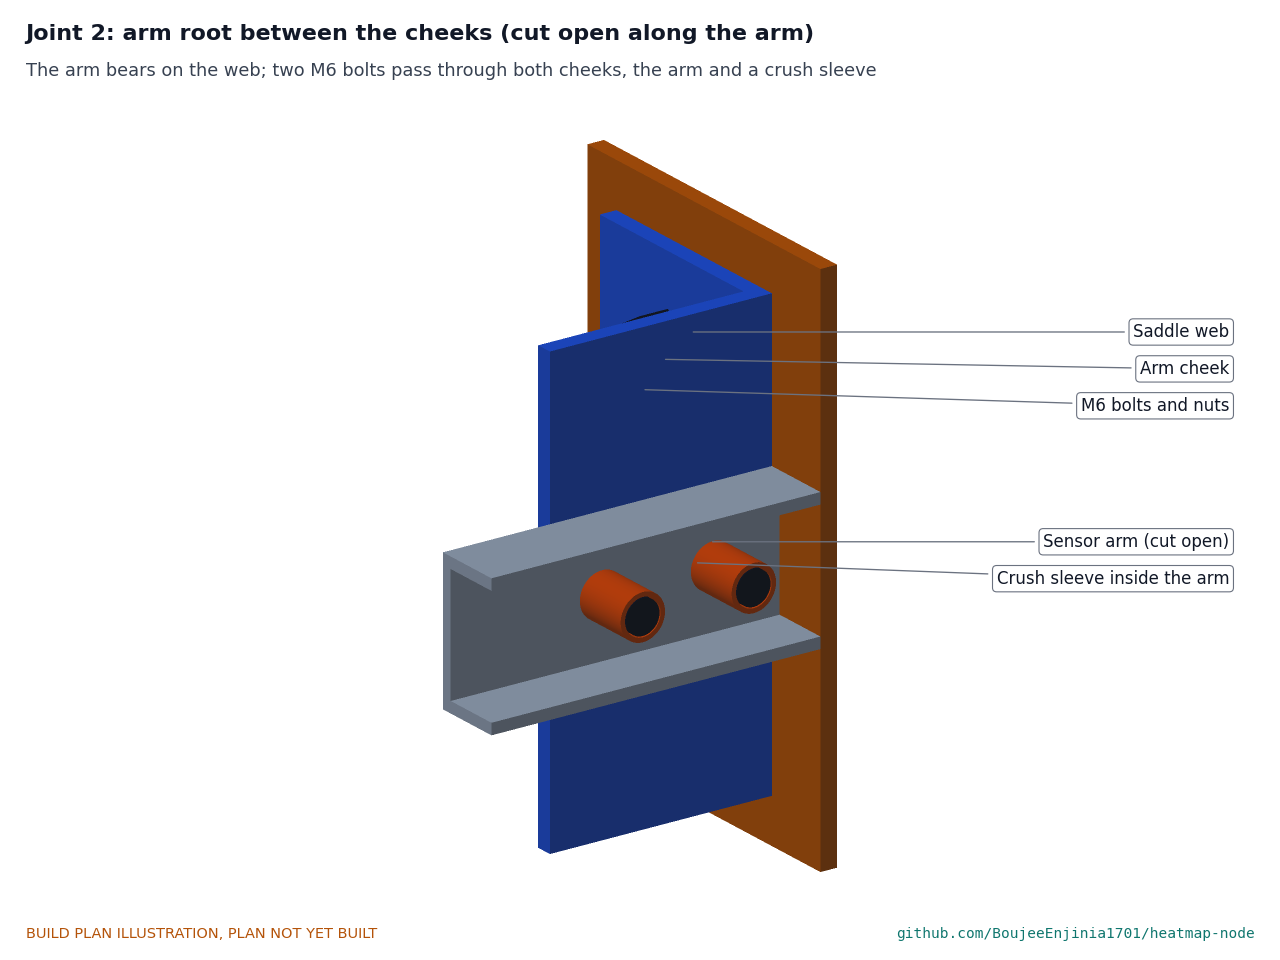
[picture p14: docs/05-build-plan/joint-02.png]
Figure 5. Joint 2: arm root between the cheeks


*Figure 5. The arm's end bears on the saddle web between the cheeks; two M6 bolts pass through both cheeks, the arm and a crush sleeve inside the arm.*

Each flat leg lies flat on the front of the web, held by two M6 x 16 button-head screws put in from inside the saddle with nyloc nuts on the cheek. The upright legs stand out from the web 25 apart, and the arm fits between them, touching both. The crush sleeves inside the arm stop its 2 mm walls folding when the bolts are tightened.

**Check before moving on.** The holes in both cheeks and the saddle line up without forcing a screw.

### 3.3 Sensor arm

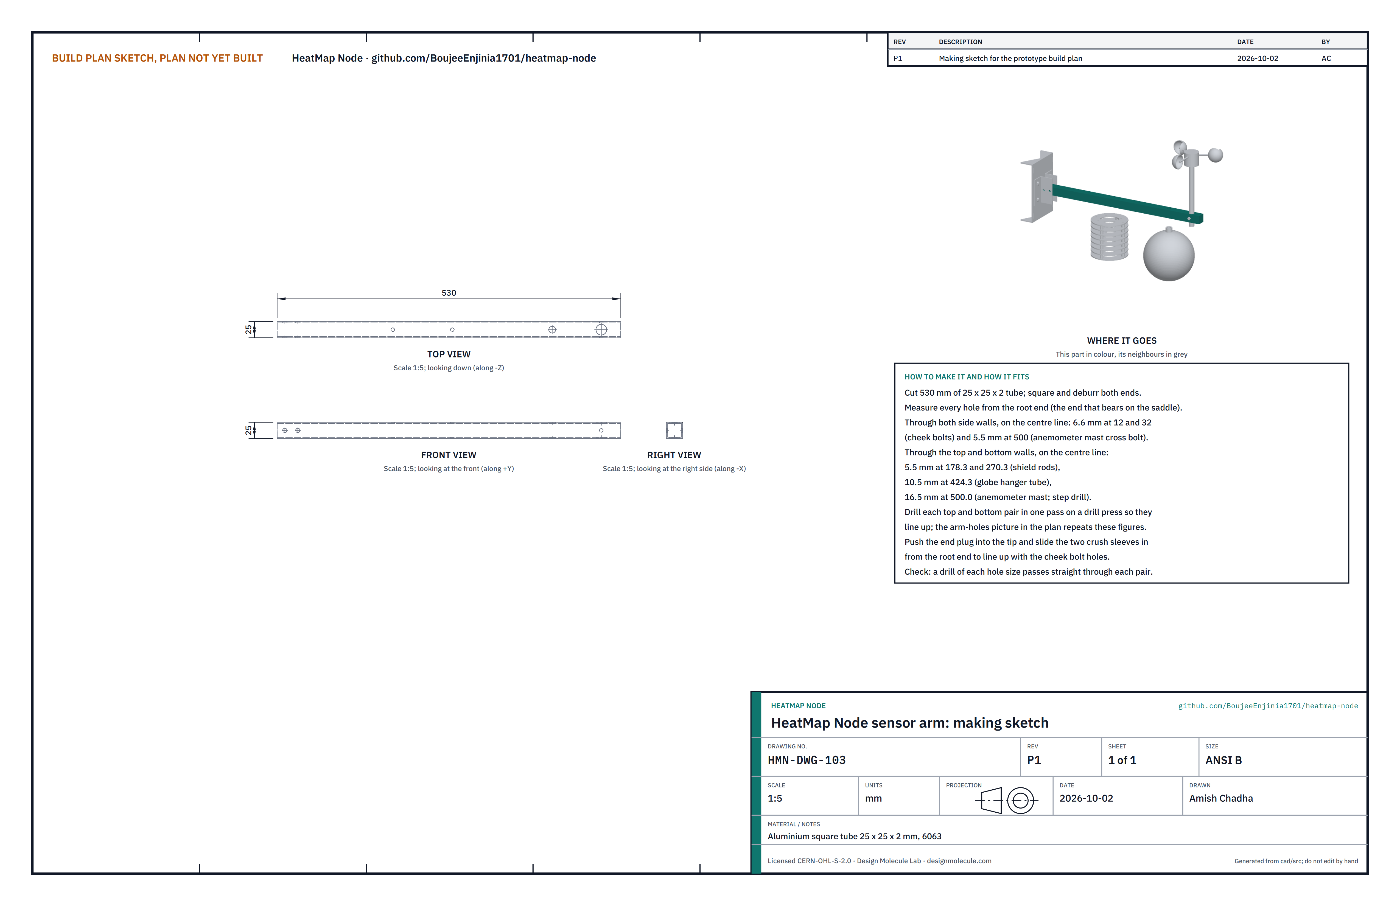
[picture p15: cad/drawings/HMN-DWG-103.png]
Figure 6. Making sketch of the sensor arm


*Figure 6. Sensor arm making sketch (HMN-DWG-103).*

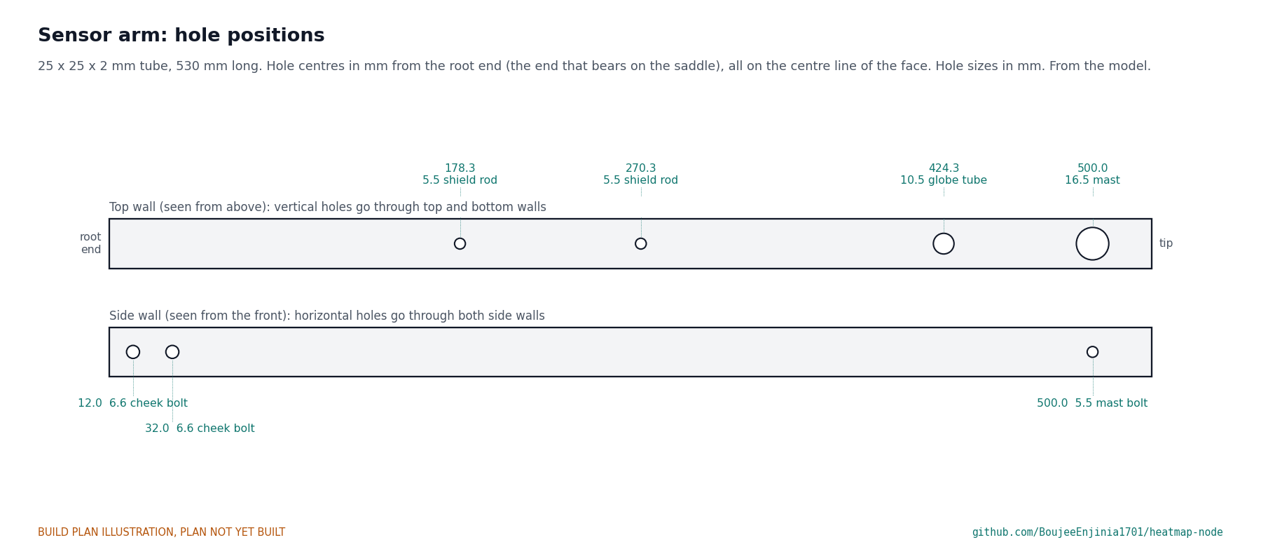
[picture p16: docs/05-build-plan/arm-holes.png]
Figure 7. Hole positions along the arm


*Figure 7. Every hole, measured from the root end, all on the centre line of their face.*

**What it is and what it is made from.** The arm that holds the shield, the globe and the anemometer about 250 to 500 out from the pole. Aluminium square tube 25 x 25 x 2, 6063, 530 long.

**How to make it.**

1. Cut 530 of tube; square and deburr both ends. Mark the root end.
2. Through both side walls, on the centre line: 6.6 holes at 12 and 32 from the root (cheek bolts) and a 5.5 hole at 500 (the pin through the anemometer mast).
3. Through the top and bottom walls, on the centre line: 5.5 holes at 178.3 and 270.3 (shield rods), a 10.5 hole at 424.3 (globe hanger tube) and a 16.5 hole at 500.0 (anemometer mast; open it with a step drill).
4. Drill each pair of holes in one pass on a drill press with the tube clamped square, so the two holes of a pair line up.
5. Cut two crush sleeves 21 long from 8 mm aluminium tube with a 0.8 mm wall. Push them in from the root end until they line up with the cheek bolt holes.
6. Push the plastic end plug into the tip.

**How it fits the parts next to it.** The root end bears flat on the saddle web between the cheeks (Figure 5). The shield rods, the globe tube and the anemometer mast pass down through their holes (Figures 10, 16 and 17). The sensor leads run along the side that faces left as you stand at the tip, held by cable ties.

**Check before moving on.** A drill of each hole size passes straight through each pair of holes.

### 3.4 Shield plates (8): seven ring plates and a top plate

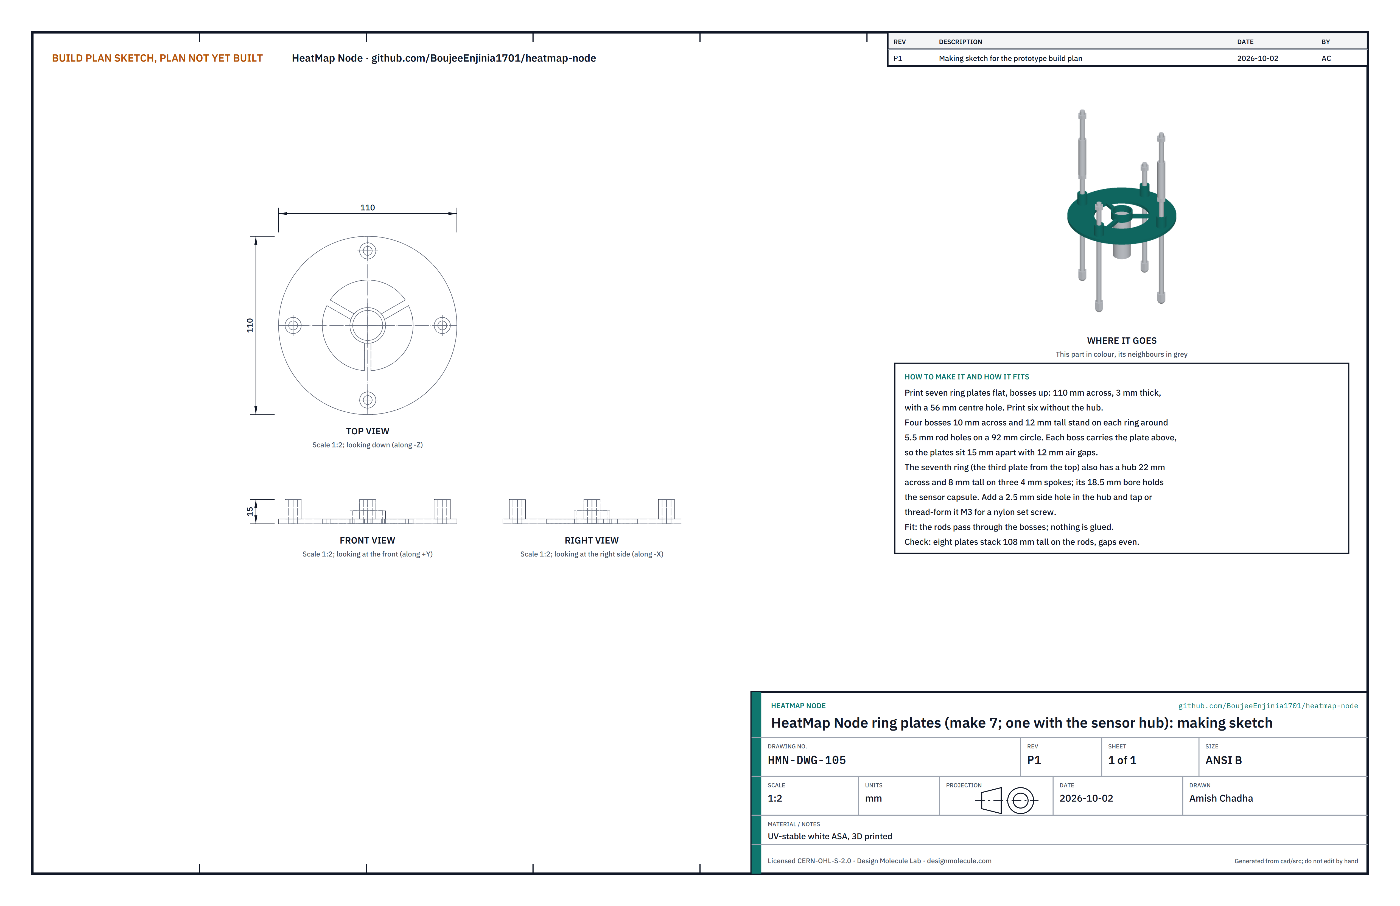
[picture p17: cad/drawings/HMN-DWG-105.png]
Figure 8. Making sketch of the ring plates


*Figure 8. Ring plate making sketch (HMN-DWG-105), drawn with the sensor hub that only the third plate carries.*

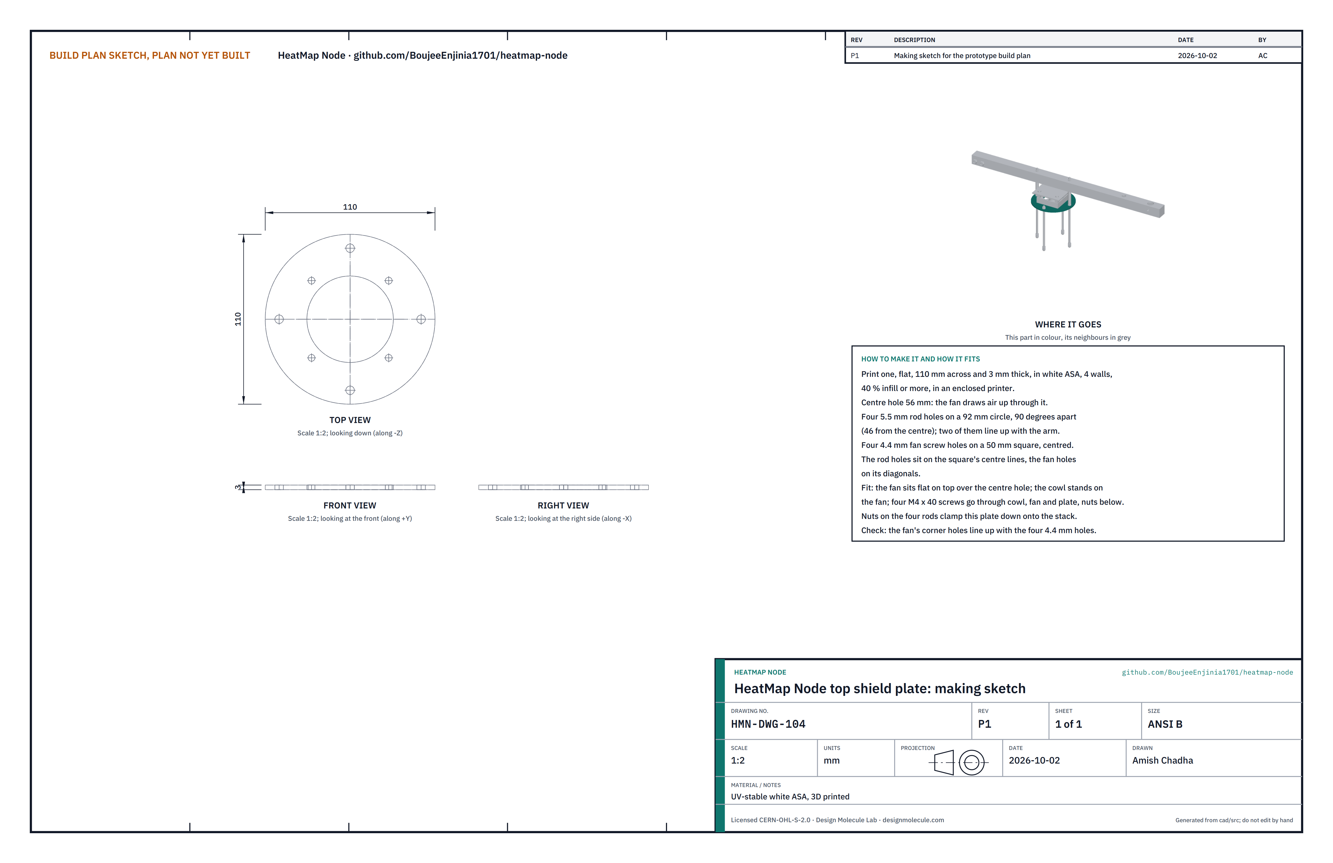
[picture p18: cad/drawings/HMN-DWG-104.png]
Figure 9. Making sketch of the top plate


*Figure 9. Top plate making sketch (HMN-DWG-104).*

**What it is and what it is made from.** Eight white plates, 15 apart, that shade the sensor from the sun and let air through. UV-stable white ASA, printed flat in an enclosed printer, 4 walls and at least 40 % infill.

**How to make it.**

1. Print six ring plates: 110 across, 3 thick, a 56 centre hole, and four bosses 10 across and 12 tall around 5.5 rod holes on a 92 circle, 90° apart. Print them bosses up; they need no supports.
2. Print the seventh ring plate the same, with a hub 22 across and 8 tall in the centre hole on three 4 mm spokes. Its bore is 18.5. Add a 2.5 side hole through the hub wall and form an M3 thread in it with the nylon set screw.
3. Print the top plate: 110 across, 3 thick, a 56 centre hole, four 5.5 rod holes on the same 92 circle, and four 4.4 fan screw holes on a 50 square, centred, on the diagonals between the rod holes. No bosses.
4. Remove any stringing from the holes with a drill of the hole size.

**How it fits the parts next to it.**

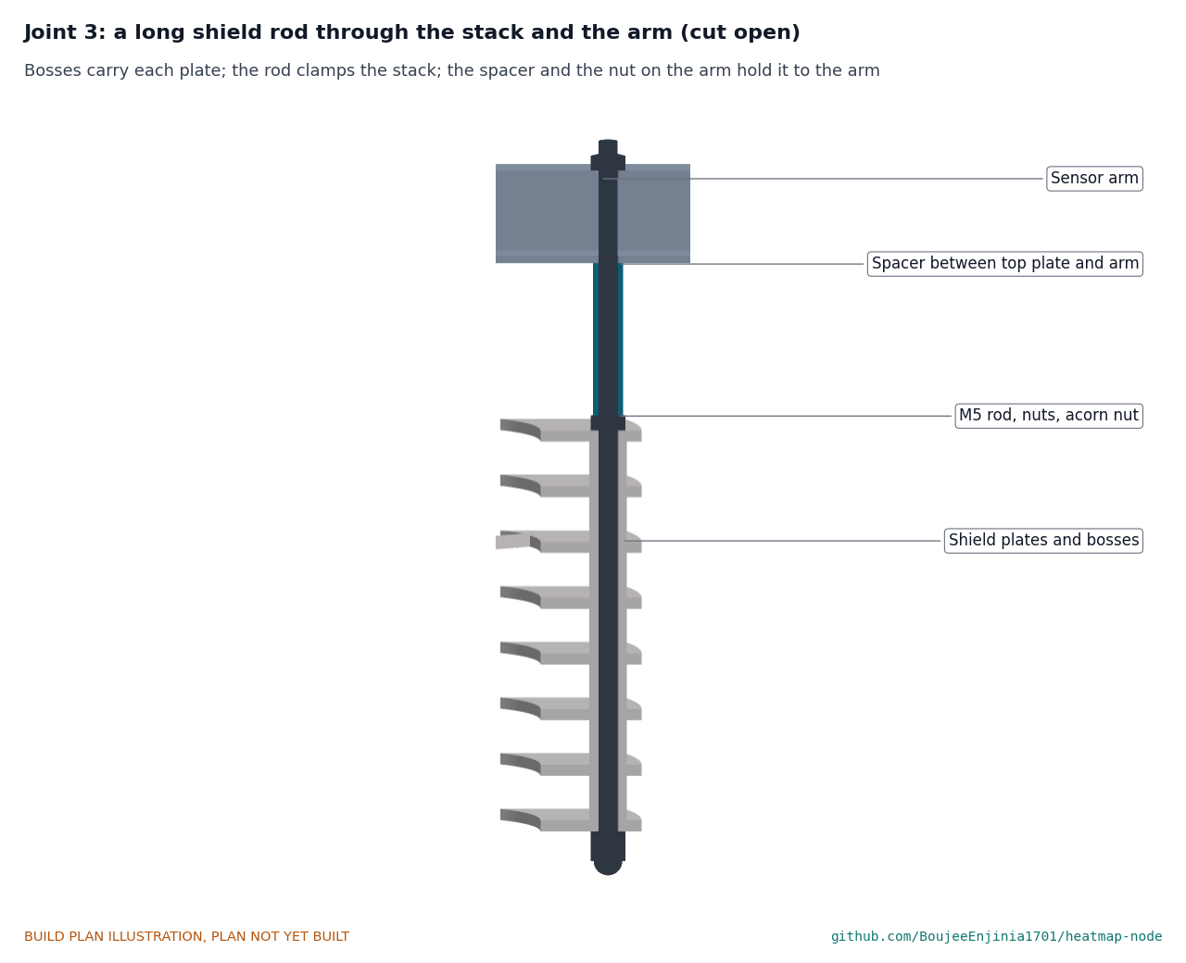
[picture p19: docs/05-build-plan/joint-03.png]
Figure 10. Joint 3: a long shield rod through the stack and the arm


*Figure 10. The bosses of each plate carry the plate above. An acorn nut under the bottom plate and a nut on the top plate clamp the stack; the two rods in line with the arm continue up through a spacer and the arm to a nut on top.*

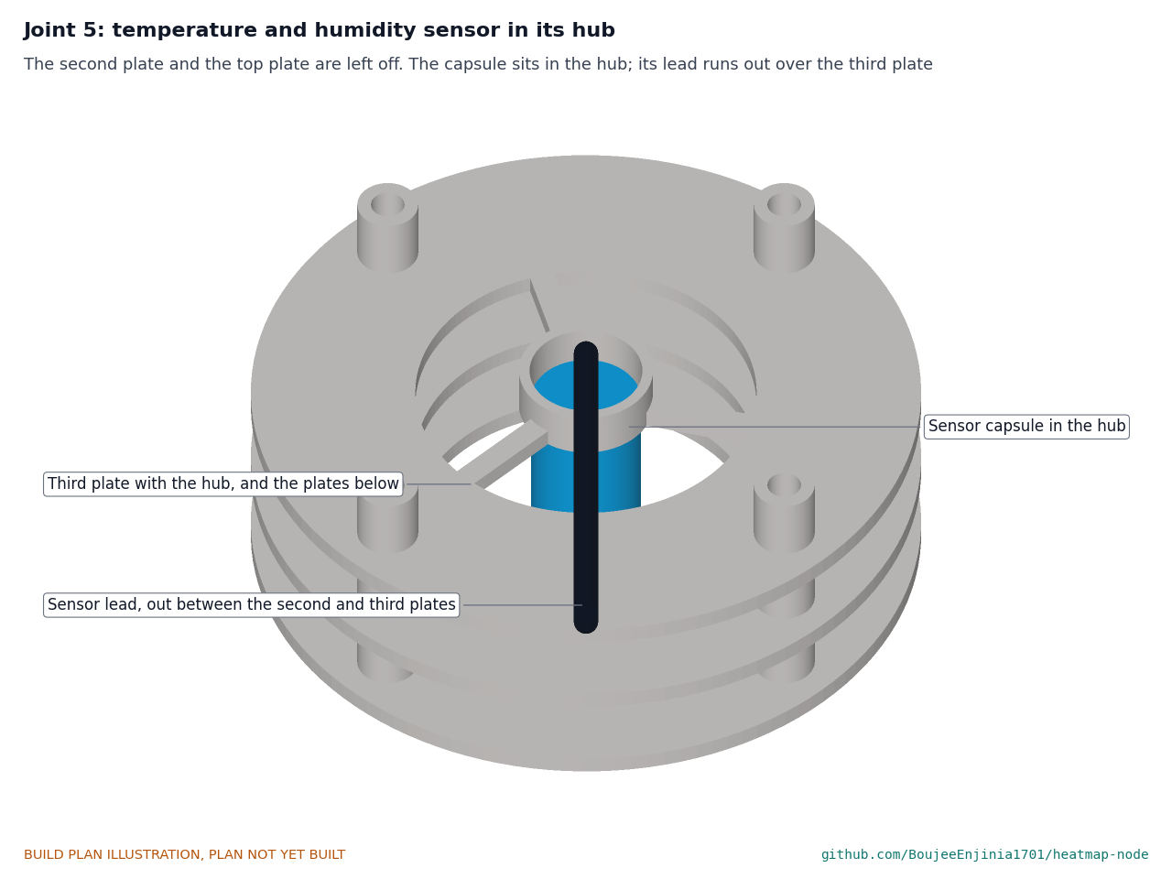
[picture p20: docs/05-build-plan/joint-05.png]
Figure 11. Joint 5: the sensor in its hub


*Figure 11. The sensor sits in the hub of the third plate at the centre of the stack; its lead leaves between the second and third plates.*

From the bottom, the order is six plain ring plates, then the hub plate, then one plain ring plate, then the top plate: the hub plate is the third from the top. Four M5 stainless threaded rods pass through all eight plates. The two rods in line with the arm are 192 long; the other two are 121 long.

**Check before moving on.** The eight plates stack 108 tall on the rods with even 12 mm gaps, and the sensor capsule slides into the hub and is held by the set screw.

### 3.5 Fan cowl

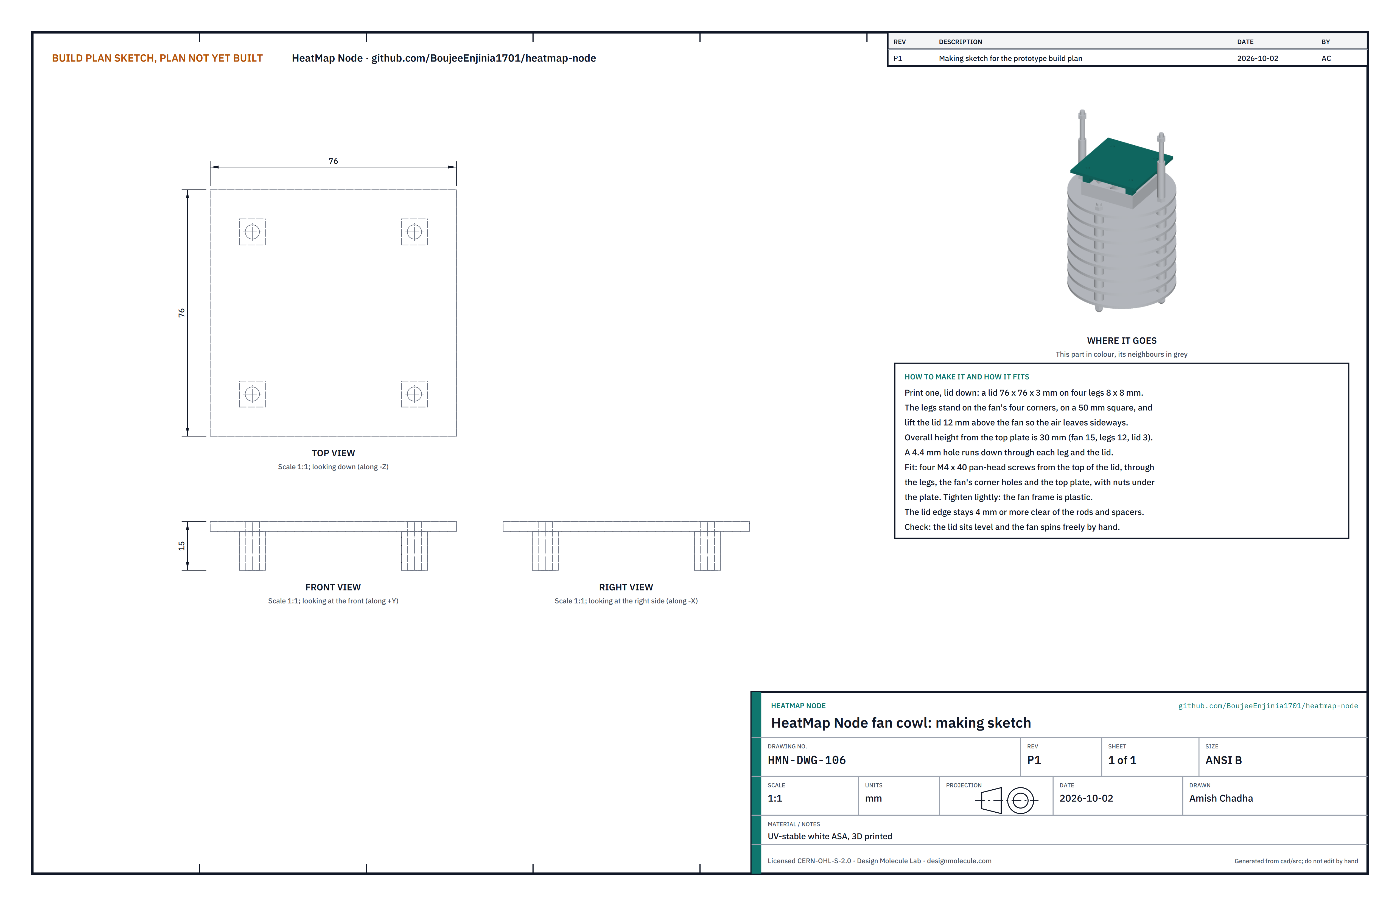
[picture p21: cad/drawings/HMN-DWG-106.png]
Figure 12. Making sketch of the fan cowl


*Figure 12. Fan cowl making sketch (HMN-DWG-106).*

**What it is and what it is made from.** A lid that keeps rain off the fan and turns its air out sideways. UV-stable white ASA, printed lid down.

**How to make it.**

1. Print a lid 76 x 76 x 3 on four legs 8 x 8 and 12 tall, the legs on a 50 square.
2. Drill a 4.4 hole down through each leg and the lid if the print has closed it.

**How it fits the parts next to it.**

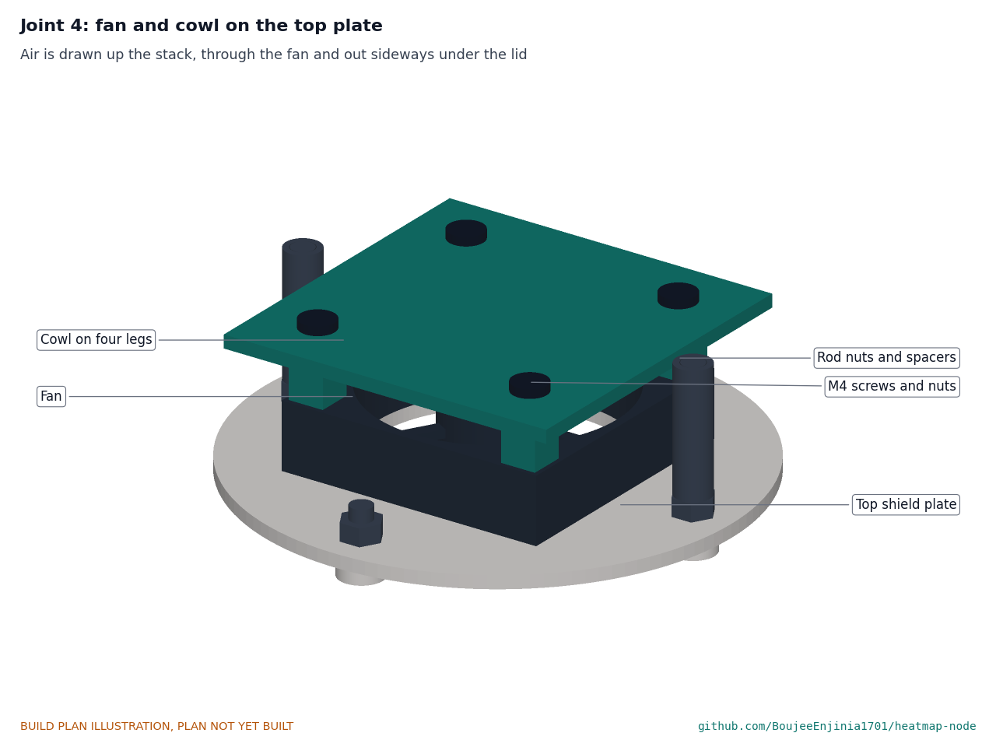
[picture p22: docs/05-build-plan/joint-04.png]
Figure 13. Joint 4: fan and cowl on the top plate


*Figure 13. The fan sits flat on the top plate; the cowl's legs stand on the fan's corners; four M4 screws hold all three.*

The fan sits flat on the top plate over its centre hole, blowing upward. The cowl's legs stand on the fan's four corners, lifting the lid 12 above the fan. Four M4 x 40 pan-head screws go down through the lid, the legs, the fan's corner holes and the top plate, with nuts under the plate. The lid edge is at least 4 from every rod and spacer.

**Check before moving on.** The lid sits level and the fan turns freely by hand.

### 3.6 Pole adapter V-blocks (make 2)

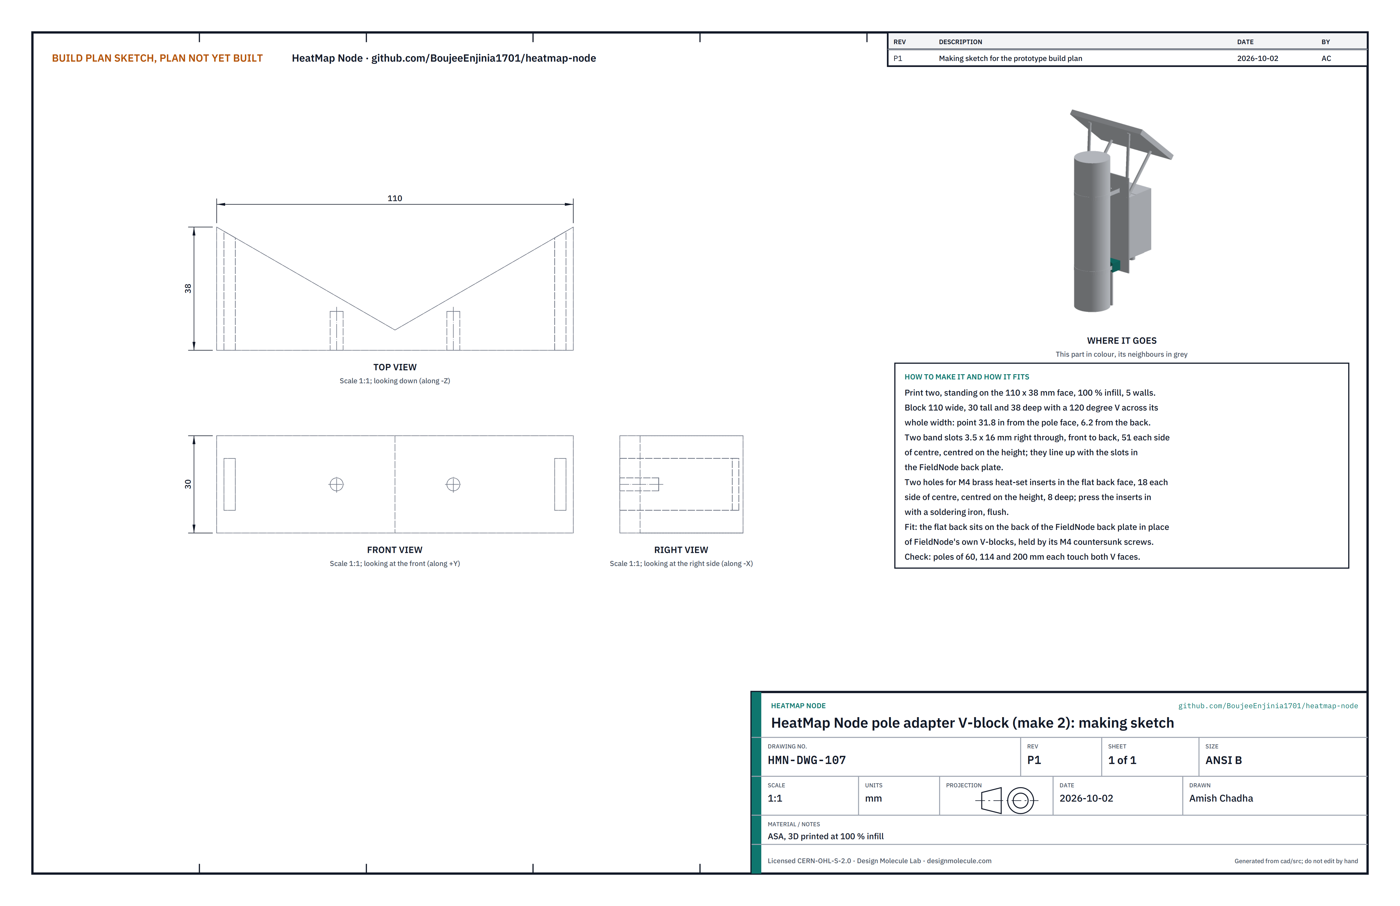
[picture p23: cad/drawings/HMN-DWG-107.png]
Figure 14. Making sketch of the adapter V-block


*Figure 14. Adapter V-block making sketch (HMN-DWG-107).*

**What it is and what it is made from.** Two blocks that seat the FieldNode core on a street pole of 60 to 200 mm, in place of FieldNode's own V-blocks, which fit only small poles. ASA, printed at 100 % infill with 5 walls.

**How to make it.**

1. Print each block standing on its 110 x 38 face: 110 wide, 30 tall, 38 deep, with a 120° V across the whole width, its point 31.8 in from the pole face and 6.2 from the flat back.
2. The print includes two band slots 3.5 wide and 16 tall that run right through from the V to the back, 51 each side of centre and centred on the height.
3. In the flat back, 18 each side of centre and centred on the height, make holes for M4 brass heat-set inserts, 8 deep, sized for the inserts you have. Press the inserts in with a soldering iron until flush.

**How it fits the parts next to it.**

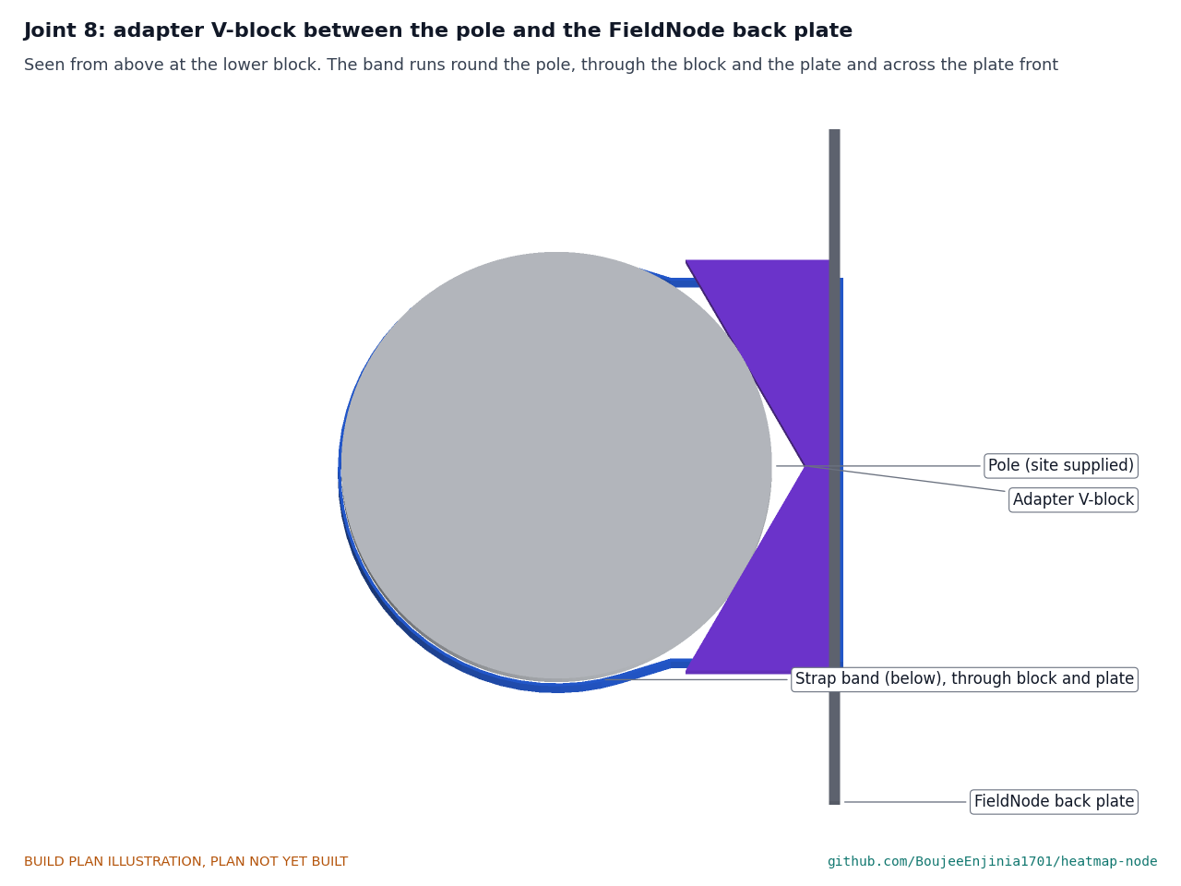
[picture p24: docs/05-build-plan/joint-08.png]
Figure 15. Joint 8: adapter V-block between the pole and the FieldNode back plate


*Figure 15. The block's flat back sits on the back of the FieldNode back plate; each band passes round the pole, through the block and the plate, and across the plate's front.*

The flat back sits flat on the back face of the FieldNode back plate, where FieldNode's own V-blocks would go, 20 and 270 up from the plate's bottom edge. FieldNode's two M4 countersunk screws per block go in from the front of its plate into the inserts. The block's band slots line up with the plate's band slots. A 114 mm pole touches both faces of the V about 15 in from the pole face.

**Check before moving on.** Each block seats on a 114 mm tube without rocking, and a strip of band passes straight through block and plate slots together.

### 3.7 Bought components

Buy to specification, not brand. Line numbers are those of the bill of materials.

- **FieldNode core (line 1).** Build it to the FieldNode build plan FND-BLD-001, hot-climate version with its sun shield, but leave out its two V-blocks and its band clamps: the adapter V-blocks (section 3.6) and the 13 mm strap bands take their place.
- **Temperature and humidity sensor (line 3).** SHT45-class digital sensor in an 18 mm capsule at least 45 long with a membrane cap, on a lead long enough to reach the arm (about 0.4 m), with its plug on the free end.
- **Black globe (line 4).** A 150 mm thin-wall copper float ball with a top boss threaded M10 x 1 (or an adapter to M10 x 1). Clean it, key the surface with fine abrasive and spray it matte black outside, two coats. Its hanger is an 86 mm length of M10 x 1 hollow brass lamp rod (7 mm bore) with three M10 x 1 nuts.

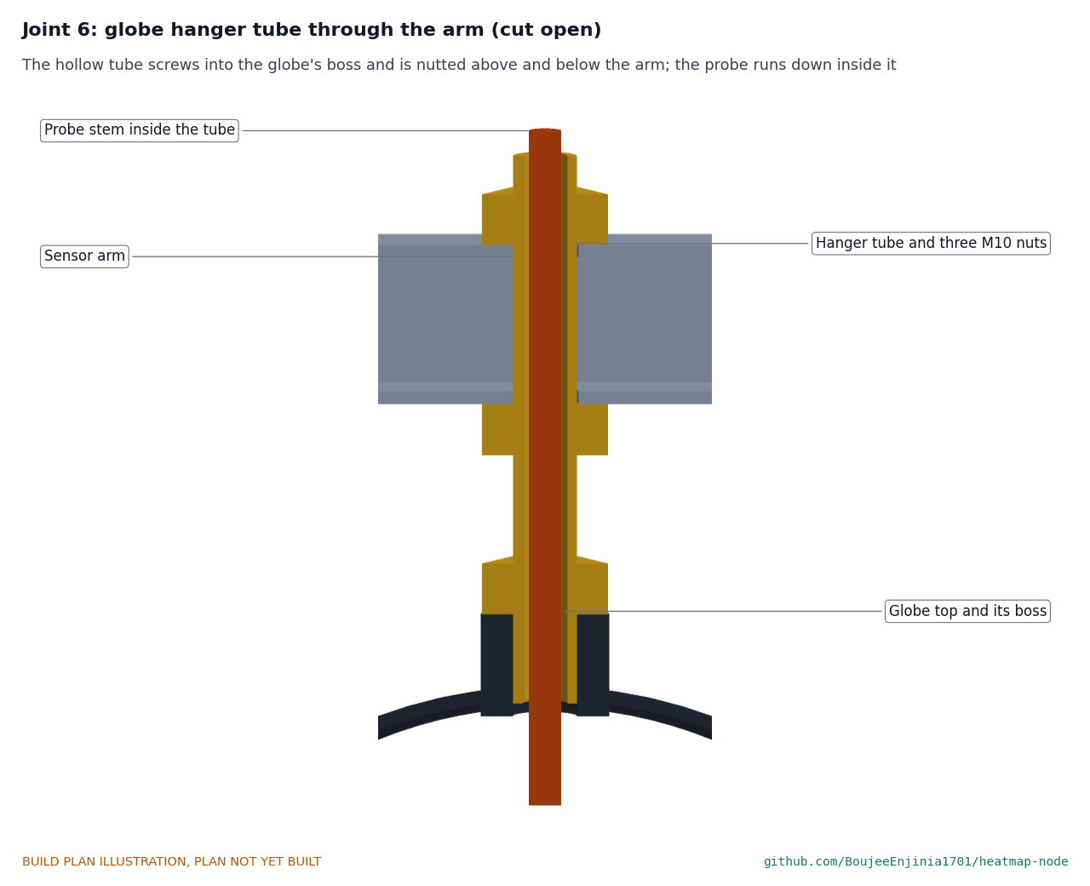
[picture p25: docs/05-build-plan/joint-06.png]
Figure 16. Joint 6: the globe hanger tube through the arm


*Figure 16. The hollow tube screws into the globe's boss and is locked with a nut; a nut below and a nut above the arm hold it. The probe runs down inside the tube to the globe's centre.*

- **Globe probe (line 5).** A 10 k thermistor bead on a stiff 5 mm stem about 165 long, so the bead sits at the globe's centre with the stem's top 4 above the tube. Calibrate it before fitting, as the calibration plan says.
- **Cup anemometer (line 6).** Three-cup, pulse output, on a 16 mm tube mast with its cable leaving at the foot. Cut the mast so it stands 170 above the arm and 15 below it, and drill a 5.5 hole across it 27.5 above its foot for the pin.

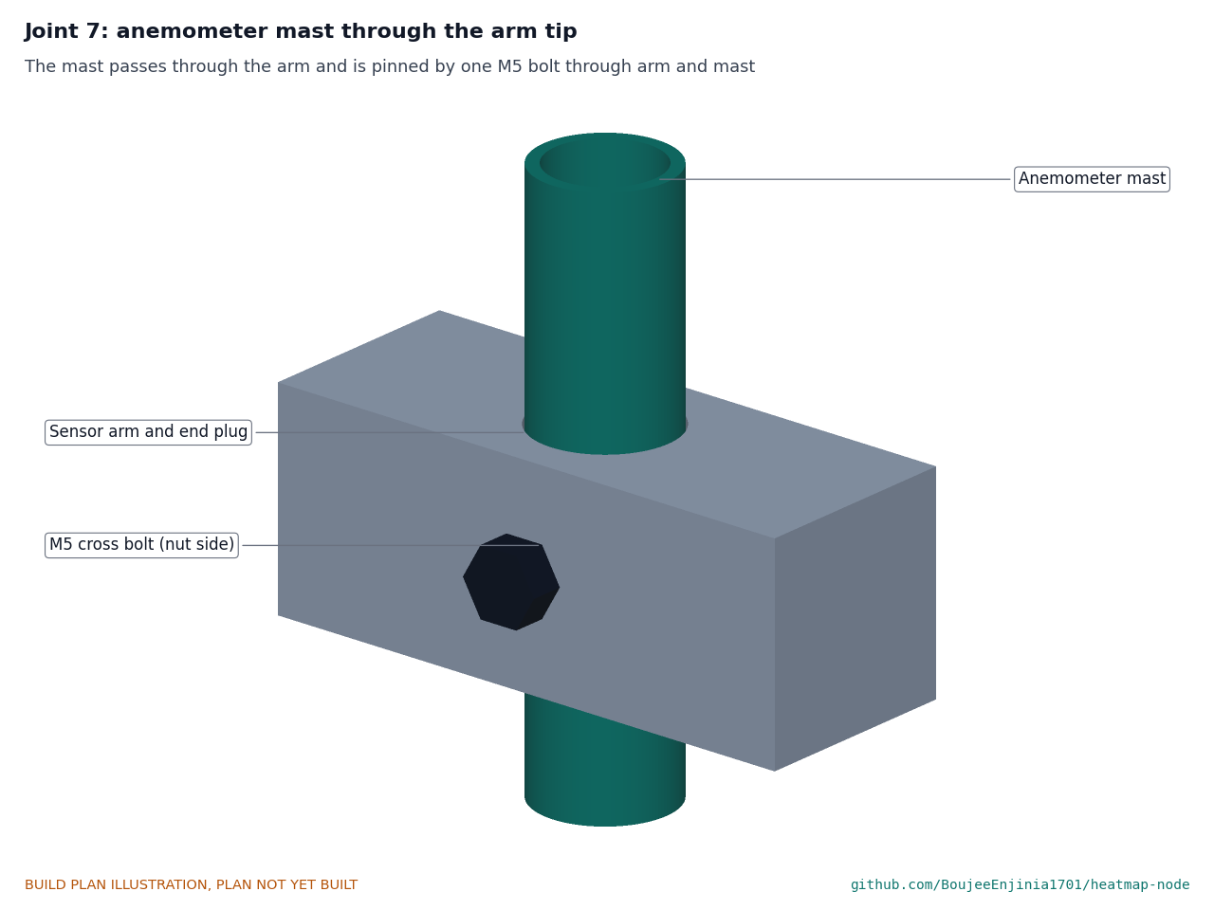
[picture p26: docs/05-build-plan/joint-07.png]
Figure 17. Joint 7: anemometer mast through the arm tip


*Figure 17. The mast passes down through the arm and one M5 bolt pins arm and mast together.*

- **Shield rods and spacers (line 2).** M5 316 stainless threaded rod cut to two lengths of 192 and two of 121; two spacers 41 long cut from 8 mm aluminium tube with a 5.3 bore; four M5 acorn nuts and six M5 nuts.
- **Fan (line 13).** 60 x 60 x 15, 5 V, ball bearing, corner holes on a 50 square for M4.
- **Rubber edge trim and strap bands (lines 8 and 12).** Edge trim for 3 mm sheet with about 1.5 of rubber on the edge. Four 13 mm 316 stainless strap bands with buckles, two for the saddle and two for the adapter, cut to length for the pole on site (about 0.5 m each on a 114 mm pole).
- **Sensor harness (line 9).** Two outdoor cables, lead A about 1.2 m and lead B about 1.4 m long, with M12 5-pin A-coded plugs at the core end. At the sensor end, lead A ends in a plug for the temperature and humidity sensor and a two-wire tail for the fan; lead B ends in a tail for the probe and a tail for the anemometer, each with a sealed heat-shrink breakout.
- **Lanyards (line 11).** Two 1.5 mm 316 stainless wire lanyards with ferrules and snap hooks, about 150 long.
- **Fixings (line 10).** Stainless: 2 x M6 x 40 hex bolts and 4 x M6 x 16 button-head screws with nyloc nuts; 1 x M5 x 35 bolt with a nyloc nut; 4 x M4 x 40 pan-head screws with nuts; 1 nylon M3 set screw; 25 mm square tube end plug; about 12 UV-stable cable ties 400 long and a bag of short ones; sealant.

## 4. Putting it together

Steps 1 to 12 are done on the bench. Step 13 is done on the bench with the FieldNode core, and steps 14 to 16 at height on the pole. In each picture the parts already fitted are grey and the part being fitted is in colour, with an arrow showing the way it goes in.

### Step 1: rubber trim onto the saddle

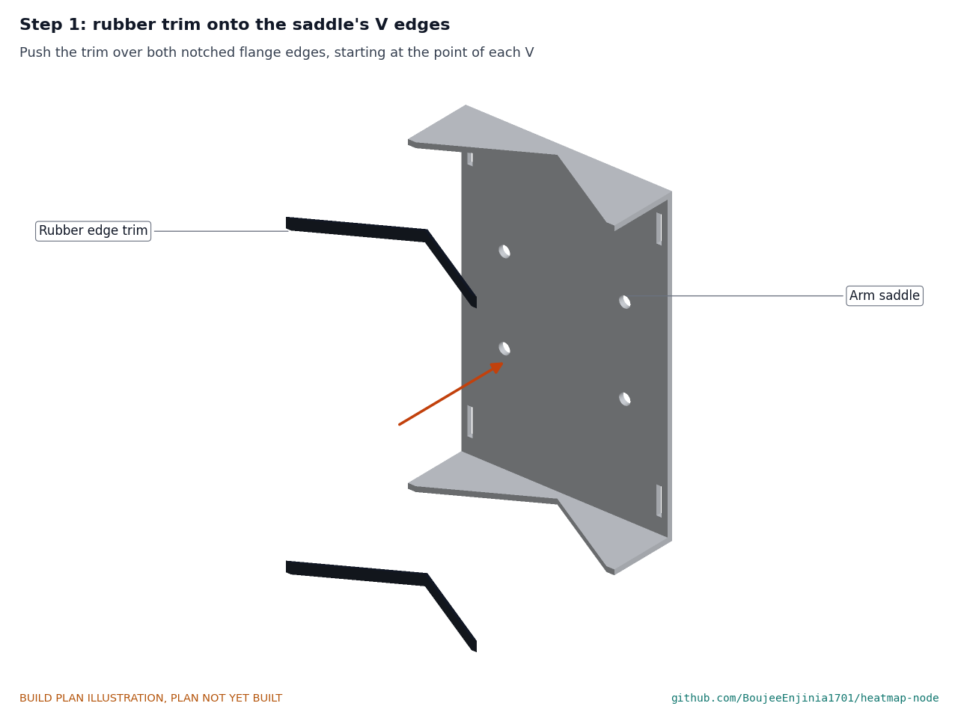
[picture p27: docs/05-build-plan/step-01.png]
Step 1


Push the trim over both V edges, starting at the point of each V and working out to the corners. Trim it flush with the corners.

### Step 2: cheeks onto the saddle

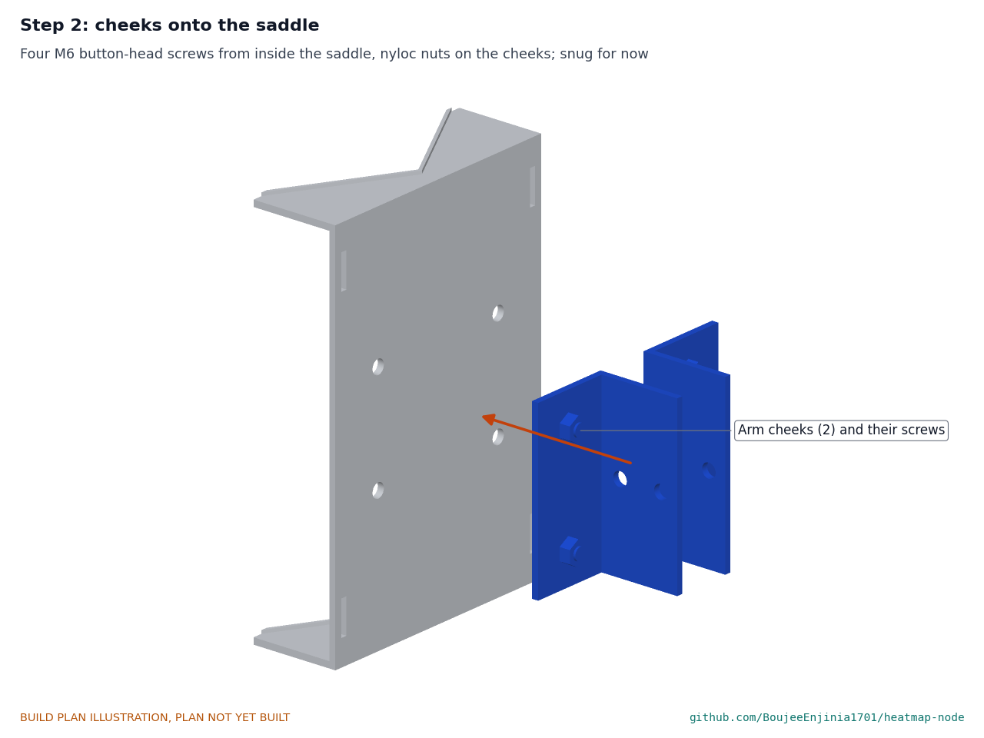
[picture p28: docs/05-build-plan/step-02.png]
Step 2


Four M6 x 16 button-head screws from inside the saddle, nyloc nuts on the cheeks, snug only so the cheeks can still move a little.

### Step 3: arm between the cheeks

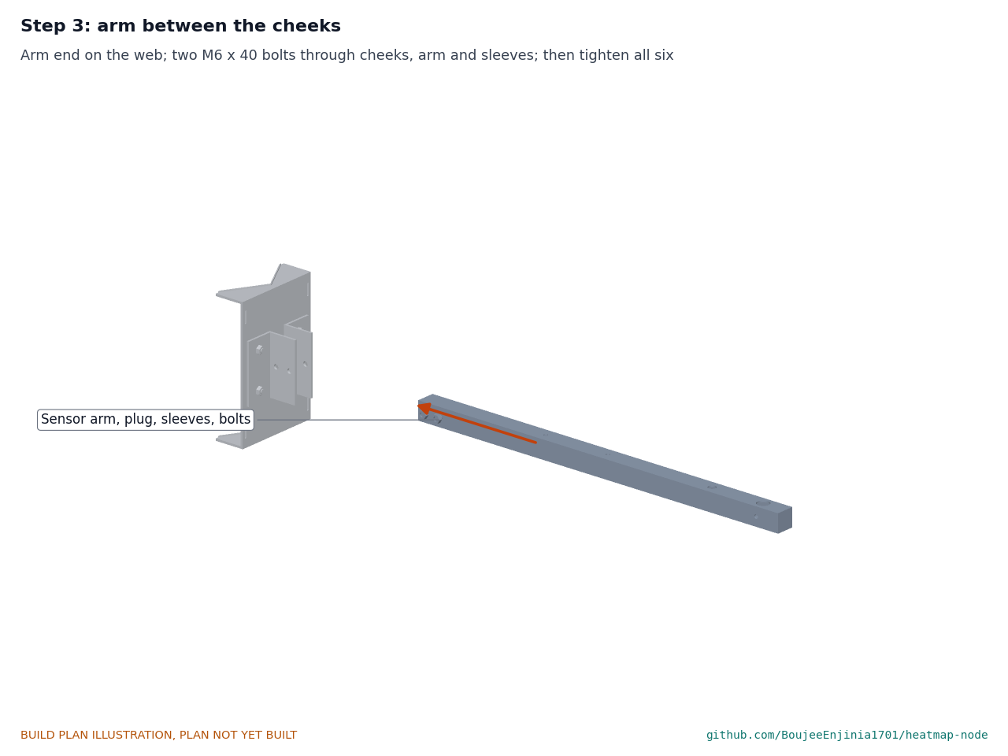
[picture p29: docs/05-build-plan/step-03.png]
Step 3


Slide the arm's root between the cheeks until it bears on the web, with the crush sleeves lined up. Two M6 x 40 bolts, heads on the right, nyloc nuts on the left. Tighten these two bolts, then the four cheek screws. Check the arm is square to the web.

### Step 4: start the shield stack

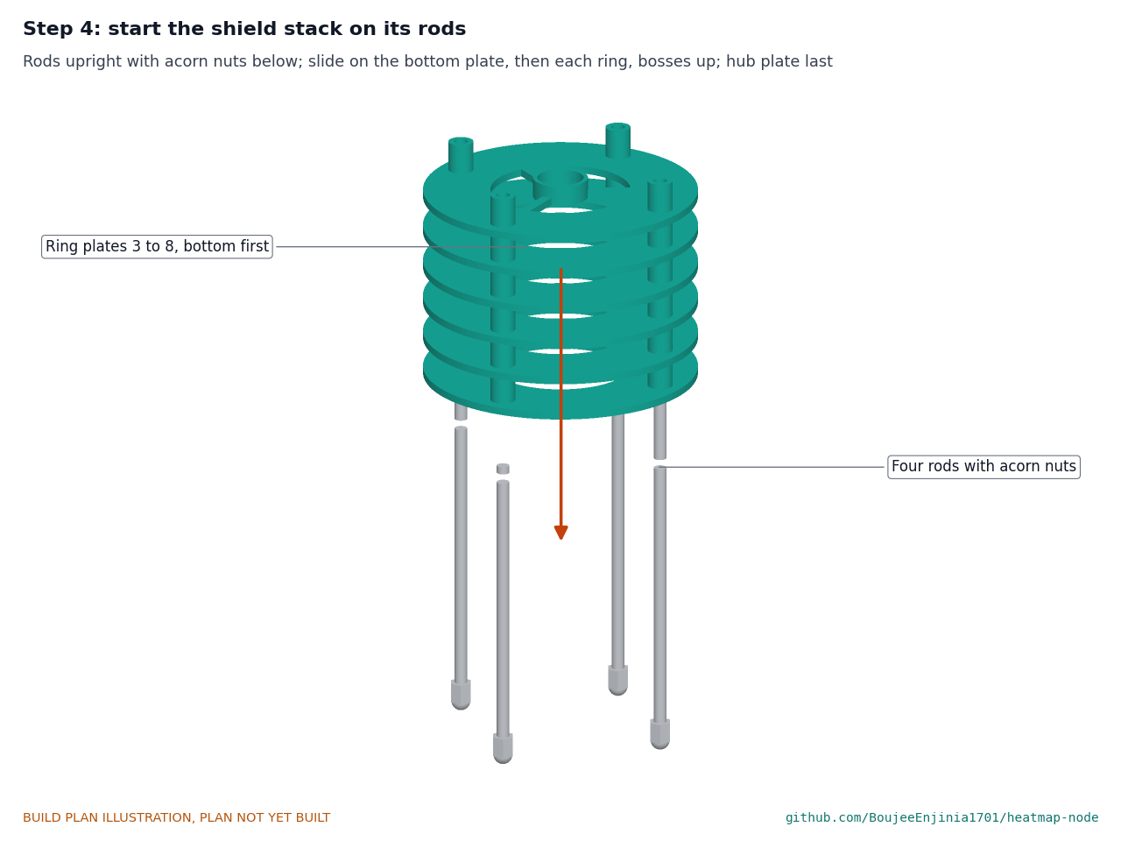
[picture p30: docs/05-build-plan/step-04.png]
Step 4


Stand the four rods upright, acorn nuts at the bottom, the two long rods opposite each other. Slide on the six plain ring plates one at a time, bosses up, then the hub plate.

### Step 5: sensor into the hub

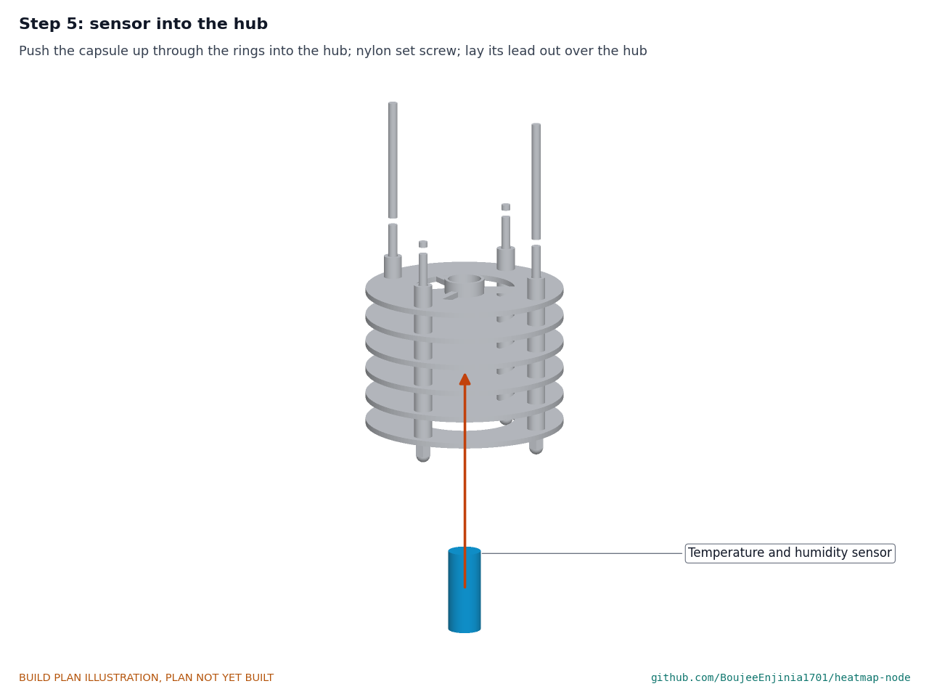
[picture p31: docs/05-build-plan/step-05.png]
Step 5


Push the capsule up through the rings into the hub until its top is level with the top of the hub, and nip the nylon set screw. Lay its lead out over the hub between two rods, at 45° to them, on the side the leads will run.

### Step 6: close the stack

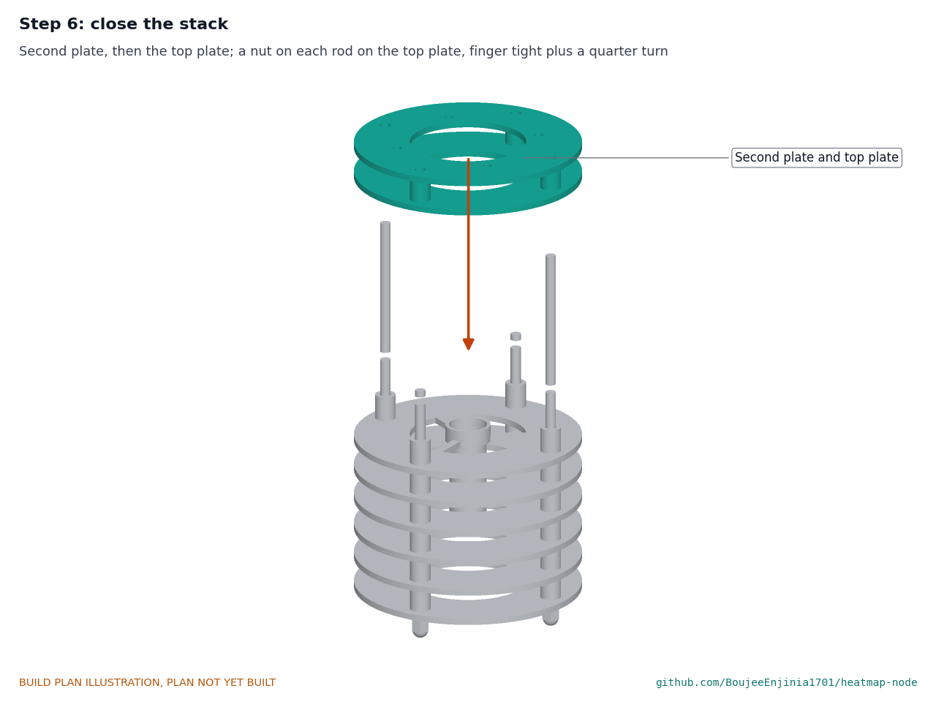
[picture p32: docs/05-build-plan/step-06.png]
Step 6


Fit the last ring plate over the lead, then the top plate. Put a nut on each rod on the top plate and tighten finger tight plus a quarter turn: the plastic must not crack.

### Step 7: fan and cowl

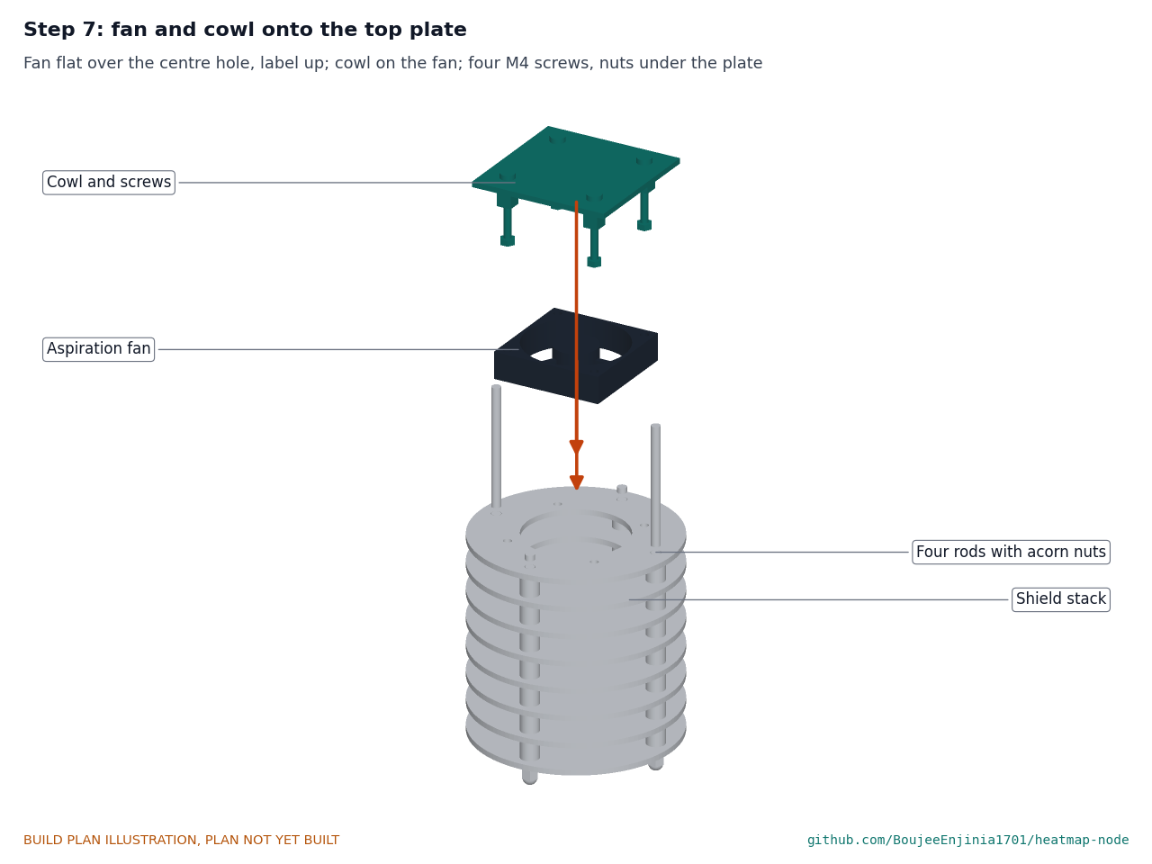
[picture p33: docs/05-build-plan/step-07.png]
Step 7


Fan flat on the top plate over its hole, label up so it blows upward, its leads toward the sensor lead. Cowl on the fan, legs on the corners. Four M4 x 40 screws through lid, legs, fan and plate, nuts under the plate (reach in through the gap below it), snug.

### Step 8: hang the shield on the arm

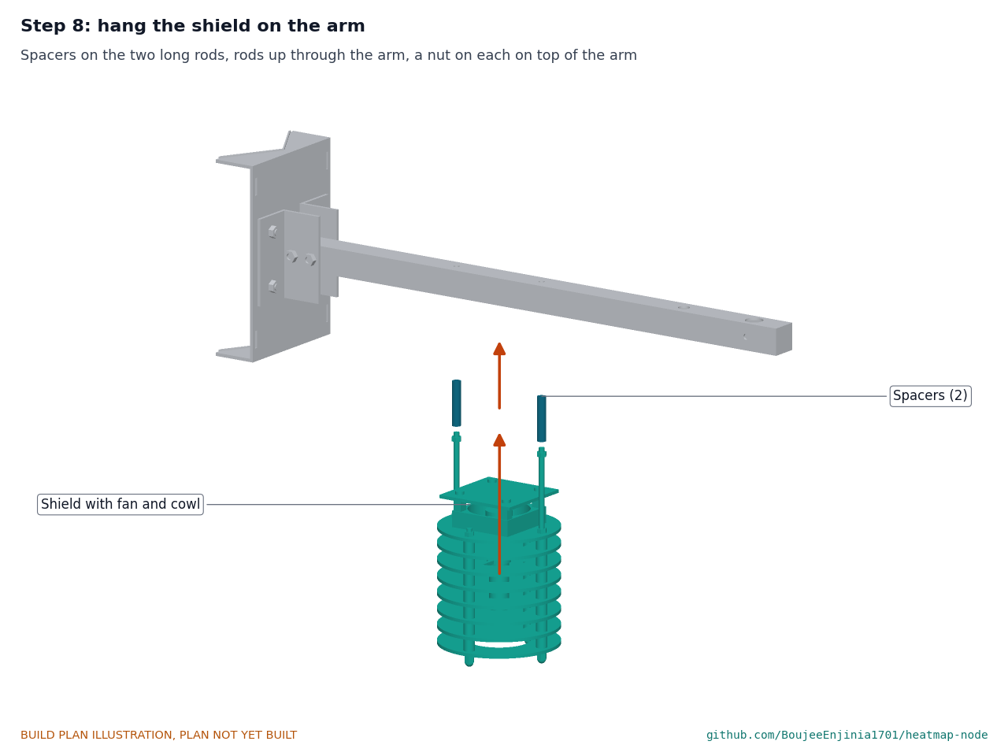
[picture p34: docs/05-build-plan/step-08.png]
Step 8


Drop a spacer over each long rod. Lift the shield until the long rods pass up through the arm, the spacers bearing on the arm's underside. Fit a nut on each rod on top of the arm and tighten until the stack no longer moves. **Hold point:** the stack hangs square under the arm with no gap at either spacer.

### Step 9: hang the globe

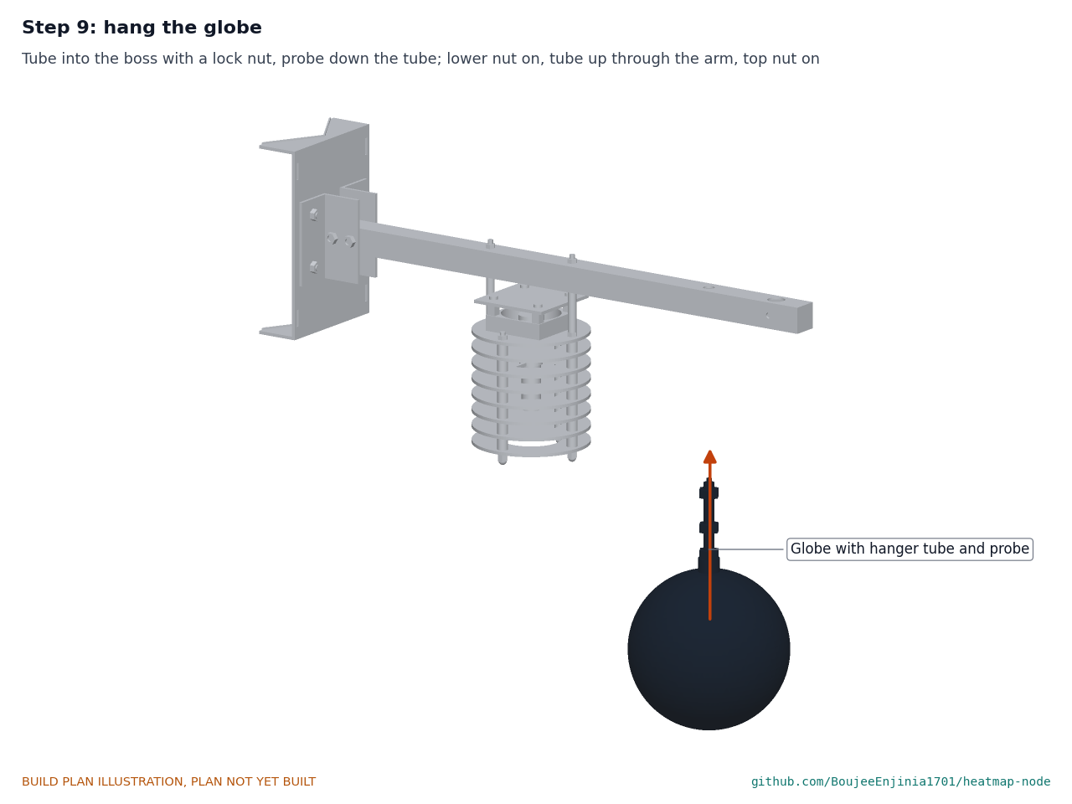
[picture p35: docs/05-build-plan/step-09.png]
Step 9


Screw the hanger tube 14 into the globe's boss with a nut, lock the nut. Feed the probe down the tube until its bead sits at the centre (its stem top 4 above the tube top) and seal the tube's top round the stem. Run the lower nut onto the tube, push the tube up through the arm and fit the top nut; set the globe 45 below the arm and tighten both nuts against the arm.

### Step 10: anemometer onto the arm tip

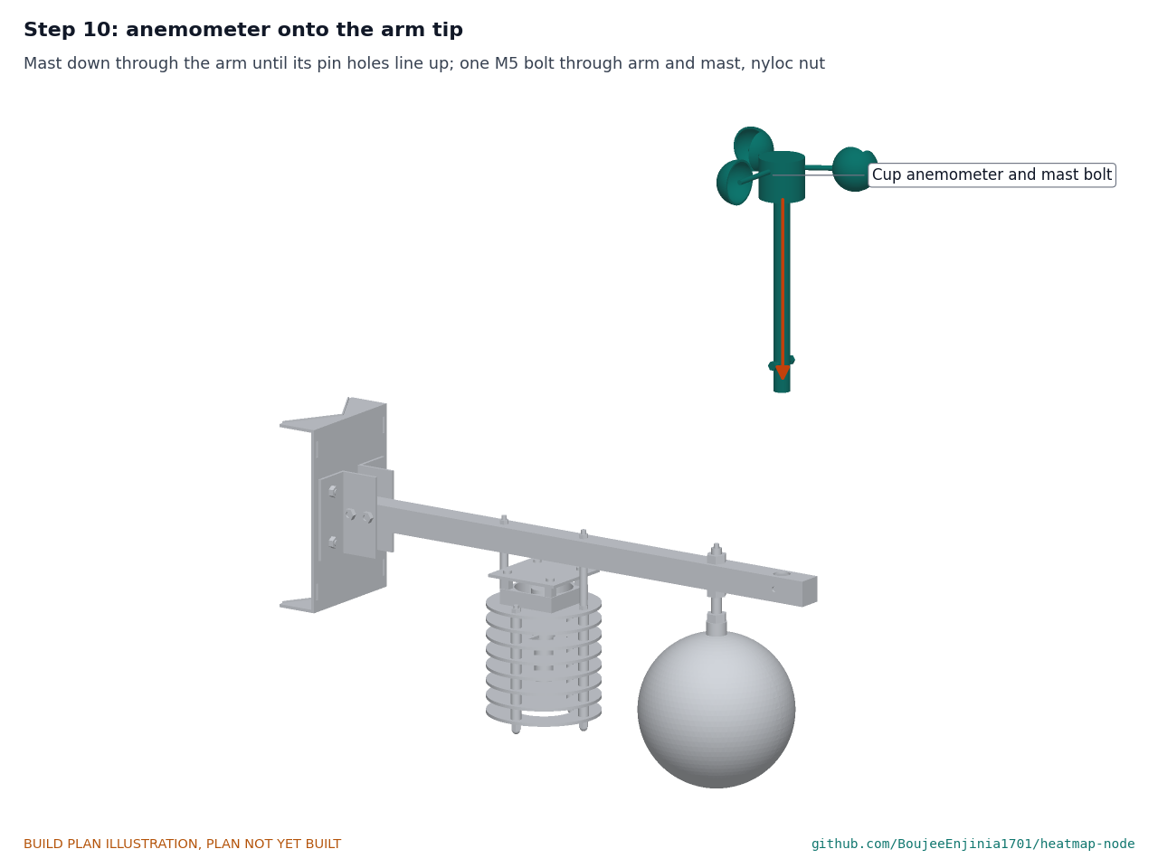
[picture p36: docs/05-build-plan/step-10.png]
Step 10


Feed the mast down through the arm until its pin hole lines up with the arm's side holes, with the cups' cable at the foot. One M5 x 35 bolt through arm and mast, nyloc nut.

### Step 11: retention lanyards

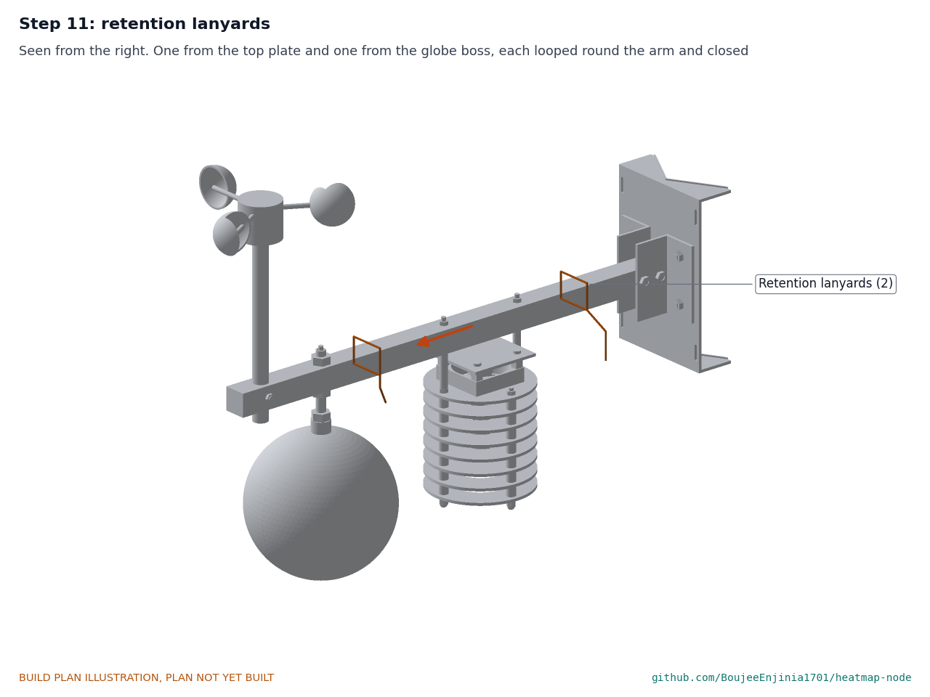
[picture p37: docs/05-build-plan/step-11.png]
Step 11


Fit one lanyard through a 2 mm hole drilled in the top plate between two rods, on the right-hand side, and loop it round the arm; fit the other round the globe's boss under the lock nut and loop it round the arm. Close both snap hooks. Each loop must be snug but must not carry load.

### Step 12: sensor leads along the arm

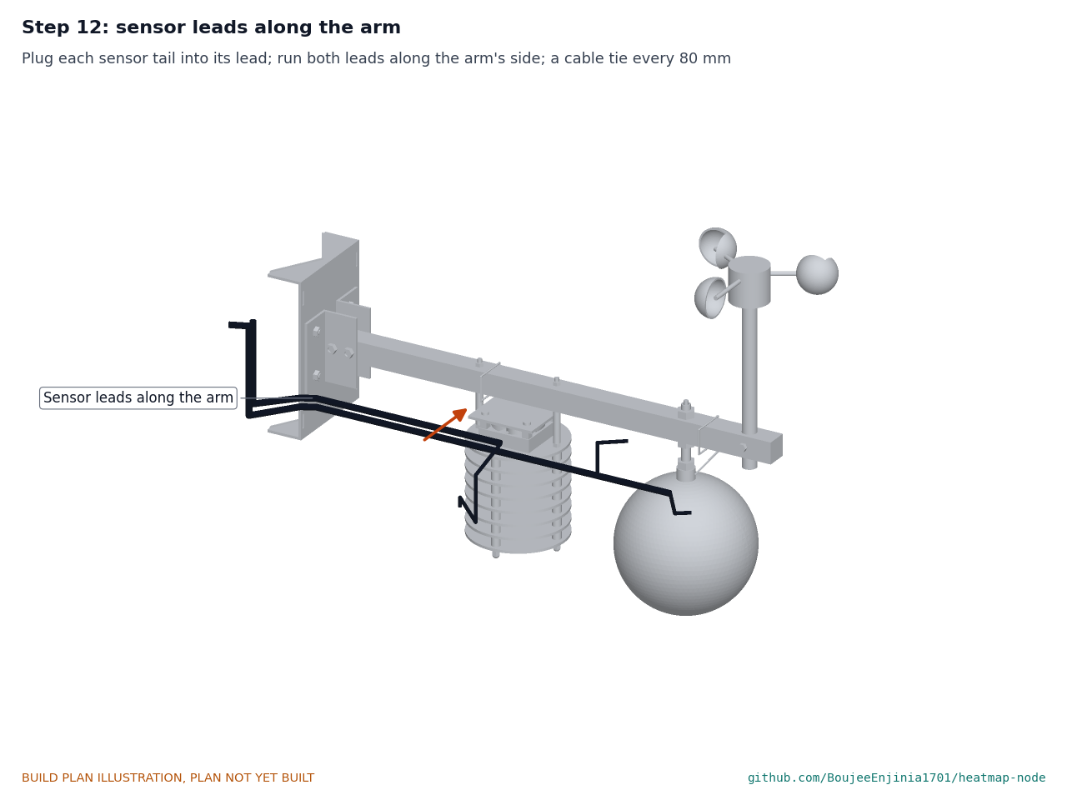
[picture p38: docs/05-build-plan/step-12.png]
Step 12


Plug the sensor's plug into lead A and join the fan's two wires to its tail; join the probe and the anemometer to lead B's tails. The pins follow FieldNode's candidate pinout (HMN-DEC-001): on port A, the sensor's I2C lines on data pins 2 and 4, with sensor and fan on the switched rail; on port B, the thermistor on analog pin 5 and the anemometer pulse on pin 2. Run both leads along the left side of the arm with a short cable tie every 80, and leave the rest of each lead coiled at the root. **Hold point:** the leads pass outside the cheek bolt heads and nothing touches the cups.

### Step 13: adapter V-blocks onto the FieldNode core

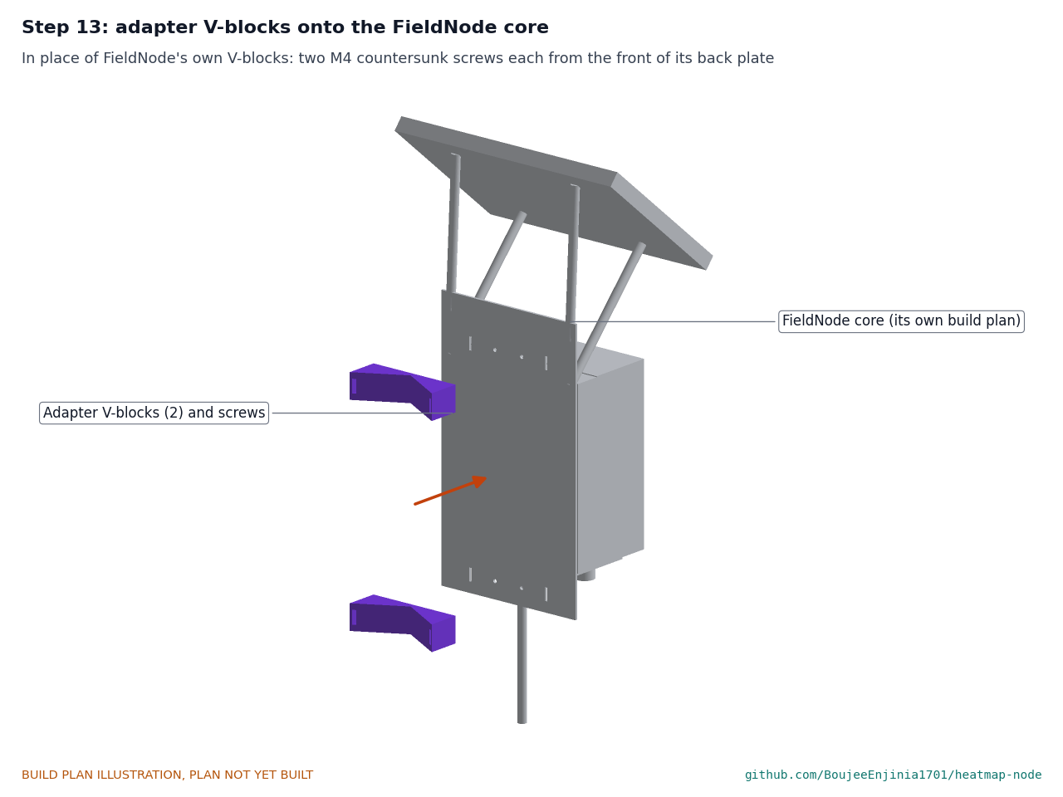
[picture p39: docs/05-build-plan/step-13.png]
Step 13


On the FieldNode core built to its own plan without its V-blocks: two M4 countersunk screws per block from the front of its back plate into the inserts, snug.

### Step 14: sensor head onto the pole

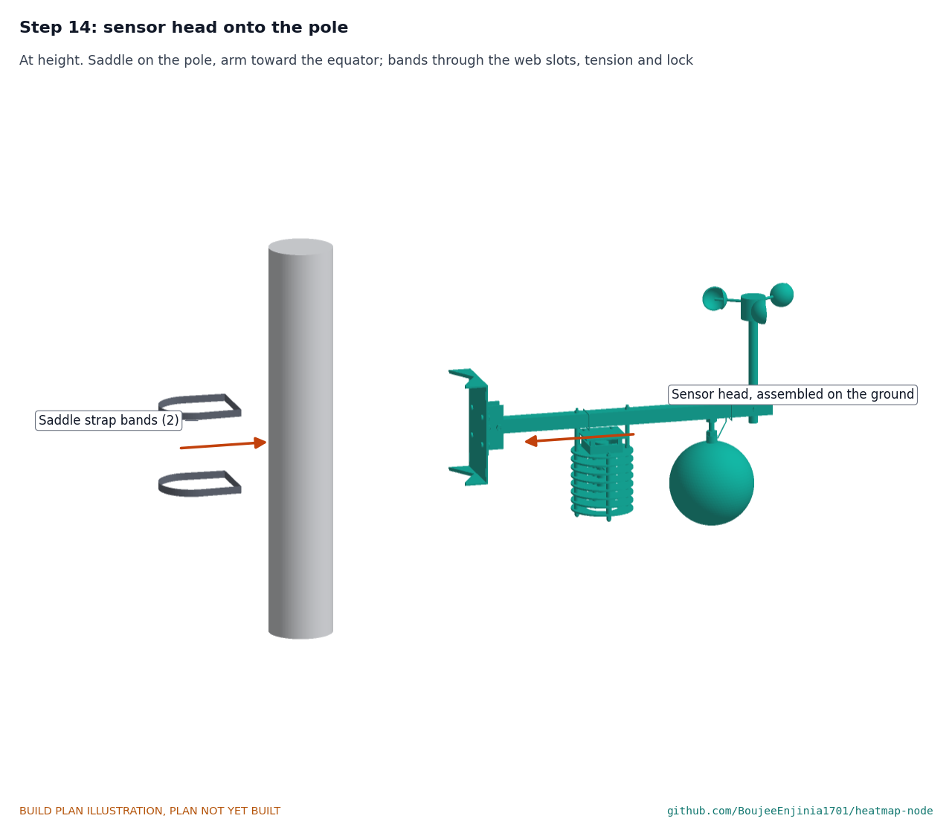
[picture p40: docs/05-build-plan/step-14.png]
Step 14


The sensor head, assembled on the bench, goes on first, with the arm axis at 2.8 m and the arm toward the equator. Hold the saddle on the pole, pass each band round the pole, through its two web slots and across the web front, and tension each band with the band tool to its maker's setting for about 1,000 N and lock the buckle. Check the arm is level. **Hold point:** safety stop S3.

### Step 15: FieldNode core onto the pole above the arm

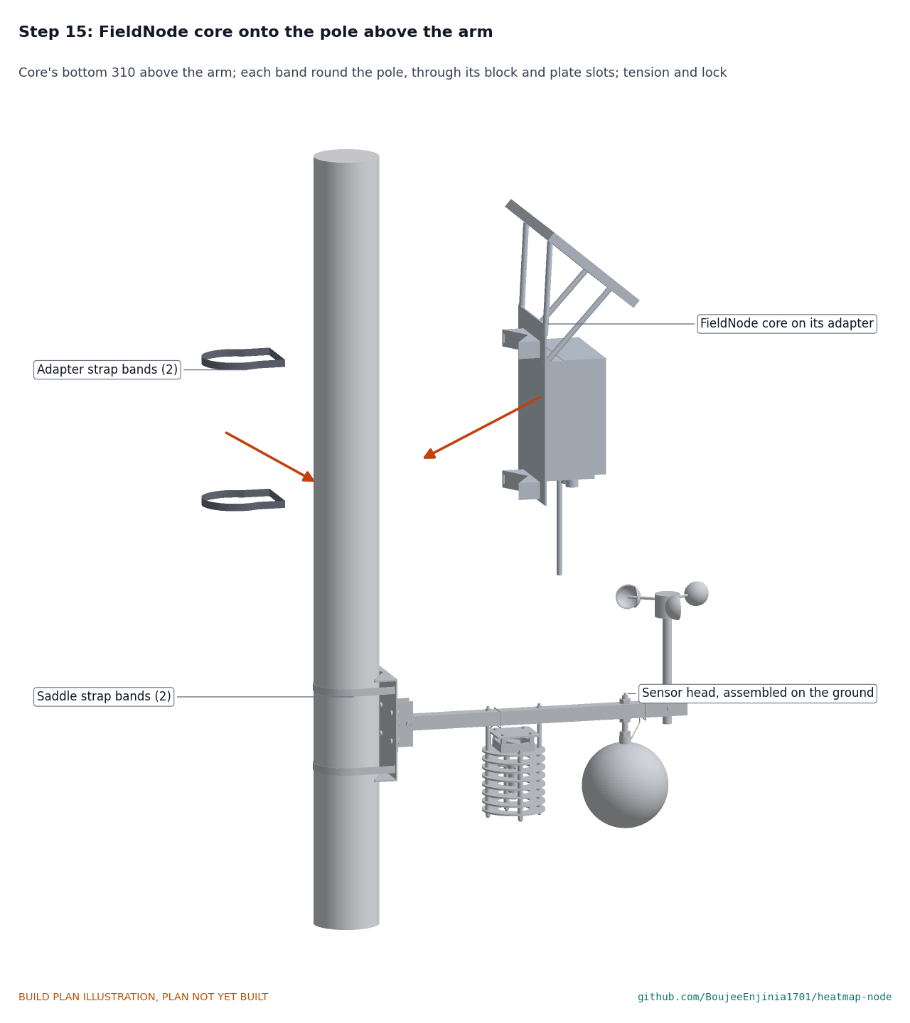
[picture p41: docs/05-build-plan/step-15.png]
Step 15


Lift the core, with its V-blocks on, to the pole on the same side as the arm, panel facing the equator, so that its bottom is about 310 above the top of the arm and its antenna whip clears the arm by 100 or more. Pass each band round the pole, through its block and plate slots and across the plate front, below and above the box, and tension and lock it as in step 14. **Check:** from the ladder or lift position that fitted the arm, the core's lid opens fully and its screws can be reached. If it cannot be reached, fit the core instead on the pole's east or west face at the same height, panel still toward the equator.

### Step 16: leads up the pole to the ports

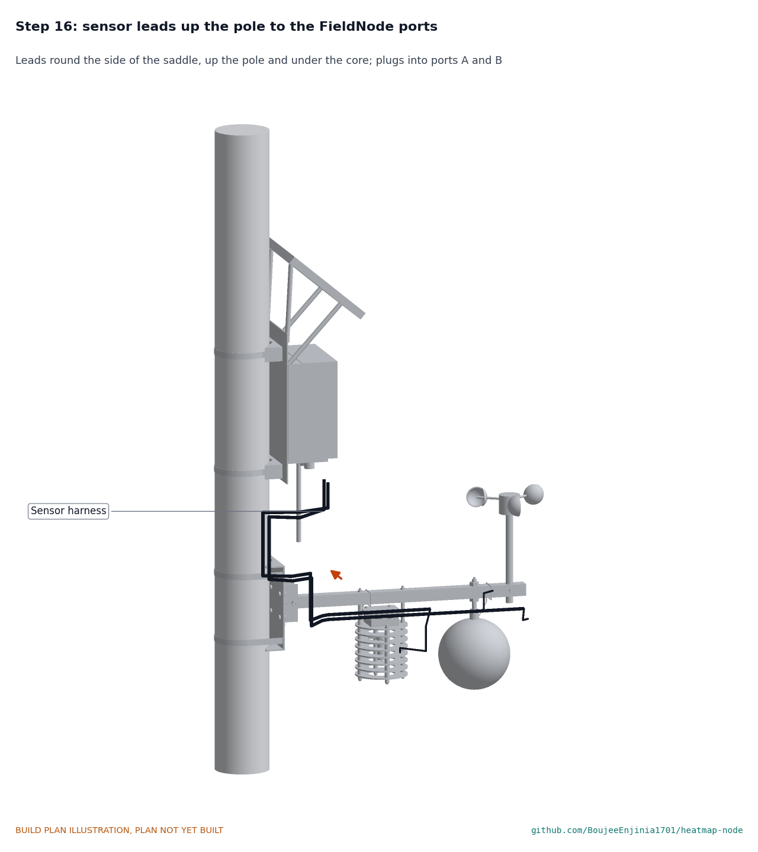
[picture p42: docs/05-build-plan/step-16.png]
Step 16


Plug lead A into port A and lead B into port B under the core, leaving a drip loop below each plug. Run both leads down the pole on its left side, outside the core's bands, with a long cable tie every 300, then over the top of the saddle's upper flange, down the left side of the saddle and out along the arm. **Hold point:** safety stop S4.

## 5. First checks

These are the checks a TRL 4 test report would record; this plan only lists them. Requirement numbers are those of HMN-REQ-001.

*Table 2. First checks.*

| Check | Requirement | How | Pass when |
| --- | --- | --- | --- |
| Pole fit | R10 | Fit the saddle and one V-block on 60, 114 and 200 mm tubes on the bench | Both V faces (or both trimmed edges) touch each tube; each band closes with adjustment to spare |
| Clamp hold | R11 | Hang 2 kg on the arm tip and push sideways at the tip by hand with the head on a 114 mm tube | No slip or turn at the bands; no movement at any bolt |
| Fan | R1 | Power the fan from a 5 V bench supply for 6 s; hold a tissue strip under the bottom plate and beside the cowl | Air is drawn in at the bottom and leaves under the lid; no rubbing noise |
| Sensor readings | R1, R2, R3 | With the core running, read air temperature, humidity and globe temperature indoors | All three read within 1 °C (or 5 %RH) of a reference thermometer and hygrometer in still air |
| Wind pulse | R4 | Spin the cups by hand | Pulses counted; the calm share reads zero while spinning |
| Arm deflection | R11 | Dial gauge at the tip; 10 N sideways at the anemometer | Under 1 mm (0.31 mm expected at a 20 m/s gust) |
| Mass | R15 | Weigh the sensor head before it goes on the pole | 4 kg or less (2.08 kg estimated) |
| Fitting time | R10 | Time steps 14 to 16 with two people from one lift | 30 minutes or less (37 minutes estimated) |
| Privacy | R12 | Look over the parts list and the board | No camera, microphone or radio scanning part |

## 6. Safety stops

Stop at each point. Carry on only when everything listed is true.

- **S1. Before the first cut.** Safety glasses on; the tube, angle and sheet clamped before drilling; no gloves near a turning drill.
- **S2. Before any work on the FieldNode core.** Its own safety stops (FND-BLD-001, section 6) are passed; its fuse stays out until its plan allows it.
- **S3. Before going up the pole.** Written permission from the pole owner; the pole checked for its rating against about 420 N·m of added wind moment at its base; a lift or a stable ladder with a second person; fall protection; traffic management as local rules require; no overhead line within reach and no live parts open on a lighting pole. Tools and small parts tethered or in a bag.
- **S4. Before the leads are plugged in.** Every nut on the rods, hanger tube and mast is tight; both lanyards are closed round the arm; the cups spin freely; hands clear of the fan, which starts by itself every 3 minutes once the core is powered.
- **S5. Whenever the head is worked on later.** Unplug lead A before touching the shield (the fan); let the globe cool or wear gloves in sun; stop the cups by hand before working near them.

## 7. Tools, skills and workspace

**Tools.** Hacksaw with a 24 teeth per inch blade; bench vice with soft jaws; drill press; drills 2.5 to 10.5 mm and a step drill to 20 mm; flat and half-round files; deburring tool; scriber, engineer's square, steel rule and calipers; 3D printer with an enclosure that prints ASA, bed at least 120 x 120 mm; soldering iron with an insert tip; spanners 8, 10 and 17 mm; 3 and 4 mm hex keys; screwdrivers; strap band tool for 13 mm bands; dial gauge; spring balance to 20 N; scale to 5 kg; multimeter; 5 V bench supply. The sheet bending is a job for a local sheet-metal shop with a press brake if you have no folder for 3 mm aluminium.

**Skills.** No certified trade is needed for the bench work: basic metalwork (marking out, sawing, drilling, filing), 3D printing in ASA, and plugging and splicing low-voltage leads. All circuits are extra-low voltage (5 V at most at the sensors). Work at height on a street pole needs whatever training and permits the pole owner and local rules require.

**Workspace.** A bench about 1.2 x 0.6 m; a metalwork corner kept apart from the electronics so chips stay off them; a ventilated place for the printer.

**Personal protective equipment.** Safety glasses for cutting and drilling; cut-resistant gloves for sheet and cut tube; hearing protection when sawing; a hard hat, high-visibility clothing and fall protection at the pole.

## 8. Where the numbers come from

- Model and constructability checks: `cad/src/model.py` (`python cad/src/model.py --check`, 399 checks); STEP and STL exports in `cad/step/` and `cad/stl/`.
- Pictures: `cad/src/build_plan_media.py`, using `.kit/build_views.py`; written to `docs/05-build-plan/` and `cad/drawings/HMN-DWG-101` to `HMN-DWG-107`.
- General arrangement: `cad/drawings/HMN-DWG-001.pdf`, Rev P4.
- Calculations: `docs/04-calcs/01-sizing.md` (HMN-CAL-001 v0.4) and `docs/04-calcs/sizing.py`; wind and clamp [H1] to [H6], fit [J1], mass [K1], [K2], cost [L1], [L2].
- Bill of materials: `bom/bom.csv`.
- Decisions: `docs/decisions/0003-design-for-construction.md` (HMN-DDR-003), with HMN-DDR-001 and HMN-DDR-002; open items in `docs/06-design-decisions.md` (HMN-DEC-001).
- Requirements: `docs/03-requirements.md` (HMN-REQ-001 v0.6).
- FieldNode core: its build plan FND-BLD-001 and drawing FND-DWG-001 Rev P3, in the FieldNode repo.

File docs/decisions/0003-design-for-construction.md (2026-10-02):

---
doc_id: HMN-DDR-003
title: HeatMap Node design for construction
project: HeatMap Node
doc_type: Design decision record
version: "0.2"
status: Draft
date: '2026-10-02'
author: Amish Chadha
license: CERN-OHL-S-2.0
revisions:
- version: "0.1"
  date: '2026-10-01'
  author: Amish Chadha
  change: Changes that make the concept physically buildable, with the reason for each; made under Amish's 2026-09-30 instruction to make the design physically buildable; open for his review
- version: "0.2"
  date: '2026-10-02'
  author: Amish Chadha
  change: "Accepted by Amish on 2026-10-02, with A1 as recommended"
---

# 0003: Design for construction

- **Date:** 2026-10-01
- **Status:** accepted. Amish, 2026-10-02: "i approve your recommendations for all 555 open decisions." This covers every change in Tables 1 and 2 and the item in Table 3 (A1), now decided as recommended and recorded in the design decisions register (HMN-DEC-001).

## Context

On 2026-09-30 Amish asked for every repo to get a prototype build plan that shows how each component is made and how it fits the next, with pictures, and wrote: "If you are realising that the design cannot be built as per concept, fix the design assumptions to match and be physically feasible as you draw the illustrations." The model of HMN-DDR-002 showed what HeatMap Node does but was a massing model: parts floated, overlapped or had no fixing, and the saddle and the pole adapter seated only one pole size. Checking the model with build123d (part overlaps, contacts and clearances) found the thirteen problems below.

The changes keep what the node does: the same sensors, globe, fan-aspirated shield, arm height and direction, sensor positions along the arm, FieldNode core and pole range. Nothing here changes the pitch or the safety case. Every change is in `cad/src/model.py`, which now builds every component separately and runs 399 constructability checks (`python cad/src/model.py --check`): no two parts share material, parts that must touch do touch, parts that must stay apart are at least the stated clearance apart, and poles of 60 and 200 mm touch both faces of each V. All 399 pass.

## Decision

*Table 1. Changes made to the model, the BOM and the calculations.*

| # | Problem in the concept | Change made | Why this way |
| --- | --- | --- | --- |
| P1 | The arm saddle was drawn as a five-sided tray 110 x 180 x 30 mm with a round cut that fits only a 114 mm pole. Its side walls would hit a larger pole, a sheet cannot be formed into a closed tray with a curved seat, and nothing showed how the pole bears on it. | A channel bent from one 3 mm 5052 sheet: a flat web 120 wide and 180 tall facing out, and top and bottom flanges 40 deep pointing at the pole. Each flange has a 120° V notch cut before bending, lined with 1.5 mm rubber edge trim; the pole bears on the trimmed V edges. | Two straight bends on a cut blank is the simplest shape a sheet can take. The V seats any pole from 60 to 200 mm, which a round seat cannot. The web is 120 mm (was 110) so a 200 mm pole still bears 5 mm inside the notch corners. |
| P2 | The arm butted against the saddle with no fixing. | Two arm cheeks (40 x 40 x 3 mm aluminium angle, 80 mm long): each flat leg is held to the web by two M6 button-head screws from inside the saddle; the arm sits between the upright legs, held by two M6 bolts through both cheeks and the arm, with an aluminium crush sleeve inside the tube at each bolt. | Every joint is face to face and bolted. The sleeves stop the 2 mm tube walls crushing when the bolts are tightened. Two bolts 20 mm apart carry the arm's weight moment as a couple. |
| P3 | The strap bands were drawn as rings round the pole that passed through the saddle. | Each band goes round the back of the pole, through two 3 x 16 mm slots in the web, 55 mm each side of centre, and across the web's front face, 70 mm above and below the arm, clear of the cheeks. | This is how a band holds a bracket to a pole; the buckle sits on the front where it can be reached. |
| P4 | The shield's three rods were drawn as solid bars through plates with no holes and nothing setting the gaps; two rods ran through the fan cowl. The only link to the arm was a 12 mm rod from the arm to the cowl lid, with no fixing. | Four M5 stainless rods on a 92 mm circle, 90° apart, clear of the cowl by 5 mm. Each ring plate is printed with four 10 mm bosses, 12 mm tall, that carry the plate above; acorn nuts below and nuts on the top plate clamp the stack. The two rods in line with the arm continue up through it on 41 mm aluminium spacers, with a nut on top of the arm. | The bosses set the 15 mm pitch with no loose spacers to lose. The rods in tension and the spacers in compression hold the stack rigidly 45 mm below the arm, as the concept placed it. |
| P5 | The fan floated 1 mm above the top plate and the cowl stood on four unfixed posts. | The fan sits flat on the top plate over its 56 mm hole. The printed cowl is a 76 mm lid on four legs that stand on the fan's corners; four M4 x 40 screws pass through lid, legs, fan and top plate, with nuts under the plate. | One set of screws holds fan and cowl. The cowl keeps its 76 mm lid and 30 mm height, so the exhaust and the wind area are unchanged. |
| P6 | The temperature and humidity capsule floated in the middle of the stack. | The third plate from the top is printed with a 22 mm hub on three 4 mm spokes; the capsule is a push fit in its 18.5 mm bore, held by a nylon M3 set screw, at the same height as before. | The capsule stays at the centre of the aspirated air path. Its lead leaves between the second and third plates (see P10). |
| P7 | The globe hung on a solid 12 mm rod that met the probe stem at the same point; the globe boss had no hole. | A hollow M10 x 1 brass threaded tube (lamp rod, 7 mm bore) screws into the globe's boss with a lock nut, passes through 10.5 mm holes in the arm and is held by a nut below and above the arm. The probe runs down inside the tube to the globe centre and leaves at its top. | The hanger and the probe share one path, as on a commercial globe thermometer. The globe stays 45 mm below the arm and its centre where the concept put it. |
| P8 | The anemometer mast stood on the arm top with no fixing. | The mast passes down through 16.5 mm holes in the arm, 30 mm from the tip, and is pinned by one M5 bolt through arm and mast. The arm is 530 mm (was 520) so the mast keeps its place after P1. | A through-mast cannot tip and the pin stops it turning. The cups now reach 668 mm from the pole axis (was 679 mm). |
| P9 | The arm tube had open ends. | A plastic plug in the tip; the root end bears on the web. | Keeps water, insects and nesting out of the tube. The appearance model already showed a plug. |
| P10 | The harness passed through the saddle, the fan, the pole and the FieldNode core. | Two leads from FieldNode ports A and B run under the core to the pole, up the pole 62 mm from its axis (outside both pairs of bands, held by long UV-stable cable ties), round the side of the saddle and along the arm's side. Lead A's tail enters the shield between the second and third plates to the sensor; lead B's tails go to the top of the globe hanger tube and into the foot of the anemometer mast. | Every cable now has a real path that clears every part by at least 0.5 mm. |
| P11 | The lanyards ended at the arm with nothing holding them. | Each lanyard is looped round the arm and closed with its snap hook: one from a hole in the top plate, one from the globe boss. | A loop round the arm backs up the rod and tube fixings; it does not depend on them. |
| P12 | The FieldNode pole adapter was drawn as flat blocks with a shallow round seat that fits one pole size, covering FieldNode's band slots, with no fixing. | Two printed ASA V-blocks 110 x 30 x 38 mm with a 120° V across the full width, two 3.5 x 16 mm band slots right through in line with the FieldNode back plate slots, and two M4 heat-set inserts at FieldNode's V-block screw holes, so FieldNode's own countersunk screws hold them. | The adapter now fits the FieldNode back plate of Rev P3 with no new holes in it, seats 60 to 200 mm poles, and lets FieldNode's band path work as designed. |
| P13 | The FieldNode envelope followed FND-DWG-001 Rev P1. | Updated to Rev P3 (FND-DDR-003): ports and antenna in the front row 55 mm from the box back, band slots and V-block screw holes in the back plate; the back plate is 3 mm nearer the pole with the new adapter. | Keeps the interfaces that the adapter and harness use the same as the FieldNode build plan. |

*Table 2. Knock-on changes.*

| Item | Change | Reason |
| --- | --- | --- |
| Mass | Sensor head 2.12 kg (was 1.91 kg), within R15's 4 kg [K1], [K2]. Complete node 4.95 kg for information, with FieldNode at 2.61 kg after its own design for construction. | Cheeks, bolts, a fourth rod, spacers, the brass hanger tube and nuts. |
| Cost | Lines 2, 4, 8, 10 and 12 repriced; sensor head $136.00 against the unchanged $130 value-engineering target, $6.00 over it [L1], [L2]. Line 1 follows FieldNode to $148.00 (counted against FieldNode). | Parts added for construction. `budget_usd` is a value-engineering target, not a limit (Amish, 2026-10-01). |
| Wind and clamp | Arm 530 mm: root moment 14.6 N·m, factor 13.0 on yield, tip 0.31 mm at 20 m/s; clamp twist factor 2.5 [H1] to [H5]. | Longer arm, 10 mm. |
| Drawing | HMN-DWG-001 Rev P4; making sketches HMN-DWG-101 to 107 added. | Follows the model. |
| Documents | HMN-CAL-001 v0.4, HMN-REQ-001 v0.6, HMN-PRC-001 v0.6. R13 is now reported against the value-engineering target; no other requirement changed status. | Follows the model. |

*Table 3. Proposed, then accepted by Amish as recommended on 2026-10-02.*

| # | Question | Options | Recommendation |
| --- | --- | --- | --- |
| A1 | The sensor hub's three 4 mm spokes sit in the aspirated air path, 15 mm above the sensing tip. HMN-CAL-001 does not include their effect on the 0.43 °C shield error. | (a) keep the hub on spokes and include it in the TRL 4 side-by-side shield test; (b) hang the capsule on its lead from a clip on the second plate, with no spokes. | (a): the hub ring and spokes block about 13 % of the 56 mm opening at that one plate, beyond what the capsule itself blocks; a lead-hung capsule can swing against the plates. **Decided 2026-10-02: (a).** |

## Consequences

- `design_state: constructable` in `project.yaml`. The build plan HMN-BLD-001 shows every component and step in pictures generated from the model (`cad/src/build_plan_media.py`).
- Requirement status: 1 not met (R9), 3 at risk (R5, R10, R14), 8 met on paper, 2 met by design, and R13 $6 over the value-engineering target (HMN-CAL-001 v0.4).
- The photoreal renders (`media/render-*.png`), `media/card.png` and `media/social-preview.png` and the appearance model `cad/src/product_model.py` still show the concept saddle, the three-rod shield and the solid globe rod. They need updating on Amish's Mac, where Blender is.
- The globe boss thread, the anemometer mast size, the fan's hole spacing and the capsule diameter are checked when the parts are bought; they are listed in the design decisions register (HMN-DEC-001).

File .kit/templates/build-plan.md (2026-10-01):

---
doc_id: PRJ-BLD-001
title: Project prototype build plan
project: Project name
doc_type: Build plan
version: "0.1"
status: Draft
date: YYYY-MM-DD
author: Amish Chadha
license: CERN-OHL-S-2.0
revisions:
  - version: "0.1"
    date: YYYY-MM-DD
    author: Amish Chadha
    change: First build plan; design made constructable
---

# Project prototype build plan

**Plan, not yet built.** How to build the first proof-of-concept prototype, component by component. Building and testing to it is TRL 4 work. Decisions still to be made are kept in the design decisions register (`docs/06-design-decisions.md`), not here.

## 1. What you are building

Every component, pulled apart and numbered in build order

One short paragraph: what the prototype is, how many components, which are made and which are bought, and the main ways they are made.

## 2. What changed to make it buildable

| Component | The concept had | The buildable design has | Why |
| --- | --- | --- | --- |

## 3. Making the components

### 3.1 Component name

Making sketch

**What it is and what it is made from.**

**How to make it.**

1. Mark out ...
2. Cut ...

**How it fits the parts next to it.**

Close-up of the joint

**Check before moving on.**

## 4. Putting it together

### Step 1: ...

Step 1

## 5. First checks

| Check | Requirement | How | Pass when |
| --- | --- | --- | --- |

## 6. Safety stops

## 7. Tools, skills and workspace

## 8. Where the numbers come from

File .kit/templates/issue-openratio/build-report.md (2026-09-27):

---
name: Build report
about: Tell us what happened when you built, printed or tested part of this design
title: "Build report: "
labels: build-report
---

This is a research and educational prototype, not a medical device. It is a TRL 3 concept and is not released for fabrication. If you build any part of it, you do so at your own risk. Reports help everyone.

**What you built** (part, sub-assembly or test)

**Materials, tools and settings**

**What worked**

**What did not work, with photos or measurements if you have them**

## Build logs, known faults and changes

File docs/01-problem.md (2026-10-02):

---
doc_id: HMN-PRB-001
title: HeatMap Node problem statement
project: HeatMap Node
doc_type: Problem statement
version: "0.6"
status: Draft
date: '2026-10-02'
author: Amish Chadha
license: CERN-OHL-S-2.0
revisions:
- version: "0.1"
  date: '2026-09-25'
  author: Amish Chadha
  change: Initial scaffold
- version: "0.2"
  date: '2026-09-25'
  author: Amish Chadha
  change: Populate to TRL 2 (problem, users, context, constraints, prior work, open questions)
- version: "0.3"
  date: '2026-09-25'
  author: Amish Chadha
  change: "TRL 3 update: budget scope and mounting height per HMN-DDR-001; operating environment aligned with HMN-CAL-001"
- version: "0.4"
  date: '2026-09-25'
  author: Amish Chadha
  change: Recommendations accepted by Amish (DDR-002)
- version: "0.5"
  date: '2026-09-26'
  author: Amish Chadha
  change: "Budget top-up approved by Amish: sensor head limit $130"
- version: "0.6"
  date: '2026-10-02'
  author: Amish Chadha
  change: "First partner city and data publisher decided by Amish on 2026-10-02; City of Phoenix Office of Heat Response and Mitigation named as the first candidate to approach"
---

# HeatMap Node problem statement

Cities decide where to plant trees, build shade and open cooling centers with heat data that is too coarse to see the street a person actually walks down. Heat kills in large numbers, it falls hardest on poorer and hotter neighborhoods, and the measure that matters for the body (heat stress, which includes sun and radiant heat from hot surfaces, not only air temperature) is rarely measured at street level at all.

## The problem

Heat is one of the deadliest weather hazards. WHO estimates about 489,000 heat-related deaths each year between 2000 and 2019, 45 % of them in Asia and 36 % in Europe ([WHO fact sheet](https://www.who.int/news-room/fact-sheets/detail/climate-change-heat-and-health)). In the summer of 2022 alone an estimated 61,672 people died of heat in 35 European countries ([Ballester et al., *Nature Medicine*, 2023](https://www.nature.com/articles/s41591-023-02419-z)).

Heat is not spread evenly across a city. The US EPA reports that daytime air temperatures in urban areas run about 1 to 7 °F (about 0.5 to 4 °C) above outlying areas, and nighttime temperatures about 2 to 5 °F (about 1 to 3 °C) higher ([US EPA](https://www.epa.gov/heatislands/learn-about-heat-islands)). Inside cities the differences follow income and history: land surface temperatures in formerly redlined US neighborhoods are about 2.6 °C higher than in other neighborhoods, and up to 7 °C higher in some cities ([Hoffman et al., *Climate*, 2020](https://www.mdpi.com/2225-1154/8/1/12)). WHO notes that informal settlements are often hotter than other urban areas ([WHO fact sheet](https://www.who.int/news-room/fact-sheets/detail/climate-change-heat-and-health)).

Three gaps keep cities from acting on this at block scale:

1. **Official stations are sparse and sited away from streets.** Weather stations are placed in open, grassy sites by design, so they report the background climate, not the hot bus stop or market lane.
2. **Satellites see surfaces, not people.** Land surface temperature maps show hot roofs and roads, but the heat a pedestrian feels depends on air temperature, humidity, wind and radiant heat together.
3. **Air temperature alone understates heat stress in the sun.** The standard occupational index, wet bulb globe temperature (WBGT, [ISO 7243:2017](https://www.iso.org/standard/67188.html)), weights a black globe temperature and a natural wet-bulb temperature because sun and humidity drive heat strain. Low-cost street sensors seldom include a globe.

## Users and context

| User | What they need from the data |
| --- | --- |
| City heat, climate or resilience officer | Block-level maps of heat stress over a season to target trees, shade (see CoolShade), cool surfaces and cooling centers, and to check whether they worked |
| Public health department | Near-real-time heat stress by neighborhood during heat waves, to direct outreach to people at risk |
| Community groups and schools | A node they can build, host and read, and open data they can take to city hall |
| Outdoor employers (construction, delivery, markets) | Local WBGT estimates to set work and rest cycles |
| Researchers | A documented, calibrated, repeatable street-level method that others can replicate |

### Operating environment

- **Mounting:** existing street light, sign or utility poles (60 to 200 mm in diameter), with the asset owner's permission, with the sensor arm at about 2.8 m above the pavement (HMN-DDR-001 D2), pointing toward the equator where the street allows (HMN-DDR-002). HMN-CAL-001 estimates that on a sunny afternoon the air at pedestrian height is 0.2 to 0.8 °C warmer than at the sensors.
- **Climate:** air temperature from about -20 to +50 °C at the node (R8, restated to match under HMN-DDR-002), full sun, rain, dust and salt air near coasts; black globe temperatures can exceed 60 °C in full sun (estimate).
- **Connectivity:** LoRaWAN coverage from a community gateway (for example the lab's TwinKit gateway) or a public network; no mains power at the node.
- **Density:** tens of nodes per neighborhood, so each must be cheap, quick to fit and self-powered.

## Constraints

- Garage-buildable prototype, $130 USD or less for the HeatMap-specific sensor head (raised from $120 by a budget top-up Amish approved on 2026-09-26). The FieldNode core, its sun shield and the pole adapter that seats it on street poles are counted against FieldNode, a shared lab component costed and budgeted in its own repo (HMN-DDR-001 D1 and HMN-DDR-002, decided by Amish on 2026-09-25). HMN-CAL-001 v0.3 prices the head at $127 with the aspiration fan, within this limit.
- Built on the FieldNode core (enclosure, solar, battery, LoRaWAN radio) so that no power or radio design is repeated.
- Privacy: environmental measurements only. No camera, microphone or device tracking.
- No drilling of poles; fit with stainless band clamps.
- Open hardware (CERN-OHL-S-2.0) and open software (MIT); data in an open format.

## Out of scope

- Personal heat stress for an individual (wearables) and indoor heat.
- Issuing official heat warnings. The node supplies data; public warnings stay with the responsible agency.
- Air quality, noise and traffic, which are covered by the AirStreet, NoiseMap and CurbCount concepts.

## Prior work

- **WBGT standard and models.** ISO 7243:2017 defines WBGT as a screening index for heat stress ([ISO](https://www.iso.org/standard/67188.html)). Liljegren and colleagues showed how to estimate WBGT from standard weather measurements, including globe temperature and wind speed ([Liljegren et al., *J. Occup. Environ. Hyg.*, 2008](https://doi.org/10.1080/15459620802310770)); an open implementation of their code is available ([wbgt package](https://github.com/mdljts/wbgt)). HeatMap Node measures the inputs this model needs.
- **Heat and equity studies.** Satellite studies across 175 large US urbanized areas found that the average person of color lives in a census tract with higher surface urban heat island intensity than non-Hispanic white residents in all but 6 of them ([Hsu et al., *Nature Communications*, 2021](https://www.nature.com/articles/s41467-021-22799-5)). These studies use surface temperature; HeatMap Node adds what people experience at street level.
- **Mobile heat campaigns.** Some cities map heat on a single hot day with vehicle-mounted or hand-held sensors. These give good spatial detail but not the season-long, day-and-night record that fixed nodes give.
- **Lab components.** FieldNode (shared outdoor core), CalRig (sensor calibration chamber) and TwinKit (gateway and data layer) are sibling concepts in this lab. CoolShade is the lab's shade structure concept that HeatMap data is meant to help site.

## Open questions

- Which city or community partner hosts the first network, and on whose poles? Decided 2026-10-02: a hot US city with a dedicated heat office; the first candidate to approach is the City of Phoenix Office of Heat Response and Mitigation, using the US915 band. Nothing is agreed, and whose poles is still to be settled with the city (HMN-DEC-001).
- What mounting height is acceptable to pole owners? HMN-CAL-001 gives a first estimate of the height error (up to about 0.8 °C in strong sun); a field comparison of 2.0 and 2.8 m is still needed.
- Which output do users want most: air temperature, WBGT, mean radiant temperature, or a simple heat stress category?
- Who owns and publishes the data? Decided 2026-10-02: Amish's lab publishes it under an open licence from CityTwin's open data export until the partner city takes it over (HMN-DEC-001).

## User research and co-design

This design is for communities the author is not part of, so requirements come from the people who will use it.

- [ ] Identify a local partner organization (Helpful Engineering network, NGO or university)
- [ ] Run co-design sessions with intended users; record who, where and what was learned
- [ ] Validate load, distance, terrain and cost assumptions in the field
- [ ] Revise requirements (REQ) from findings before freezing the design

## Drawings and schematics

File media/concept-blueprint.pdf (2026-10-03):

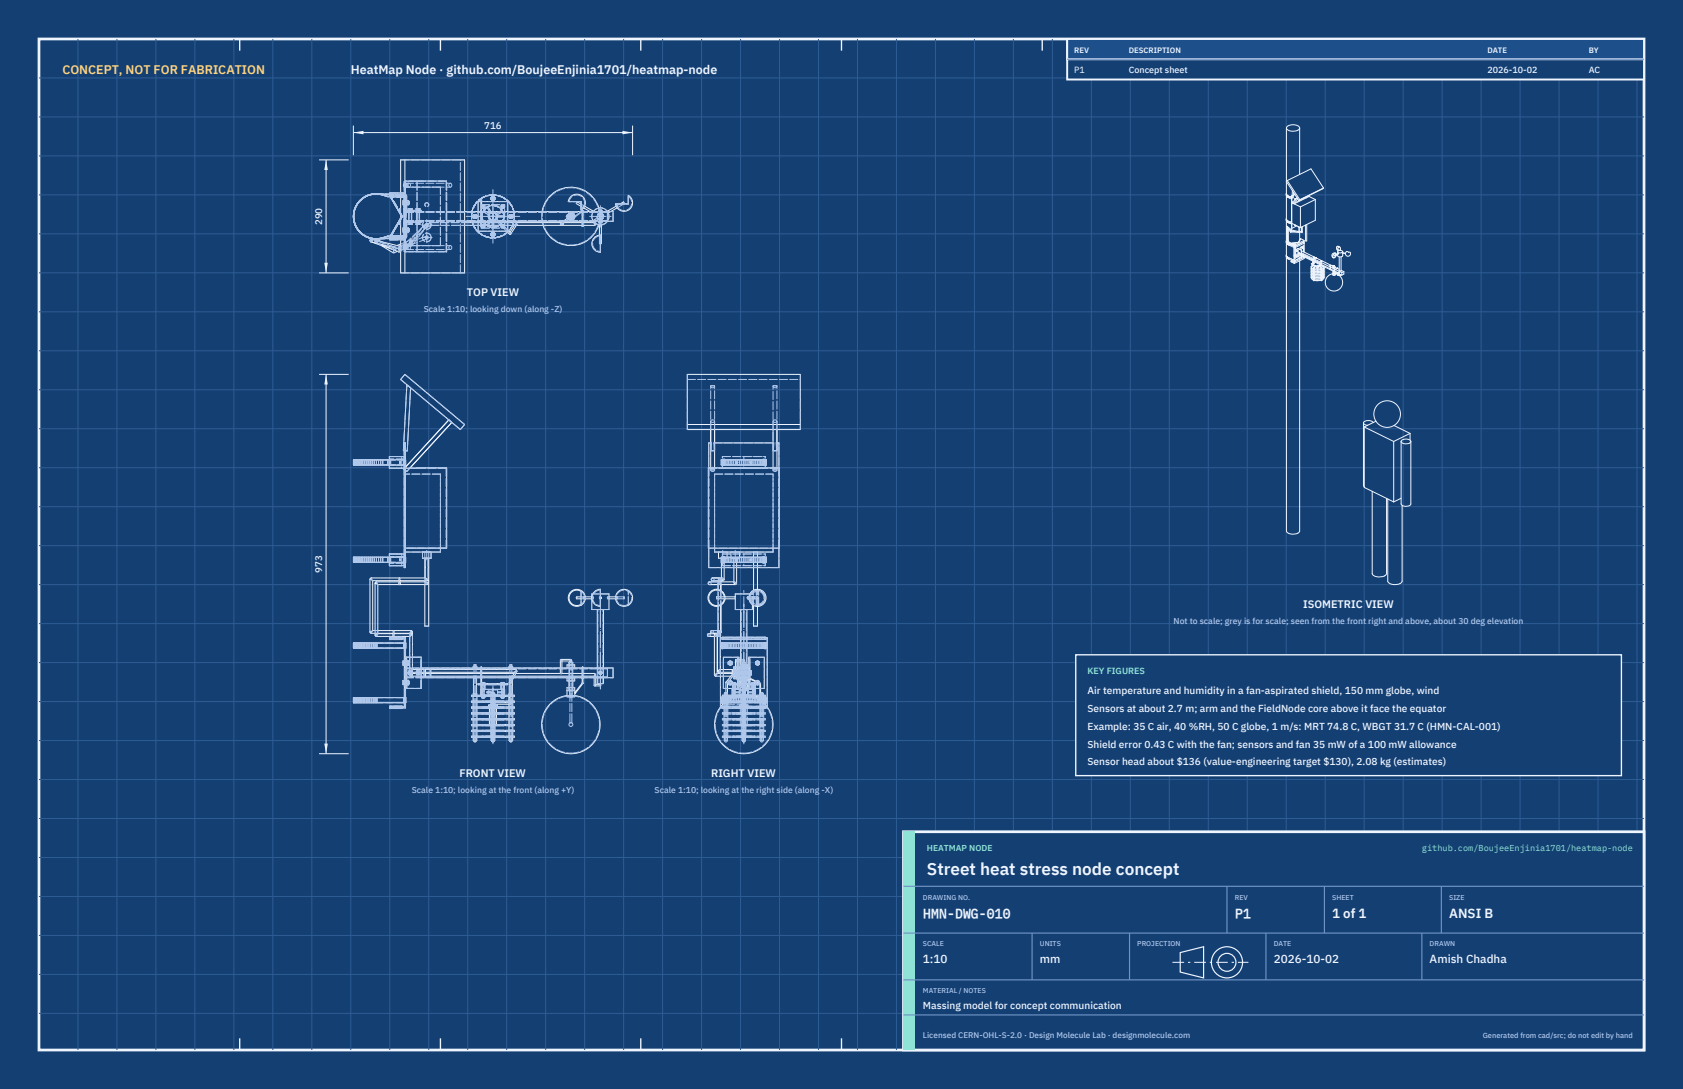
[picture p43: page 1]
CONCEPT, NOT FOR FABRICATION; HeatMap Node · github.com/BoujeeEnjinia1701/heatmap-node; FRONT VIEW; TOP VIEW; RIGHT VIEW; ISOMETRIC VIEW; REV; DESCRIPTION; DATE; Concept sheet; HEATMAP NODE; github.com/BoujeeEnjinia1701/heatmap-node; DRAWING NO. HMN-DWG-010; REV P1; SHEET 1 of 1; SIZE ANSI B; SCALE 1:10; UNITS mm; PROJECTION; DRAWN Amish Chadha; Licensed CERN-OHL-S-2.0 · Design Molecule Lab · designmolecule.com; Generated from cad/src; do not edit by hand

Scale 1:10; looking down (along -Z)

Not to scale; grey is for scale; seen from the front right and above, about 30 deg elevation

KEY FIGURES
Air temperature and humidity in a fan-aspirated shield, 150 mm globe, wind
Sensors at about 2.7 m; arm and the FieldNode core above it face the equator
Example: 35 C air, 40 %RH, 50 C globe, 1 m/s: MRT 74.8 C, WBGT 31.7 C (HMN-CAL-001)
Shield error 0.43 C with the fan; sensors and fan 35 mW of a 100 mW allowance
Sensor head about $136 (value-engineering target $130), 2.08 kg (estimates)

Scale 1:10; looking at the front (along +Y)

Scale 1:10; looking at the right side (along -X)

Street heat stress node concept

MATERIAL / NOTES
Massing model for concept communication

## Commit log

2026-09-25 Initial scaffold: standard open hardware layout, CERN-OHL-S v2 + MIT licenses
    Claude-Session: https://claude.ai/code/session_01XuhhSU4W6fYhgCfURbrkut
    [bom.csv]
2026-09-26 Populate to TRL 2: problem, requirements, precis, concept media, BOM and README use cases
    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
    [bom.csv]
2026-09-26 Advance to TRL 3: DDR-001, CAL-001 sizing, parametric model with STEP/STL, GA drawing, priced BOM; TRL 4 on hold
    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
    [bom.csv, fieldnode-core-envelope.step, fieldnode-core-envelope.stl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]
2026-09-26 Accept all recommendations (DDR-002), switch footer to designmolecule.com, add README write-up with new inspiration point
    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
    [bom.csv, fieldnode-core-envelope.step, fieldnode-core-envelope.stl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]
2026-09-27 Product appearance model and photoreal renders
    Adds cad/src/product_model.py (appearance model for renders only, all main
    dimensions from model.py) and Blender renders in media/render-*.png,
    captioned with the project, repository and viewing direction. README leads
    with the product render; trl stays 3.
    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
2026-10-01 Image quality pass: legible exploded views, flow diagrams and drawing sheets
    Kit 1.6.1 image layout: the parts list sits in its own column, number bubbles sit on visible parts and never overlap, small parts get a leader, pictures are cropped to the subject, flow labels keep numbers with their units, and sheet captions and the revision table no longer overprint. Concept images, blueprint and general arrangement sheet regenerated; repo-specific labels moved clear of other text and lines.
2026-10-01 Kit 1.7.0: constructable design, illustrated build plan and design decisions register
    The design is now constructable: every part can be made and fits its neighbours, with each change recorded in a Design for construction decision record (made under Amish's 2026-09-30 instruction; ope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
    FlexHand also credits Dr. Geeti Chadha as a contribut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
    [bom.csv, fieldnode-core-envelope.step, fieldnode-core-envelope.stl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]
2026-10-02 Record Amish's approval of the open-decision recommendations
    Amish approved the recommendation on every open decision in the design decisions register ("i approve your recommendations for all 555 open decisions.", 2026-10-02). Each decision is moved to Decisio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
2026-10-03 Carry approved follow-ups into the design and redo photoreal renders
    Amish approved the follow-up actions from the open-decision sign-off ("APPROVED CHANGES, COMPLETE THESE", 2026-10-02), the design-for-construction change tables in ten repos, the last wave's open dec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
    [bom.csv, fieldnode-core-envelope.step, fieldnode-core-envelope.stl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]
2026-11-05 Kit 1.9.1 upgrade: pipeline documents and detailed CAD for every option
    STEM check with fixes under the standing instruction and an independent
    review, concept options scored against the user requirements, URS, PRS,
    RTM, REG, FEA, RSK, MKT, PLN and DDR, every option modelled at D3 with
    cad/fidelity.json passing, and the concept options picture rendered with
    Blender Cycles on Amish's Mac. Concept choices stay proposed, awaiting
    Amish.
    Claude-Session: https://claude.ai/code/session_01LppsZSzPTJWTBAV5wh1Goq
